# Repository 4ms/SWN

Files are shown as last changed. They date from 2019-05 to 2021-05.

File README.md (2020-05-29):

# Spherical Wavetable Navigator

Firmware for the Spherical Wavetable Navigator, a Eurorack-format module from 4ms Company.

## Setting up the gcc-arm toolchain
You need to install the GCC ARM toolchain.
This project is known to compile with arm-none-eabi-gcc version 8.2.1 (8-2019q4) and 7.3.1 (7-2018q2).

If you're new to embedded development and not comfortable on the command line, you may wish to install an IDE. ST has an official IDE based on Eclipse called [STM32CubeIDE](https://www.st.com/en/development-tools/stm32cubeide.html). Or you can roll-your-own Eclipse using [GCC ARM with Eclipse](https://gnu-mcu-eclipse.github.io/). There are also commerical software packages which can be easily found by searching.

Another option is to use a fully-featured text editor such as VSCode or Sublime Text. You can configure these to run commands to compile and flash/program your project onto your SWN, too. There are ARM debugging extensions available, too. On the other hand, if you're happiest using the command line and prefer to write code with vim, emacs, etc, you can also do everything without having to lift your hand from the keyboard except to twiddle knobs on the SWN.

### Using the Virtual Machine ###

4ms has a virtual machine that provides a consistant development environment for compiling. Check out this project and follow the instructions in its README: [4ms-dev-env](https://github.com/4ms/4ms-dev-env). The SWN repo comes pre-cloned when you start this virtual machine.

First, follow the instructions on [vagrant's site](https://www.vagrantup.com/intro/getting-started) to install vagrant and VirtualBox.

Then, building the SWN project is as simple as this:

```
git clone https://github.com/4ms/4ms-dev-env.git
cd 4ms-dev-env
vagrant up
vagrant ssh
cd SWN
make
```

At present, the 4ms-dev-env is only setup to compile, not to flash (program), or debug.
If you decide to use the virtual machine to compile, you'll still need to use your local system to program the compiled code onto SWN. Skip down to the **Programmer** section.

### Mac OSX using Brew ###

For Mac OSX, you can use brew to install the gcc-arm toolchain.
First, install brew if you haven't already:
```
ruby -e "$(curl -fsSL https://raw.githubusercontent.com/Homebrew/install/master/install)"
```

Then, install the gcc-arm toolchain v7.3.1:

```
brew tap nitsky/stm32
brew install arm-none-eabi-gcc
```

Continue below to **Clone the Projects**

Alternatively, you can follow the _Linux orMac OSX_ instructions below to get v8.2.1.

### Linux or Mac OSX ###

For Linux or Mac OSX, download GNU ARM Embedded Toolchain version 8-2018-q4-major from [Launchpad](https://launchpad.net/gcc-arm-embedded/+download).

Direct links: [Mac OSX gcc-arm 8.2.1](https://developer.arm.com/-/media/Files/downloads/gnu-rm/8-2018q4/gcc-arm-none-eabi-8-2018-q4-major-mac.tar.bz2) ... [Linux gcc-arm 8.2.1](https://developer.arm.com/-/media/Files/downloads/gnu-rm/8-2018q4/gcc-arm-none-eabi-8-2018-q4-major-linux.tar.bz2).

Then unzip them: Double-clicking them on MacOS might work, or type this:

```
cd ~/Downloads ##whatever your download directory is
tar jxf gcc-arm-none-eabi-8-2018-q4-major-*.tar.bz2
```

Next, move the unzipped directory to somewhere sensible and add the `bin/` dir to your PATH:

```
mv gcc-arm-none-eabi-8-2018-q4-major $HOME/myprojectdir
echo "export PATH=$HOME/myprojectdir/gcc-arm-none-eabi-8-2018-q4-major/bin:\$PATH" >> $HOME/.bash_profile
source $HOME/.bash_profile

```

Of course, modify the above with the actual directory you want to put the toolchain, and your shell start-up script if you're using zsh or something else.

Continue below to **Clone the Projects**

### Windows
Download the GNU ARM Embedded Toolchain version 8-2018-q4-major from [Launchpad](https://launchpad.net/gcc-arm-embedded/+download). Download the Installer for your Windows verion (don't download the .zip file, download the .exe file).

Run the installer, and continue below.

## Clone the Project ##

If you are using the virtual machine, this will already be cloned for you, so skip ahead.

Make sure git is installed on your system. (OSX: type "brew install git" into the Terminal).

Create a work directory, and enter it:
 
	mkdir myhackdir && cd myhackdir

Clone the SWN repository:

	git clone https://github.com/4ms/SWN.git  
	cd SWN

## Compiling ##
Make your changes to the code in the SWN directory. When ready to compile, make the project like this:

	make
	
This creates an main.elf, main.bin, and main.hex file in the build/ directory. See the Programmer section below for how to get these files onto your SWN.

## Programmer (Hardware) ##

Once you compile your firmware, you need to flash it to your SWN. You will need a hardware device that connects to your computer's USB port. The other side of the programmer has a header that conencts to the SWN's 4-pin SWD header.

You have several options:

### Option 1) ST-LINKv2 programmer ###

The [ST-LINK v2 from ST corporation](http://www.mouser.com/search/ProductDetail.aspx?R=0virtualkey0virtualkeyST-LINK-V2) is the offical programmer from ST (who makes the chip that needs programming). The ST-LINK v2 has a 20-pin JTAG header, and you need to connect four of these to your SWN. More details on this are below.

The ST-LINKv2 programmer can be used with ST-LINK software for Mac, Linux, or Windows; or ST-UTIL software for Windows; or STM32CubeProgrammer software for any platform. 

### Option 2) Discovery board programmer ###

The [STM32 Discovery boards](http://www.mouser.com/search/ProductDetail.aspx?R=0virtualkey0virtualkeySTM32F407G-DISC1) are low-cost (around US$25) and work great as a programmer and debugger. The 'Disco' board is essentially an ST-LINKv2, plus some extra stuff. While the ST-LINK v2 is encased in a plastic enclosure, the Discovery board is open and could potentially be damaged if you're not careful. Read the Discovery board's manual to learn about setting the jumpers to use it as an SWD programmer (rather than an evaluation board). ST makes many variations of the Discovery board, and to my knowledge they all contain an ST-LINK programmer.

The Discovery board programmer is essentially an ST-LINKv2, so it can be used with all the same software that the ST-LINKv2 can (see above section).

### Option 3) SEGGER's J-Link or J-Trace ###

Another option is [SEGGER's J-link programmer](https://www.segger.com/jlink-debug-probes.html). There is an educational version which is very affordable and a good choice for a programmer if you meet the requirements for education use. There are various professional commercial versions with a number of useful features. The J-link uses SEGGER's propriety software, Ozone, which not only will flash a hex or bin file, but can be used as a powerful GUI debugger if you use it to open the .elf file. There also are command-line commands for flashing.
J-Link software runs on Mac, Linux, and Windows.

### Option 4) Audio Bootloader ###

The SWN has an audio bootloader built-in, so you can just compile your project using `make wav` and then play the wav file into the audio input of the SWN while in bootloader mode (see SWN User Manual for detailed procedure). No additional hardware or software is necessary.

This works well and is the safest option. However it's very slow (up to 5 minutes per update, or 11+ minutes if you include all new factory wavetables). If you are going to be making a series of changes, this will be a very slow process!

When ready to build an audio file for the bootloader, make it like this:

	make wav

This requires python to run. It creates the file `main.wav` in the `build/` directory. Play the file from a computer or device into the SWN by following the instructions in the User Manual on the [4ms SWN page](http://4mscompany.com/SWN). 

## Programmer (Software)

Depending on the hardware you chose, one or more of the following software options will work:

### ST-LINK ###

This software works with the ST-LINK v2 and the Discovery board to flash your SWN.

__MacOS:__

```
brew install stlink
```

__Linux:__

Use your package manager to install `stlink-tools`. See [stlink README](https://github.com/stlink-org/stlink) for direct links.

__Windows:__

Download the [latest binary (v1.3.0)](https://github.com/stlink-org/stlink/releases/download/v1.3.0/stlink-1.3.0-win64.zip). If that link doesn't work anymore, or you want to try a newer version, go to [stlink-org/stlink github page](https://github.com/stlink-org/stlink).

__Programming using st-link__

You can flash the compiled .bin file by typing:

	st-flash write build/main.bin 0x08010000
	
This writes the main.bin file starting at the 0x08010000 sector, which is the first sector of the application code.

__Debugging__

The gcc-arm toolchain includes a gdb debugger, but you'll need a server to use it. The st-link software includes st-util which will provide this. OpenOCD and J-link are two other options. Configuring debugging is beyond the scope of this README, but there are plenty of tutorials online. See the [stlink README](https://github.com/stlink-org/stlink) for a quick start.

### J-Link/Ozone ###

If you're using a J-Link or J-Trace hardware programmer to flash your SWN, download and install [Ozone](https://www.segger.com/downloads/jlink). Ozone is a GUI debugger which can program, too. For command-line options, consider [J-Link Software and Documentation Pack](https://www.segger.com/j-link-software.html), which contains the GDB server and other tools.

To program your SWN, open Ozone and then use the Project Wizard to create a new project. Select the STM32F765ZG for the chip. Use the default settings elsewhere. On the page that lets you select a file, select the main.elf file that you compiled. You can then save this project. To program, just click the green power/arrow symbol at the upper left.

You also can use the CLI tools to flash the hex/elf file, see J-Link documentation for details.

J-Link and Ozone is available for Mac, Windows, and Linux.

### STM32CubeProgrammer ###

The STM32CubeProgrammer is ST's official programaming software available for all platforms. [You can find it here](https://www.st.com/en/development-tools/stm32cubeprog.html)

Documentation is included with the download.

### ST-UTIL (Windows only) ###

ST-UTIL is a program from ST that runs on Windows only. You can find it on [ST.com](https://my.st.com/content/my_st_com/en/products/development-tools/software-development-tools/stm32-software-development-tools/stm32-programmers/stsw-link004.html)

It works with the ST-LINKv2 and Discovery boards.

## Connecting the programmer to the SWN ##

**Discovery Board**: The Discovery board has a 6-pin SWD header, and you can connect that pin-for-pin to the first 4 pins on the SWN's SWD header. You can use a 0.1" spaced 4-pin Jumper Wire such as [this one from Sparkfun](https://www.sparkfun.com/products/10364). Pay attention to Pin 1 (marked by "1" on the SWN board), or you risk damaging the ARM chip.

**ST-LINK v2 or SEGGER J-Link**: Both the ST-LINK and the SEGGER J-link have a 20-pin JTAG connector. You need to connect 4 of these pins to the SWN's 4-pin SWD connector, using 4 wires: [here's a pack of 10](https://www.sparkfun.com/products/8430). Pay attention to Pin 1 (marked by "1" on the SWN board), or you risk damaging the ARM chip.
 
Look at these images:
 
  * JTAG: [20-pin pinout](http://www.jtagtest.com/pinouts/arm20)
  * SWD: [6-pin pinout](https://wiki.paparazziuav.org/wiki/File:Swd_header_discovery_board.png)
  * JTAG-to-SWD: [JTAG-to-SWD-pinout](https://4mscompany.com/JTAG-to-SWD-pinout.png). 

Then use your jumper wires to connect:
 
  * SWD pin 1 (VDD) -> JTAG pin 1 (VREF)
  * SWD pin 2 (SWCLK) -> JTAG pin 9 (TCK)
  * SWD pin 3 (GND) -> JTAG pin 4 (GND)
  * SWD pin 4 (SWDIO) -> JTAG pin 7 (TMS)

Here's more info in case you want it explained in another way:

  * [This image](https://www.alexwhittemore.com/wp-content/uploads/2014/08/schematic.jpg) draws this out. (Taken from [this post](https://www.alexwhittemore.com/st-linkv2-swd-jtag-adapter/))
  * [ST's manual](http://www.st.com/content/ccc/resource/technical/document/user_manual/70/fe/4a/3f/e7/e1/4f/7d/DM00039084.pdf/files/DM00039084.pdf/jcr:content/translations/en.DM00039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)
  * [How to make an adaptor](http://gnuarmeclipse.github.io/developer/j-link-stm32-boards/#the-st-6-pin-swd-connector)
  * Make your own adaptor from these gerber files: [JTAG-SWD-adaptor](https://github.com/4ms/pcb-JTAG-SWD-adaptor).

## Bootloader Information ##

The bootloader is in a folder called `bootloader/`.
It's based on the stm-audio-bootloader from [pichenettes](https://github.com/pichenettes/eurorack). 

The bootloader is already installed on all factory-built SWN, so you don't need to mess with this project if you're just planning on modifying your SWN code. The bootloader allows you to replace the firmware by playing a compiled audio file into the Waveform In jack.

Doing `make` from within the `bootloader/` directory will build the bootloader and also use the main SWN app's `main.hex` file to create a combined hex file. This file is a complete flash dump of a factory SWN. After building the SWN first, and then the bootloader, the file will be in `SWN/bootloader/build/bootloader-app-combo/`. There is a hex and a bin version in that folder.

__Oops, I overwrote the bootloader and now it won't boot...__

The bootloader lives at 0x08000000, so if you overwrite that sector you will overwrite the bootloader. And then it won't boot. The best way is to re-flash the bootloader. Do this:

	st-flash write bootloader/build/bootloader-app-combo/SWN_combo.bin 0x08000000
	
Or if the combo is not working, you could try just the bootloader:

	st-flash write bootloader/build/bootloader/bootloader.bin 0x08000000

## License ##

The code (software) is licensed by the MIT license.

The hardware is licensed by the [CC BY-NC-SA license](https://creativecommons.org/licenses/by-nc-sa/4.0/) (Creative Commons, Attribution, NonCommercial, ShareAlike).

See LICENSE file.

I would like to see others build and modify the SWN and SWN-influenced works, in a non-commercial manner. My intent is not to limit the educational use nor to prevent people buying hardware components/PCBs collectively in a group. If you have any questions regarding the license or appropriate use, please do not hesitate to contact me! 

## Guidelines for derivative works ##

Do not include the text "4ms" or "4ms Company" or the graphic 4ms logo on any derivative works. This includes faceplates, enclosures, PCBs, and front-panels. It's OK (but not required) to include the text "Spherical Wavetable Navigator" or "SWN" if you wish.

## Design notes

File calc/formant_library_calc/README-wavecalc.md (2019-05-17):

#formant-library-calc
## Formant calculator for wavetables
Authors: Hugo Paris hugoplho@gmail.com, Dan Green danngreen1@gmail.com

Coefficients from:
HTML Csound Manual - © Jean Piché & Peter J. Nix, 1994-97 

https://www.classes.cs.uchicago.edu/archive/1999/spring/CS295/Computing_Resources/Csound/CsManual3.48b1.HTML/Appendices/table3.html

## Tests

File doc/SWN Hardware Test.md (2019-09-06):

#SWN Hardware Test
March 1, 2019

###Preparation

####Enter Hardware Test mode:

   1. If module has never passed the hardware test, it will automatically enter this mode until it passes.
   2. If it’s already passed, then hold down Button D + Transpose + LFO Shape while powering on.

####Prepare Scope:

* ⅛” tester cable
* “Normal” Time Mode (Horiz button)
* Horizontal: 2ms/div
* Channel’s Vertical: 5V/div
* Auto Trigger on the tester cable’s channel
* Trigger threshold at 50%
* Measurement enabled for Frequency and Amplitude

Prepare speakers/headphone to listen to what’s being scoped.

###Slider LED Test
1. Press center rotary to test each slider LED, one a at time. After the sixth press, all six sliders turn on at the same time.
2. Verify brightness/color.
3. Push the sliders to center now (you’ll see why in the Controls test).
4. Press rotary again to go to next test.

Note: It’s OK if the rest of the RGB lights are partially on/off: they don’t get tested until the next step.

_Fail_: "Slider LED" if a slider LED does not turn on or is always on, or two slider LEDs turn on at the same time. 

_Fail_: "Slider LED discolored" if a slider LED is substantially different hue than other slider LEDs.

###RGB LED Test

####Part 1: PCA I2C check
SWN automatically performs PCA chip communication test on I2C bus.

_Fail_: “PCA I2C Timeout”, if sliders E and F blink and sliders A/B/C/D show binary code for chip# that failed. Record fail and press rotary to continue. Otherwise, it automatically goes to Part 2.

####Part 2: All LEDs check
All light pipes, buttons, and rotary LEDs will turn white (Clock In LED will be blue and LFO buttons will be pink-ish).

_Fail_: “LED out”, if an LED is not white, or excessively dim or bright.

If it detects an error, it will automatically go to Part 3. Otherwise, you must make a choice here: 

  * If the lights definitely look good, the press the rotary to skip to Controls Test. 
  * If you want to double-check an LED individually, hold the rotary for 3 seconds unti the sliders flicker. Then release to go to Part 3 (individual LED test). 

####Part 3: Individual LED test (optional): 
Spin center rotary or Preset rotary to select one LED at a time to turn on. Each Red/Green/Blue is turned on separately.

_Fail_: “LED out/LEDs shorted”: If there’s any point in time when there are no LEDs on, or there are more than one LEDs on (including any color other than pure red, pure green, or pure blue). Note that you can use either the Preset rotary or the center rotary: you may not be able to conduct this test if there are issues with both of these rotaries. 
Press center rotary to continue to next test.

###Controls Test (rotaries, sliders, buttons, switches)

Staring state:

* Channel buttons are white (might be cyan or magenta if a slider is not centered)
* LFO buttons are blue
* LFO LEDs and LFO CV LED are white
* LED encoders are white

The goal is to turn all the lights off by pushing every button, turning every knob, moving every slider, and flipping the switch.

1. Slide each slider up and down fully:
   * Slider light should turn on when slider is >50% up (40-60% is ok)
   * Slider light should turn off when slider is <50% up (40-60% is ok)
   * Button above slider turns its red off when slider hits 100% (white=>cyan)
   * Button above slider turns its green off when slider hits 0% (cyan=>blue)

1. All 8 buttons should be blue now. Press each button to turn the blue color off.
2. For each rotary:
   - Each Rotary has an LED associated with it:
      * Octave: LFO LED B
      * LFO Speed: LFO LED A
      * Preset: LFO LED C
      * Depth: Depth (itself)
      * Center: LFO LED D
      * Latitude: Latitude (itself)
      * Longitude: Longitude (itself)
      * LFO Shape: LFO LED F
      * Transpose: LFO LED E
   - Turn it up and the light will turn cyan
   - Turn it down and the light will turn blue
   - Push its button and the light will turn off
   - While turning, watch light ring to make sure it’s not skipping steps
3. Press Fine to turn off the red color of the LFO CV LED (white=>cyan)
4. Flip V/oct switch up to turn off the green color of the LFO CV LED (cyan=>blue)
5. Flip V/oct switch down to turn off the blue color of the LFO CV LED (blue=>off)
6. Verify all lights are off.

  - _Fail_ “Rotary skipping” if light ring animation skips around when turning rotary.
  - _Fail_ “Rotary not responding to turning” if a rotary’s light is staying on any color except pure blue.
  - _Fail_ “Button not responding” if a button or rotary’s light is staying on pure blue.
  - _Fail_ “Fine button not responding” if LFO CV LED won’t turn off its red color
  - _Fail_ “Voct Switch stuck high/low” if LFO CV LED won’t turn off its blue/green color
  - _Fail_ “Slider not reaching max/min” if channel button won’t turn off its red or green color
  - _Fail_ “Slider voltage issue” if slider doesn’t turn on/off at about 50%
  - _Fail_ “Button/Rotary/Switch/Slider shorted” if multiple things happen when you adjust one control.

Hold down center rotary 3 seconds to proceed to next test. Sliders will flicker when it’s ok to let go

###Codec Communication Test
Automatic test (no user input required unless there’s a problem):

1. Waveform In LED turns blue while it tests the SAI initialization.
   - _Fail_ “Codec SAI error”, if slider F blinks quickly and Waveform LED is blue.
2. Waveform In LED turns red while it tests the I2C initialization.
3. Waveform In LED turns green while it tests the I2C communication.
  - _Fail_ “Codec I2C init error” if slider E blinks slowly and Waveform LED is green.
  - _Fail_ “Codec I2C register error”, if slider E blinks quickly and Waveform LED is green.

4. If there's an error, press rotary to continue, otherwise it automatically goes to next test.

###Outputs Test: Audio and LFOs

LFO LEDs will be Red/Green/Blue/Yellow/Cyan/Magenta

1. Patch scope and speakers into each Env jack and verify (approximate semi-tones):
   * Env A outputs a 248Hz left-leaning triangle, 7.2V amplitude.
   * Env B outputs a 257Hz left-leaning triangle, 7.2V amplitude.
   * Env C outputs a 287Hz left-leaning triangle, 7.2V amplitude.
   * Env D outputs a 313Hz left-leaning triangle, 6.8V amplitude.
   * Env E outputs a 342Hz left-leaning triangle, 6.8V amplitude.
   * Env F outputs a 360Hz left-leaning triangle, 6.6V amplitude.

2. Patch scope and speakers to Right OUT jack output. Scope should be measuring Freq and Amplitude.
3. Should see ~100Hz triangle with faster rise than fall (left-leaning). Amplitude = about 10V
  - _Fail_ “Audio Out amplitude too high/low” if amplitude is over/under 9.5V or 10.5V (or clipping)
  - _Fail_ “Audio OUT frequency” if wave is not between 99Hz and 101Hz,
  - _Fail_ “Audio OUT noisy/distorted” if you see noise or its distorted.
  - _Fail_ “Audio OUT DC offset” if wave is not centered around 0V.
  - _Fail_ “Audio OUT inverted” if wave is right-leaning

4. Patch a dummy cable into Left OUT jack. Immediately audio should go silent. This is because the normalization between Left and Right OUT jacks is broken by pluggin into the Left jack.
  - _Fail_ “Audio jack normalization issue” if right out jack is not silent when a cable is patched into left out (make sure nothing is patched into Waveform In, or it’s not really a failure).

5. Patch other end of the cable into Waveform In jack.  Should see inverted waveform (right-leaning), with amplitude = 19V
Do troubleshooting below if clipping, or amplitude < 18V, or no signal at all.

####Audio Test troubleshooting steps: 
Background Info: The Audio Test code copies the signal on the codec’s input to the codec’s right output (which goes to the Right OUT jack). The code also generates a 100Hz left-leaning triangle and outputs that on the codec’s left output (which goes to the Left OUT jack). The Left OUT jack’s switch lug is connected to the Right OUT jack’s signal lug, so if the Left OUT jack is unpatched, the Right OUT jack will play a 50/50 mix of the triangle wave and whatever’s on the Waveform In jack. This 50/50 mix means the amplitude of the left-leaning triangle will be halved. Also, the Waveform In’s analog circuitry has a low-pass filter whic makes -3dB at 3kHz, -6dB (50% of amplitude) at 6kHz, etc.

#####Additional tests if a fail was discovered:
1. Patch scope directly to left OUT jack. You should see the 100Hz triangle (with faster rise than fall) at 19.7V amplitude and no clipping. If so, then you know the codec is working and the left output channel is working. 
  - _Fail_ “Audio Left OUT no output” if no 100Hz signal on Left OUT jack.
  - _Fail_ “Audio Left OUT distorted/amplitude/clipped/offset” if signal is present but has an issue.

2. Patch a 100Hz sine wave into Waveform In jack. Patch a dummy cable into Left OUT jack. You should see the sine wave on Right OUT jack with a little more amplitude (input a 10V, 100Hz sine, it’ll output 10.2V amplitude sine). If so, then you know the input stage and right output stages are working. Since there is a LPF, if you use a frequency higher than 100Hz you may start to see some attenuation. At 6kHz you should see 50% of the input amplitude, for example.
  - _Fail_ “Audio IN or Right OUT not working” if signal doesn’t pass from Waveform In to Right OUT

When confirmed audio and LFO outs, press rotary to continue to next test.

###External ADC Chip Test
This is an automatic test and only stops if there’s a problem.

All lights turn off. The LFO LEDs and inner ring LED A (upper right) turn pure blue.

ADC chip 1 and 2 are automatically initialized.

  - _Fail_ “ADC chip 1 SPI fail” if slider A is blinking.
  - _Fail_ “ADC chip 2 SPI fail” if slider B is blinking.

The ADC channels are tested to verify the reading is close to 0 when no cable is patched into the jack. When a jack (ADC channel) passes the test, its light will turn off. 
If any 1V/oct jack ADC channel fails, then the corresponding LFO light will stay blue. If the Transpose jack ADC channel fails, the inner ring A light (upper right) will stay blue.

  - _Fail_ “1V/oct jack ## (or Transpose jack)” if one of the LFO or inner ring lights is staying blue.

If there’s an error, press rotary to continue.
Otherwise, if there’s no error then it automatically goes to the next test.

###Input Jacks Test
It will flash all LEDs green briefly while it sets up the internal ADCs to read the remaining CV jacks. 

Immediately, all green lights should turn off. If a green light is on, the ARM chip is not reading 0V on the corresponding jack. (Make sure no cables are patched)

  - _Fail_ “Internal ADC init error”: if it hangs with lights green. You must reboot after this, you cannot continue.

Check all the lights

  * LFO LEDs are flashing white
  * Clock In and Waveform In LEDs blue
  * Top row of buttons purple
  * LFO->VCA button blue
  * LFO Type button hot pink
  * 9 lights red: LFO CV, 5 on the inner ring, and the 3 LED rotaries
  * 1 light purple: Inner ring A (upper right)

###Input Jack Testing Procedure

1. Patch LFO A into Clk In jack: Clk In light should flash to tempo.
  * LFO->VCA button should turn off when jack is sensed as plugged in. 
  * Unplug and Clk In and LFO->VCA button lights should go off and stay off

2. Patch any cable into Waveform In jack: blue light should turn off and stay off
3. Plug LFO A into each CV jack, one at a time:
  * Each CV jack has a light associated with it. 
     - Channel 1V/oct jacks -> channel buttons at top
     - Transpose jack -> LFO Gate/Trig/Shape button.
     - Depth CV -> Depth rotary
     - Dispersion CV -> Inner ring D (lower left)
     - Browse CV -> Inner ring E (middle left)
     - Sphere CV -> Inner ring F (upper left)
     - LFO CV -> LFO CV light
     - Dispersion Pat. -> Inner ring C (lower right)
     - Latitude CV -> Latitude rotary
     - WT Spread CV (above Longitude knob) -> Longitude rotary
     - Spread CV (below Transpose) -> Inner ring B (middle right)

 * Watch the jack’s corresponding light when you patch, it should rapidly flash blue and turn off blue when you unpatch. It should also turn off red when a 5V signal is measured. When you unpatch, its light should stay off.

 * Watch the outer light ring when you patch, it will show the waveform.

      - For the non-1V/oct jacks, each of the 18 lights on the outer ring should be white at some moment.
      - _Fail_ “CV jack [name] bad range if it doens’t turn on all 18 lights (or 17 is ok) or if it sticks at light 18 or light 1 for more than a flicker.

      - For the 1V/oct and Transpose jacks, only the right half of the lights will be covered by the waveform. 
      - _Fail_ “1V/oct [channel#]/Transpose jack bad range” If it covers, more or less than 9 lights

4. Inner Ring light A (upper right) is the BUS CLOCK and BUS SELECT light.
  * Red will be on until it receives a clock pulse on the bus
  * Green will be on if the clock bus is stuck at high
  * Blue will be on if a pulse is received on the select bus
  * If you can’t test the Bus, then the light will be purple (red+blue) until it receives a pulse on either bus. _Fail_ “Clock Bus stuck high” If it’s white (red+blue+green)

  * If you can test the Buses, tap a QCD and the light will turn blue. _Fail_ “Clock Bus not receiving” if it stays purple, yellow or red.
  * If you can test the Select Bus, send any program change message (it happens automatically every few seconds with some modules). Blue light should turn off. _Fail_ “Select Bus not receiving” if the blue light won’t turn off.

When done testing every jack, every light should be off except for the 6 white flashing LFO OUT lights. Press the center rotary to continue.

###External Flash Chip Test
The final test is automatic and only pauses for user interaction if there is a failure.
Erase/Write/Read ext FLASH (sectors before Wavetables)

  - _Fail_ “External Flash init error” if it’s blinking slider D.
  - _Fail_ “External Flash read/write error” if it’s blinking slider C.
If there’s no error, it’ll just keep going.

###Success!!!!
You will see an animation of all the lights in red, green, and blue if there was success. 
The final step is to reboot. 
The first boot after hardware will take longer than normal because the wavetables are being copied to flash.

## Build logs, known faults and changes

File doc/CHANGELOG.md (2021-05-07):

# Spherical Wavetable Navigator

## Firmware updates

### Where to get updates
You can always download the latest updates at the [4ms Company SWN page] (https://4mscompany.com/SWN).

### How to tell what version you have
When the module powers on, the version is displayed with a red and blue light on the light ring. 
The red light on the inner rings shows the major version.
The blue light on the outer ring shows the minor version. For example if the version is 1.2 then the major version is 1, and the minor version is 2.

On the outer light ring, if you imagine it as a clock face, the light just to the right of 12:00 is 0. The next light going around clockwise is 1. Then next light clockwise is 2, etc. The inner ring counts the same but it starts at 1 (and goes to 6). If you would like a picture to help visualize this, see the [SWN User Manual](https://4mscompany.com/media/SWN/manual/SWN-manual-2.2.pdf), page 39.

#### Changes in v2.2.1:

Released May 8, 2021

  * Bug Fix: After deleting a User Sphere, it could still be selected and loaded until the unit is rebooted. Fixed.
  * Bug Fix: Fine tuning was not immediately applied after loading a preset (previously you had to adjust Fine Tune or Fine Tune Spread after loading a preset to force it to update). Fixed.

#### Changes in v2.2:

Released Oct 12, 2020
  
  * CV/Gate/Sustain mode added:
    * Similar to CV/Gate mode, but envelopes are sustained if gate is sustained
    * Channel A uses Sphere CV jack instead of Waveform In jack

  * Channel Panning
    * Each channel can be panned Left/Right by holding down channel button and moving the channel slider
    * Volume setting is cached and only updated when slider returns to original position
    * Pan settings are saved and recalled with presets
  
  * Select Bus
    * SWN will respond to Select Bus commands to load or save presets
    * Loading and/or saving can be disabled by holding down Preset and channel B button, and then pressing the small LFO buttons to enable or disable Loading (green LFO->VCA button) or Saving (red LFO Type button)
    * Settings are saved after power down
    * Responds to verbose style commands (e.g. Malekko Varigate) and terse style (e.g. Makenoise Rene mk2)
 
  * SWN now boots up into the last preset that was saved or loaded.

  * Bug Fix: after clearing a User Sphere, it previous would still show in the list of wavetables until reboot. Fixed.

#### Changes in v2.1:

Released July 16, 2019

  * Chords in the list of chords (Spread knob or CV) have been modified:
    * Chord 9: First note lowered by one semitone to make a minor third.
    * Chord 17: Top note lowered three semitones to make a major 9th.
    * Chord 18: Top two notes lowered three semitones to make a major 11th.
    * Chord 25: Top note lowered three semitones to make a minor 9th.
    * Chord 26: Top two notes lowered three semitones to make a minor 11th.

  * Spread CV response changed so you can select any of the 26 chords with the black keys on a keyboard (C#0 to C#5)
 
  * Spread knob had a bug where sometimes turning clockwise from the first chord would go to chord 25, instead of 26.
  
#### New features in v2.0:

Released July 12, 2019

  * __CV/Gate Mode__: New mode allows you to patch gate signals into the CV jacks to trigger each channel's envelope. CV/Gate mode is designed for connecting a CV/Gate keyboard or sequencer: up to seven CV/Gate channels can be connected (six channel + one global).
    * To enter CV/Gate Mode: Press the two small buttons to switch from Mute Mode -> Note Mode -> Keyboard Mode -> CV/Gate Mode. The buttons will be dim orange in this mode.
    * CV/Gate mode is exactly like Keyboard Mode except that each channel's envelope can be fired by sending a gate or trigger into the a CV jack. When a cable is patched into a channel's V/oct jack, another jack will be re-purposed as a gate/trig jack for that channel:
       * Channel A's trigger: Waveform In jack
       * Channel B's trigger: Dispersion CV jack
       * Channel C's trigger: Depth CV jack
       * Channel D's trigger: Dispersion Pat. CV jack
       * Channel E's trigger: Latitude CV jack
       * Channel F's trigger: WT Spread CV jack
       * Global trigger: Spread CV jack
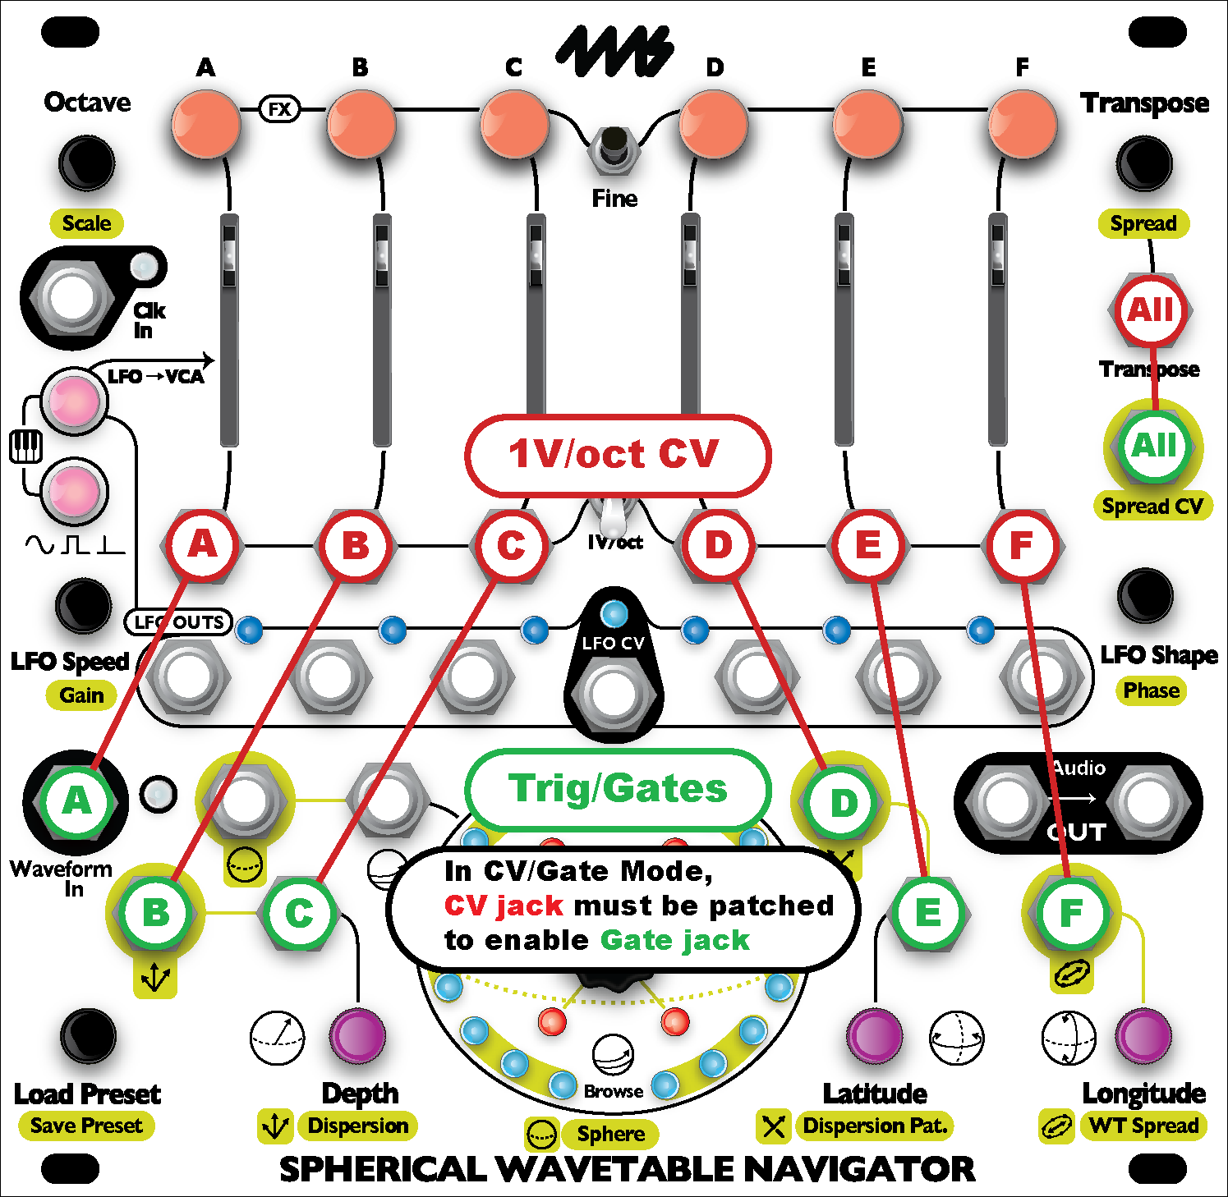
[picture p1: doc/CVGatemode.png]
(CV Gate Mode jacks)
       * 

    * Note that in CV/Gate mode you can still use a CV jack for its primary feature if you either 1) don't plug into the associated 1V/oct jack, or 2) set that particular channel to Mute, Note, or Keyboard mode. For example, if you only patch 1V/oct CV into Transpose and a gate into Spread CV, then the CV jacks at the bottom will all retain their original purpose (Dispersion, Depth, etc..) 
    * A subtle difference between CV/Gate Mode and Keyboard mode is that pressing the buttons in CV/Gate mode will play the entire envelope even if you let go of the button early. In Keyboard mode, the envelope stops immediately when you release the button.
    * Like Note/Keyboard/Mute modes, you can have some channels in CV/Gate mode, and some in other modes. At least one channel has to be in CV/Gate mode to use Spread CV as a global trigger (and Transpose CV has to be patched).
    * All of the scale modes work in CV/Gate mode, including unquantized (light blue). It's up to you if you want your keyboard/sequencer to quantize, or your SWN, or both. Each channel can have a different scale selected as well.
    * Tip: If you're using a sequencer, you might want to patch its clock out into the SWN's Clk In jack so the envelope timings will be synced.

  * __Consistent Phase adjustments__: LFO Phase is now adjusted by in steps of 1/24 of the main clock. Previously it used a sequence of ratios which caused small timing differences when globally shifting the phase of all channels with respect to an external clock. LFO Fine Phase is still 1/12 of (Coarse) Phase, so it adjusts 1/288 of a measure per click.
  * __Shorter Envelopes__: Envelopes in Note and Key mode are now allowed to go much shorter.

#### New in Firmware v1.2 (not released publicly):

  * __Export Sphere__: in Sphere Recording Mode, enable Monitoring by pressing the green button. Then tap the center knob to export the sphere out the audio jack.
     *  You can use this to transfer your sphere to another SWN by patching the output of your SWN to the other SWN which is set to record a Sphere. 
     *  Or you can use this to backup a Sphere by recording the audio with a WAV Recorder, sampler or other audio recording device.
     *  Or you can record onto a WAV Recorder or computer and then open the file in SphereEdit.
  * __Record single waveform__: Pressing Fine + Record in Sphere Recording Mode will record over the current waveform only.
  * __Channel Locks__: press Fine + any channel button to lock/unlock a channel. 
     * The button flashes when a channel is locked, and the channel's light(s) will flash on the light ring.
     * Locked channels will not respond to any global parameter changes.
     * Locked channels will still respond to individual channel parameter changes (holding the channel button and turning a knob)
  * __Sphere Selection display__: When changing the Sphere (push and turn center knob), the outer light ring will display which channels are assigned to which Spheres (similar to the Octave display). The channel buttons will also change to the color of the channel's Sphere. Turning the WT Spread knob also activates this display. Tapping the center knob will show this display, too (useful for visualing the signal on the Sphere CV or WT Spread CV jacks). 
  * __Load/Clear Sphere__: In Sphere Recording Mode, turning the Preset knob allows you to load and clear Spheres in the same way you load presets (tap and tap again to load; hold for 8 seconds and then tap to clear). Cleared Spheres can be uncleared by immediately doing the clear button press.
  * __Enable/Disable Sphere__: In Sphere Recording Mode, turn the Preset knob to select a Sphere. Tap the WT Select knob to disable the selected Sphere. The sphere's light on the outer ring will flash rapidly to show it's disabled. 
     * To re-enable the sphere, do the same thing again.
     * When you exit Sphere Recording mode, disabled Spheres will not show up when selecting Spheres or using WT Spread. 
     * The set of enabled/disabled Spheres is saved in the Presets. So you can enable/disable different sets of Spheres to be used with each Preset. 
  * __Reset Nav/Sphere__: Press Preset + Depth to reset navigation (browse/lat/long/depth). Press Preset + Latitude to reset Sphere selections. You can still press Preset + Depth + Latitude to reset both navigation and sphere selection (just like in version 1.0 and 1.1)
  * Octave range is now -3 to +14 (formerly was 0 to +14).

#### Bug fixes:

  * Bug where LFO Speeds would be set to super slow speeds if LFO CV jack goes from high to low rapidly.

#### Improvements:

  * Setting each channel to a different octave, and then turning global octave all the way up or down, and then back to the original position does not clear the intervals between channels (just like how Transpose has always worked)
  * WT Spread now offsets the channels in a more consistant way by adding increasing amounts of space between channels.
  * LED display tuned so that turning knobs always has an immediate effect, even if all CV jacks are being used with rapidly changing CV

### Firmware v1.1
Released May 20, 2019

#### Bug fixes:

  * Fixed zippering sound when level changes rapidly (from internal or external LFO with sharp attack or decay).
  * Fixed position of white light on the outer light ring that shows which channels are not detuned. Bug only appeared when some channels were detuned and others were not detuned.
  * Fixed color of inner ring lights in Sphere Recording Mode for showing which waveform in the Sphere is selected. 
  * Fixed issue where loading a preset that contained a Scale would not refresh the channel pitches.

#### Improvements:

  * Softer distortion when clipping on the Waveform In jack
  * When entering Sphere Recording Mode, waveform 0,0,0 is selected and any Latitude, Longitude, or Depth offset is cleared. This ensures that Browsing will move through waveforms in the same order that they've been recorded.
  * When the SWN is showing the transpose/spread display, and mute buttons are pressed, the buttons now immediately show the new mute state.
  * Transpose/Spread display goes back to normal display mode more quickly.

### Firmware v1.0
  
Released May 3, 2019
  
First public version.

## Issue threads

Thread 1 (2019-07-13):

compile error in bootloader with latest commit (12th July 2019)

forestcaver, 2019-07-13:
compile error in bootloader with latest commit (12th July 2019)

Code was removed in "WIP: DMA of I2C” update of
..../SWN/inc/drivers/pca9685_driver.h

(It’s a trivial one line code change to fix)

-----8<-----

bootloader.cc: In function 'int main()':
bootloader.cc:314:2: error: 'LEDDriver_Init' was not declared in this scope
  LEDDriver_Init(10);
  ^~~~~~~~~~~~~~
bootloader.cc:314:2: note: suggested alternative: 'LEDDriver_init_dma'
  LEDDriver_Init(10);
  ^~~~~~~~~~~~~~
  LEDDriver_init_dma
Makefile:144: recipe for target 'build/bootloader/bootloader.o' failed
make: *** [build/bootloader/bootloader.o] Error 1

danngreen, 2019-09-05:
Thanks for the find! I corrected it and pushed the fix
Note: it actually should be
`LEDDriver_init_direct(10);`
Not
`LEDDriver_init_dma(10);`

forestcaver, 2019-09-06:
Thanks Dan - yes, that’s what I’ve been using in my boot loader !

Amazing module by the way !!! Been playing with it heaps today !
Trying to think of any improvements - I’ve been combing through the code but the UI is pretty dense as it is :-)
Just wondering about normalling v/oct of A channel to the others to add with the lfo inputs as cv to create chords….

Thanks
Andy

Ps (I was finishing the module when I realised one of my first ever diy builds, years ago, was the tremulus lune
- drew the pcb tracks with a sharpie and etched it - didn’t have a clue what I was doing but I still use that pedal today :-) )

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

Closed 2019-09-05.

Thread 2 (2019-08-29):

Schematic incorrect (pdf and kicad) lists stm32 as STM32F42xZ

forestcaver, 2019-08-29:
As of 29/8/19 v1.1 hardware:

Schematic (pdf and kicad) lists stm32 as STM32F42xZ (pcbs, Makefile and BOM export list it as STM32F765ZGT)

danngreen, 2019-09-05:
That's correct, the kicad symbol name is STM32F42x, and it's identical to the F765 but should be named properly. I fixed it.

Closed 2019-09-05.

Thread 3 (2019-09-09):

Compiles with arm-none-eabi-gcc 7.3.1 on ubuntu, but hangs when run

danngreen, 2019-09-09:
On Ubuntu 16.04, using gcc-arm-embedded from ppa:team-gcc-arm-embedded/ppa (version 7.3.1), the code compiles without issues.

The bootloader appears to work fine, but the main app hangs immediately upon being started from the bootloader.

The issue appears with commit 39d6fab113f356f796507086782fe434fc8db351
Commits before this seem to be working OK.

danngreen, 2019-09-09:
Thanks @forestcaver for reporting this

tsointsoin, 2020-04-11:
Is there any solution for this issue ? I just stumbled upon it.

danngreen, 2020-05-29:
I created a vagrant based virtual machine, that works when compiling. It uses gcc-arm 8.2.1. Apparently the order of the objects when linked can cause the issue. Which is odd because there is never a compile or link error, just a runtime error. The runtime error appears to be that the I2C bus does not respond when initializing the PWM LED drivers.

You'll need vagrant installed, and VirtualBox (or similar)

Here it is, instructions are in the README:
[https://github.com/4ms/4ms-dev-env](https://github.com/4ms/4ms-dev-env)

@tsointsoin @forestcaver If you have a chance to try this, can you let me know if this works for you?

tsointsoin, 2020-05-29:
Thank you so much. It works for me, from within the Vagrant VM. Also I could compile and run my code with gcc-arm-none-eabi=15:8-2019-q3-1 using your new Makefile within my own system (Debian SID) which was not working before. The Swan boots and seems to be fully functional but the generated wavefile doesn't have the same length (Vagrant : 15982340 bytes / Debian : 15981980 bytes) for the same code.

danngreen, 2020-05-29:
Great! Glad it works for you too.
The size difference is probably due to small variations in how gcc-arm 8-2019-q3 and gcc-arm 8-2019-q4 optimize the code.

danngreen, 2022-01-25:
Got to the bottom of this! Thanks @LnnrtS for your help
The linker script was allowing the const data (.rodata section) get loaded at the wrong address. The ld linker increments the LMA and VMA counters separately, and there are apparently some situations in which it'll discard data from one but not the other. The result is that the difference between them is not constant. This of course wrecks havoc when the code expects a static variable to be found at one location, but some other data is there instead. The gnu ld linker has a flag `ALIGN_WITH_INPUT` which forces the LMA and VMA to stay in sync (constant difference).

Background: the SWN runs code from FLASH by utilizing the prefetch and ART accelerators via the ITCM port. However this bus doesn't allow writing to the FLASH memory. So when you "flash" the SWN, the firmware file must be loaded via the AXI port to reach the FLASH memory. The AXI bus is accessed using addresses starting with 0x08000000. The ITCM port uses addresses starting with 0x00200000. So in order to do this, the SWN code is linked using load addresses (LMA) starting at 0x08000000 and run-time addresses (VMA) starting at 0x00200000. Since 0x0800'0000 + X is physically the same piece of memory as 0x0020'0000 + X (just accessed via a different port), the linker must strictly keep the load and runtime addresses in sync. I'm still not sure *why* the linker got out of sync (or on a deeper level: why it's even allowed to let these get out of sync), but the flag fixes it.

Closed 2020-05-29.

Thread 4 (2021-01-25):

Disparity for 4k7/10k resistors between schematic and PCB

tumes, 2021-01-25:
I'm mid way through a build and I just wanted to clear up a little confusion I was going through. There are quite a few resistors (mostly surrounding the encoders) which are labeled as 4k7 in the schematic but show as 10k on the PCB (R44 is one example, but there are 27 instances in the global control schematic). The BOM I purchased from assumed that the PCB was correct (i.e. that those are 10k), but I wanted to confirm one way or another so I can swap them out if necessary.

Thanks for your help and for releasing this for the DIYers, it has been a blast to assemble!

tumes, 2021-01-25:
I think I answered my own question thanks to the tremendously high res product photos you have on your web store. Seems like they are supposed to be 10k. I'll try to get a PR together to correct that later tonight if I can carve out some time.

tumes, 2021-01-25:
Addressing this in #5 and closing.

Closed 2021-01-25.

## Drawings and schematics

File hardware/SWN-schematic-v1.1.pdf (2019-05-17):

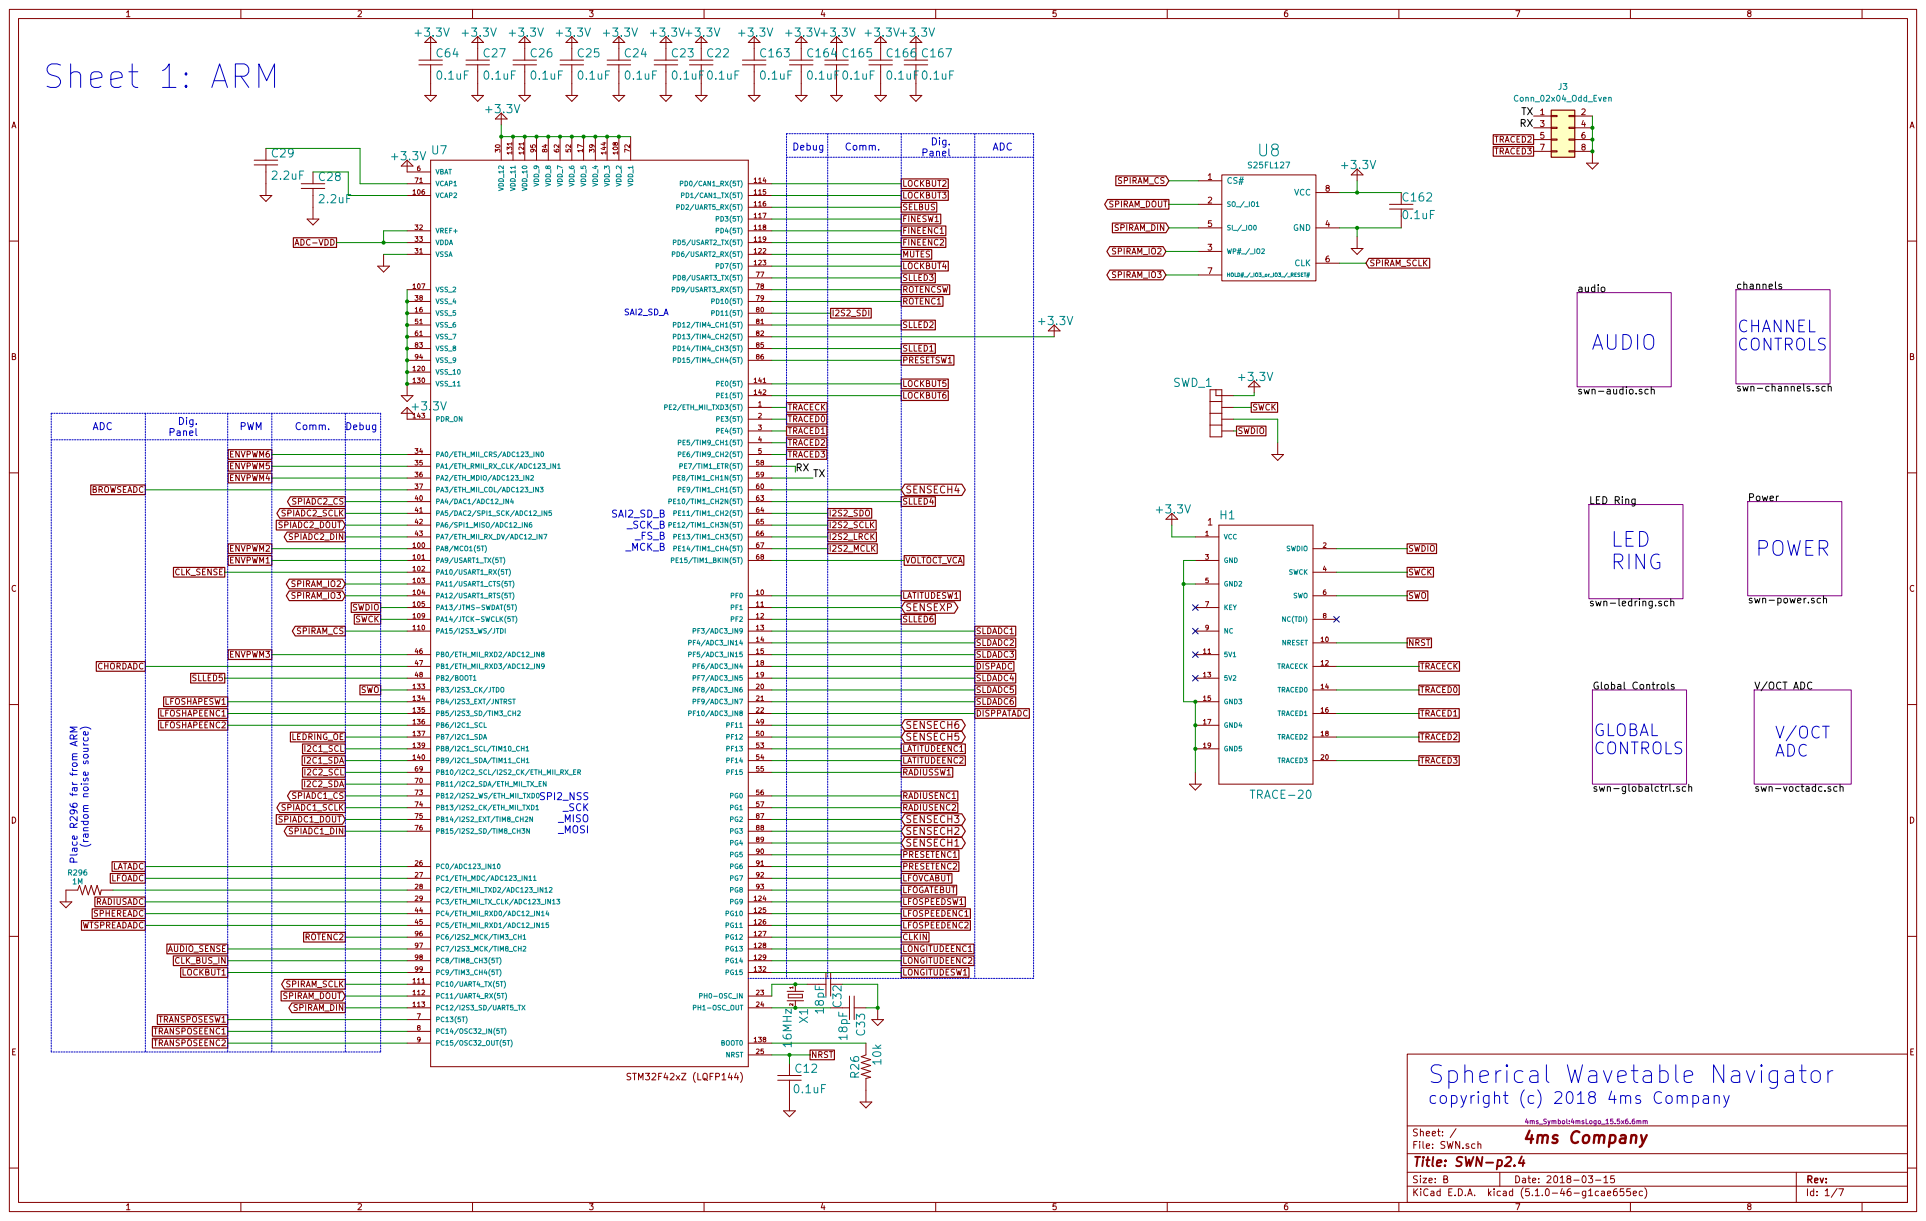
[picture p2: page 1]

swn-channels.sch Global Controls
swn-audio.sch

swn-voctadc.sch V/OCT
ADC

File: SWN.sch Sheet: / Spherical Wavetable Navigator
copyright (c) 2018 4ms Company

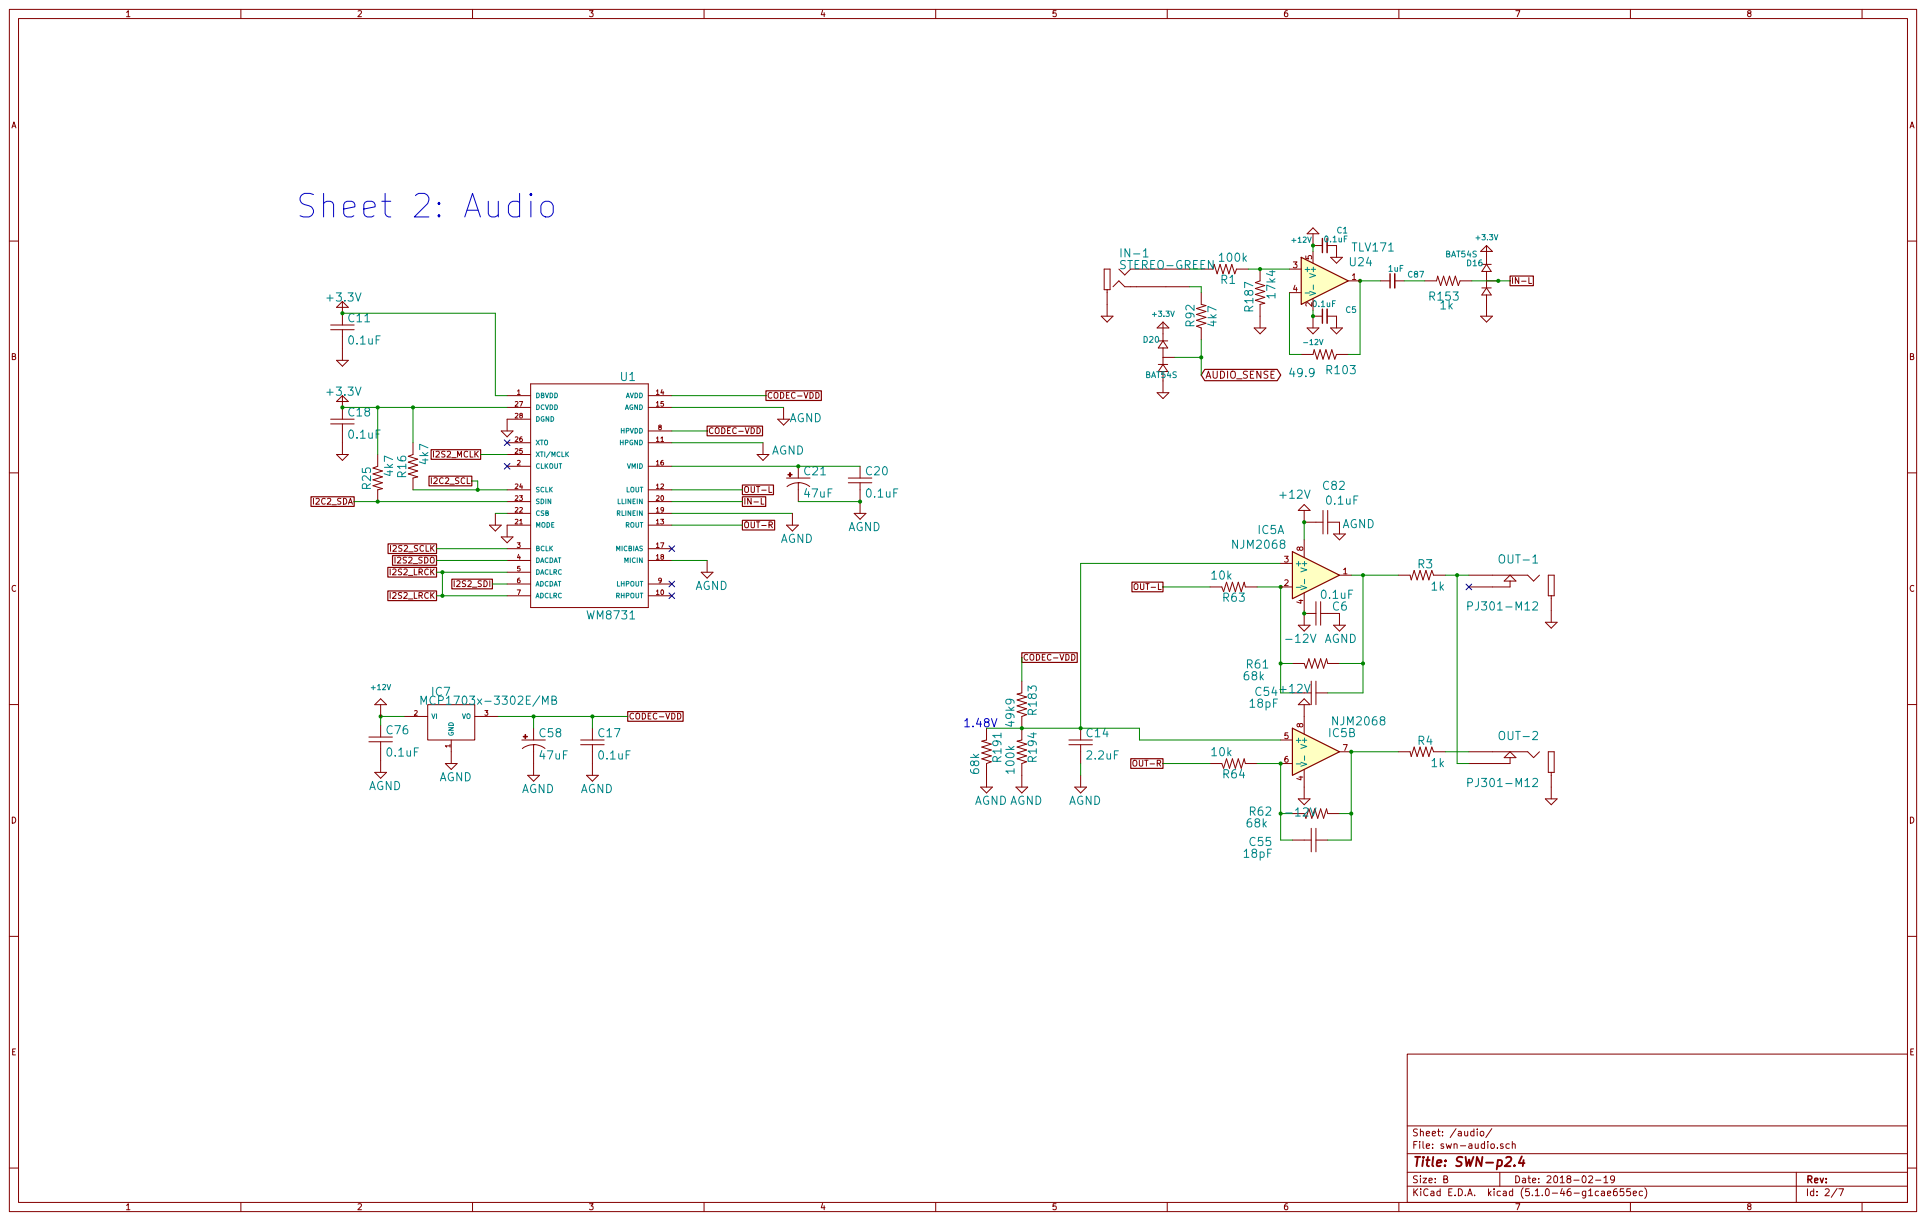
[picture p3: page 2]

File: swn-audio.sch Sheet: /audio/ 1.48V

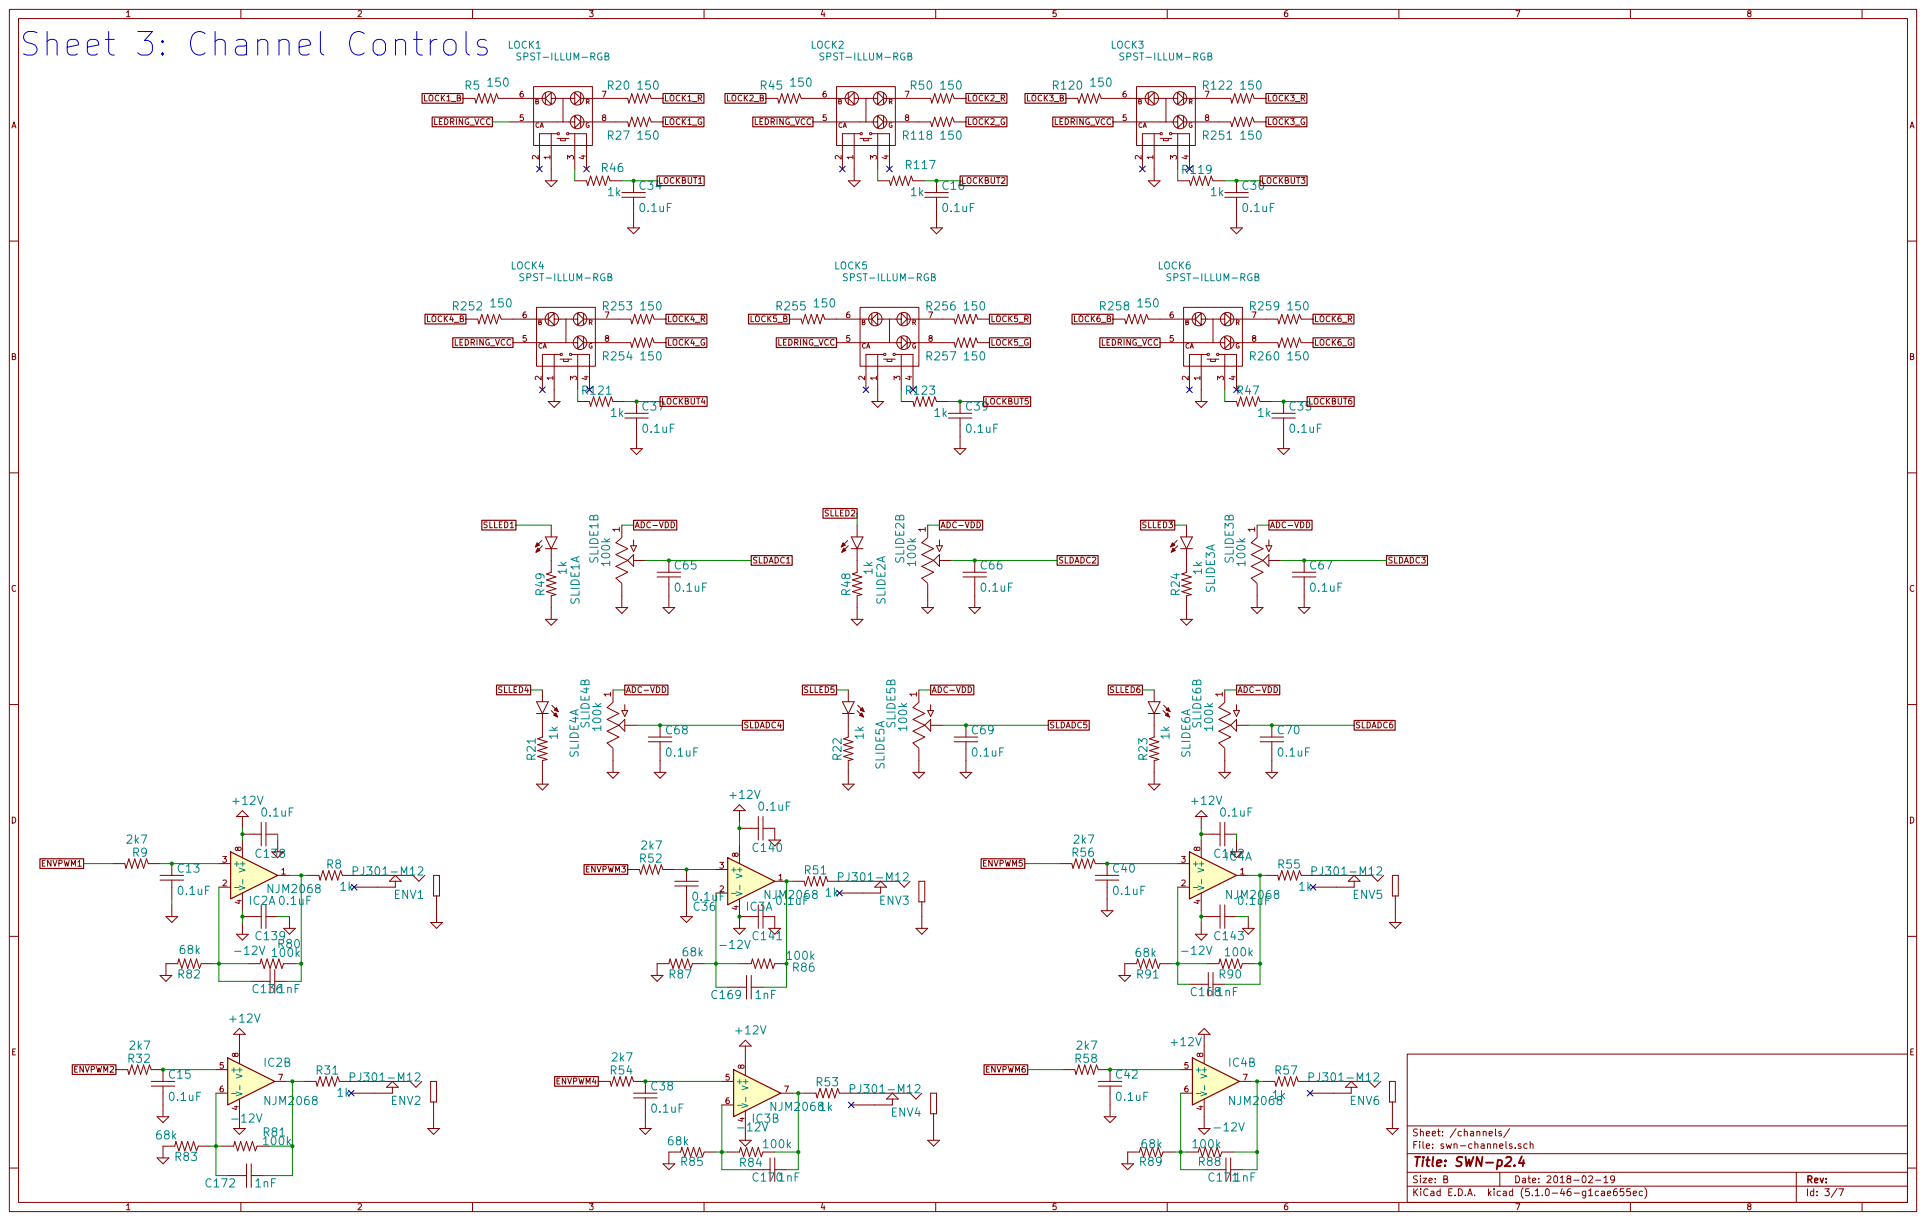
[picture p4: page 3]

File: swn-channels.sch Sheet: /channels/ Sheet 3: Channel Controls

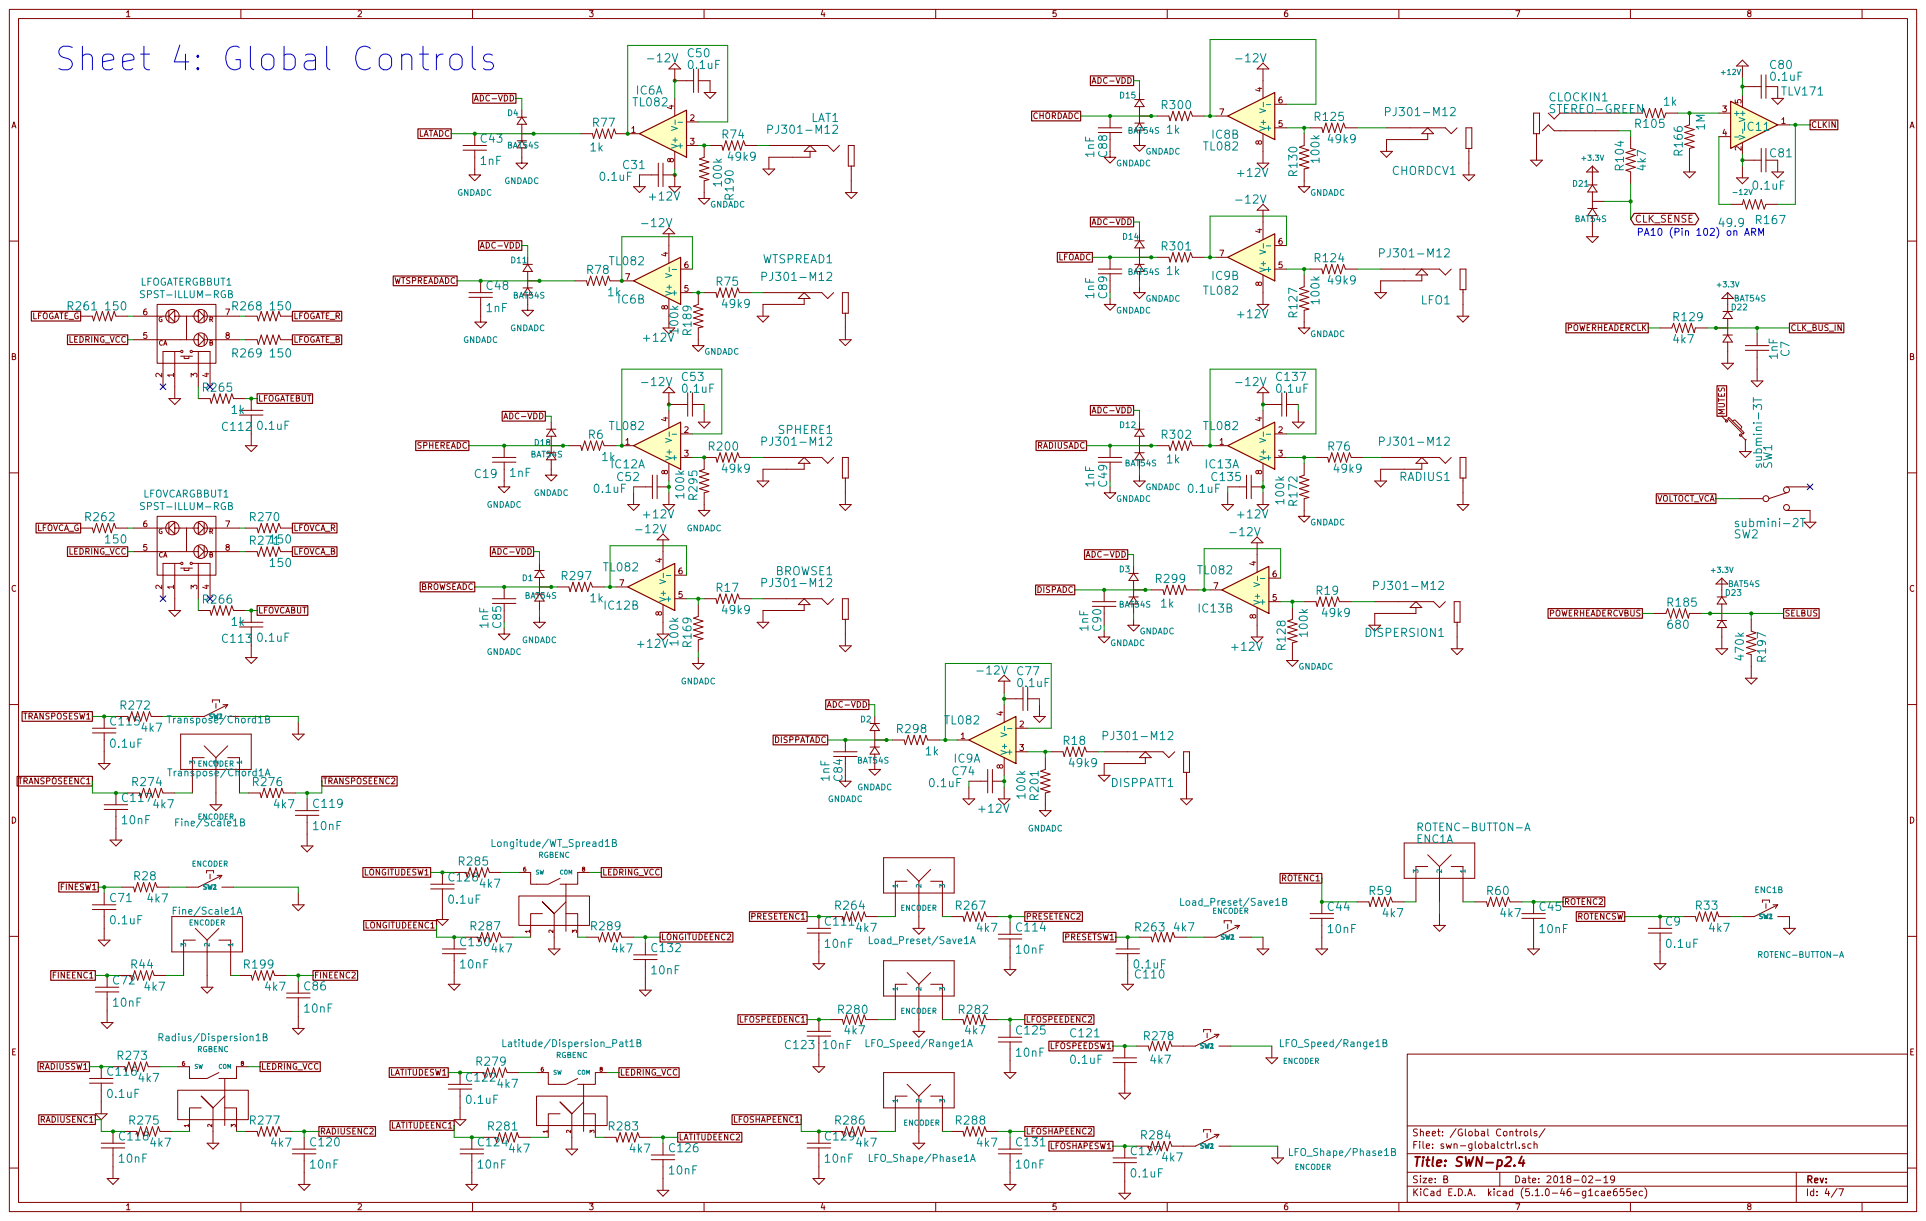
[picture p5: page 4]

File: swn-globalctrl.sch Sheet: /Global Controls/ Sheet 4: Global Controls

CLKIN PA10 (Pin 102) on ARM

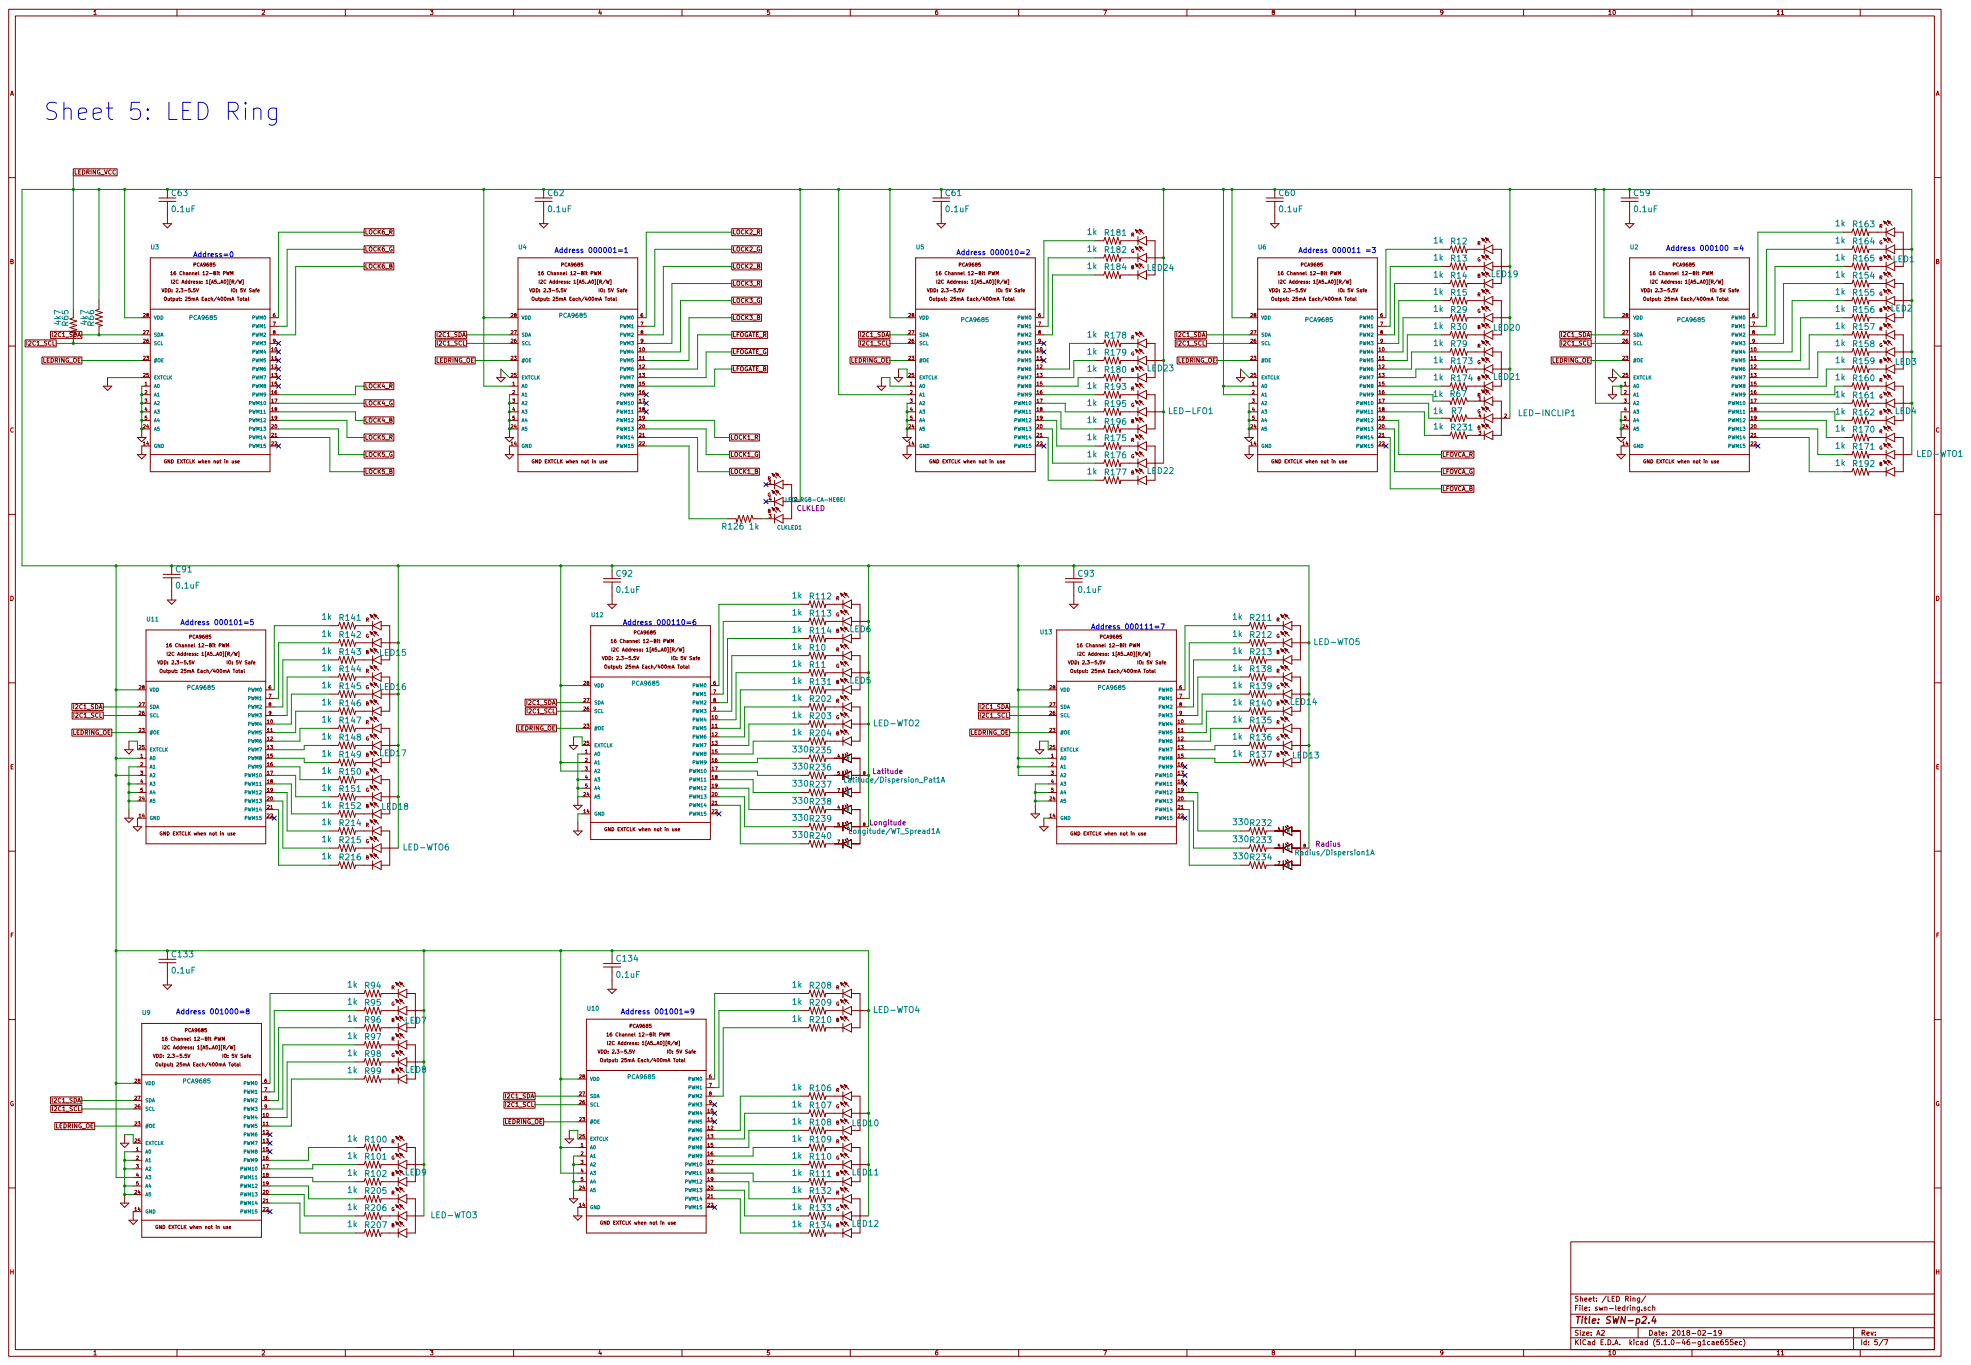
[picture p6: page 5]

IO: 5V Safe Output: 25mA Each/400mA Total PCA9685 VDD: 2.3-5.5V
16 Channel 12-Bit PWM
I2C Address: 1[A5..A0][R/W]

GND EXTCLK when not in use

LED-RGB-CA-HEBEI CLKLED

Sheet: /LED Ring/
File: swn-ledring.sch
Id: 5/7 Title: SWN-p2.4

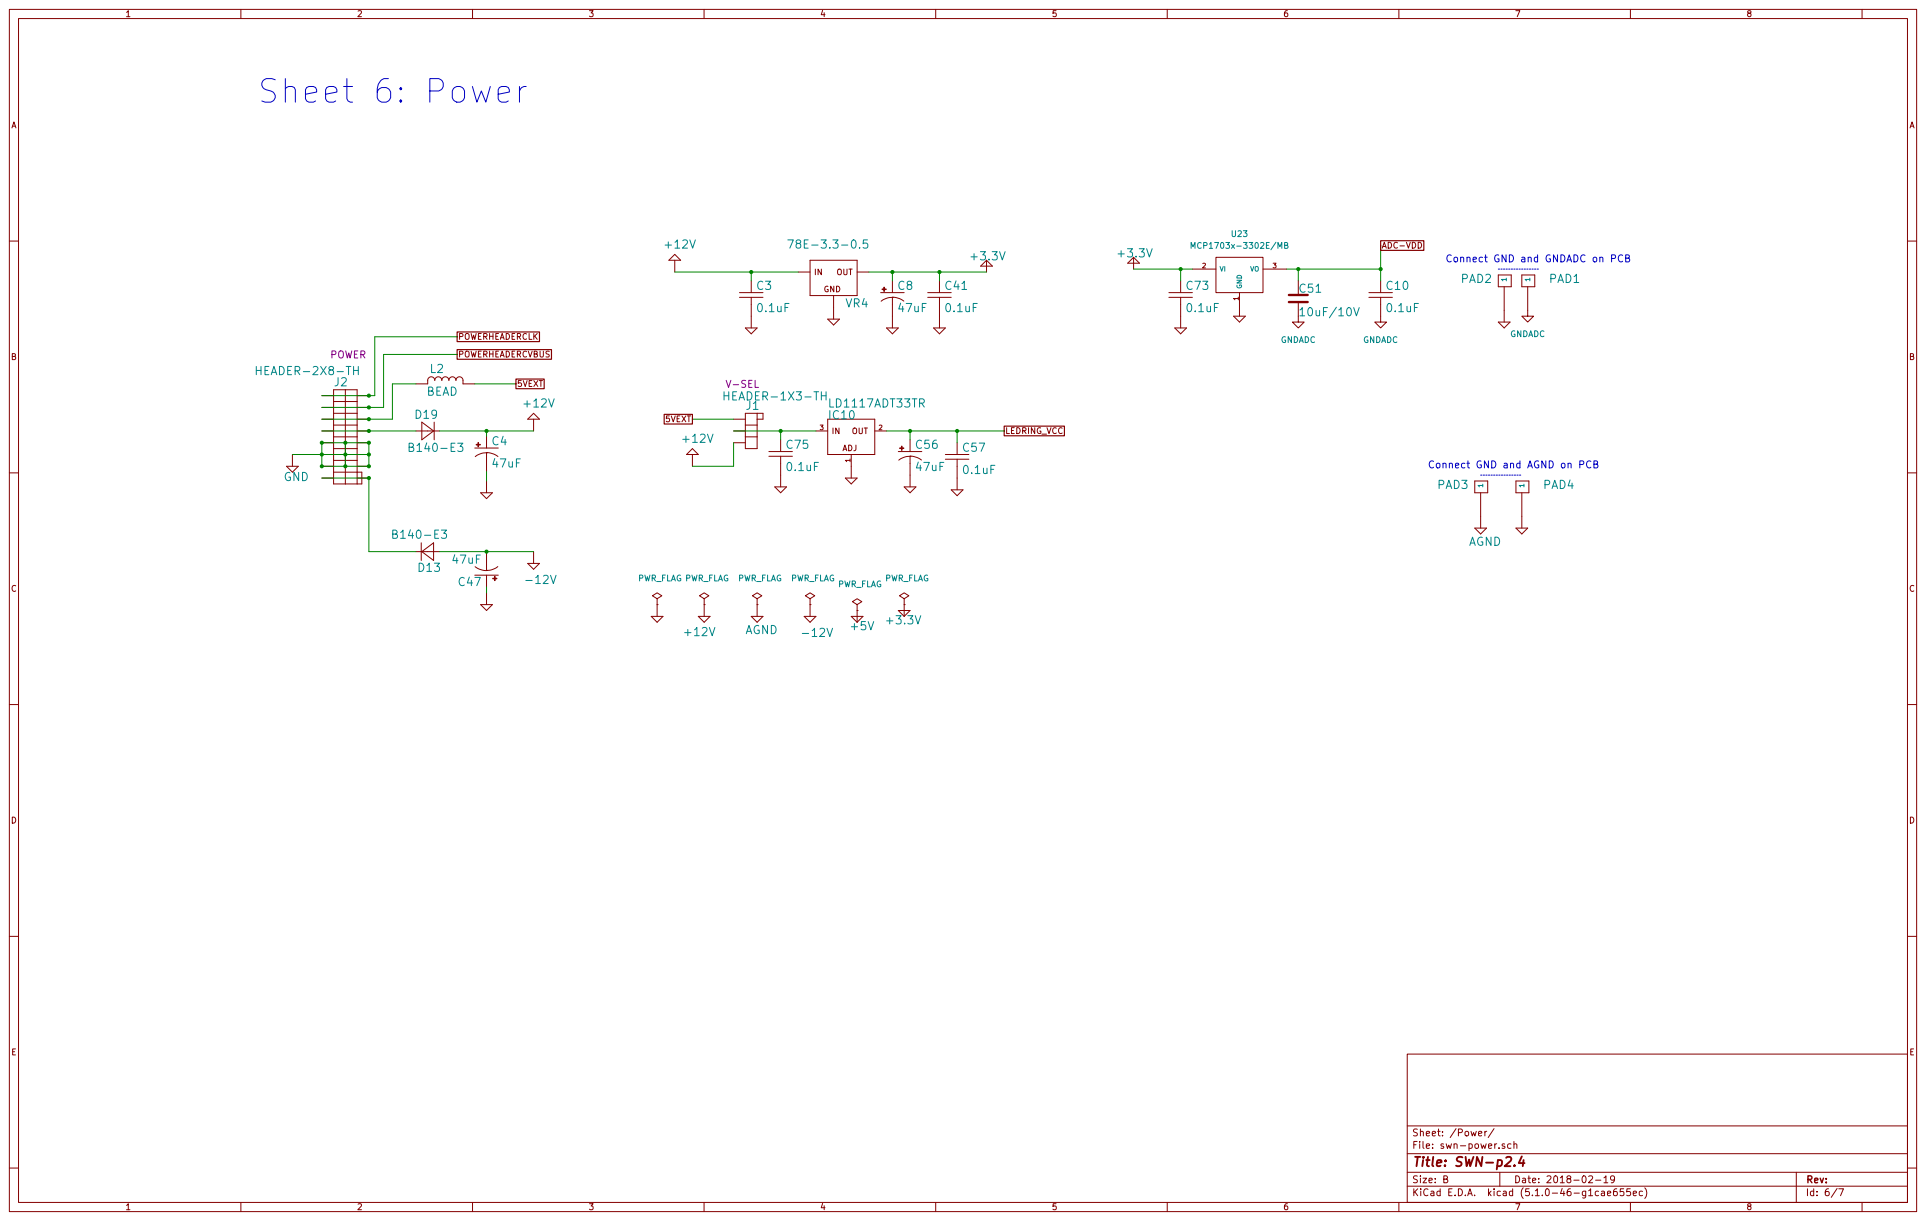
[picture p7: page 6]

File: swn-power.sch Sheet: /Power/ Sheet 6: Power

Connect GND and GNDADC on PCB

Connect GND and AGND on PCB

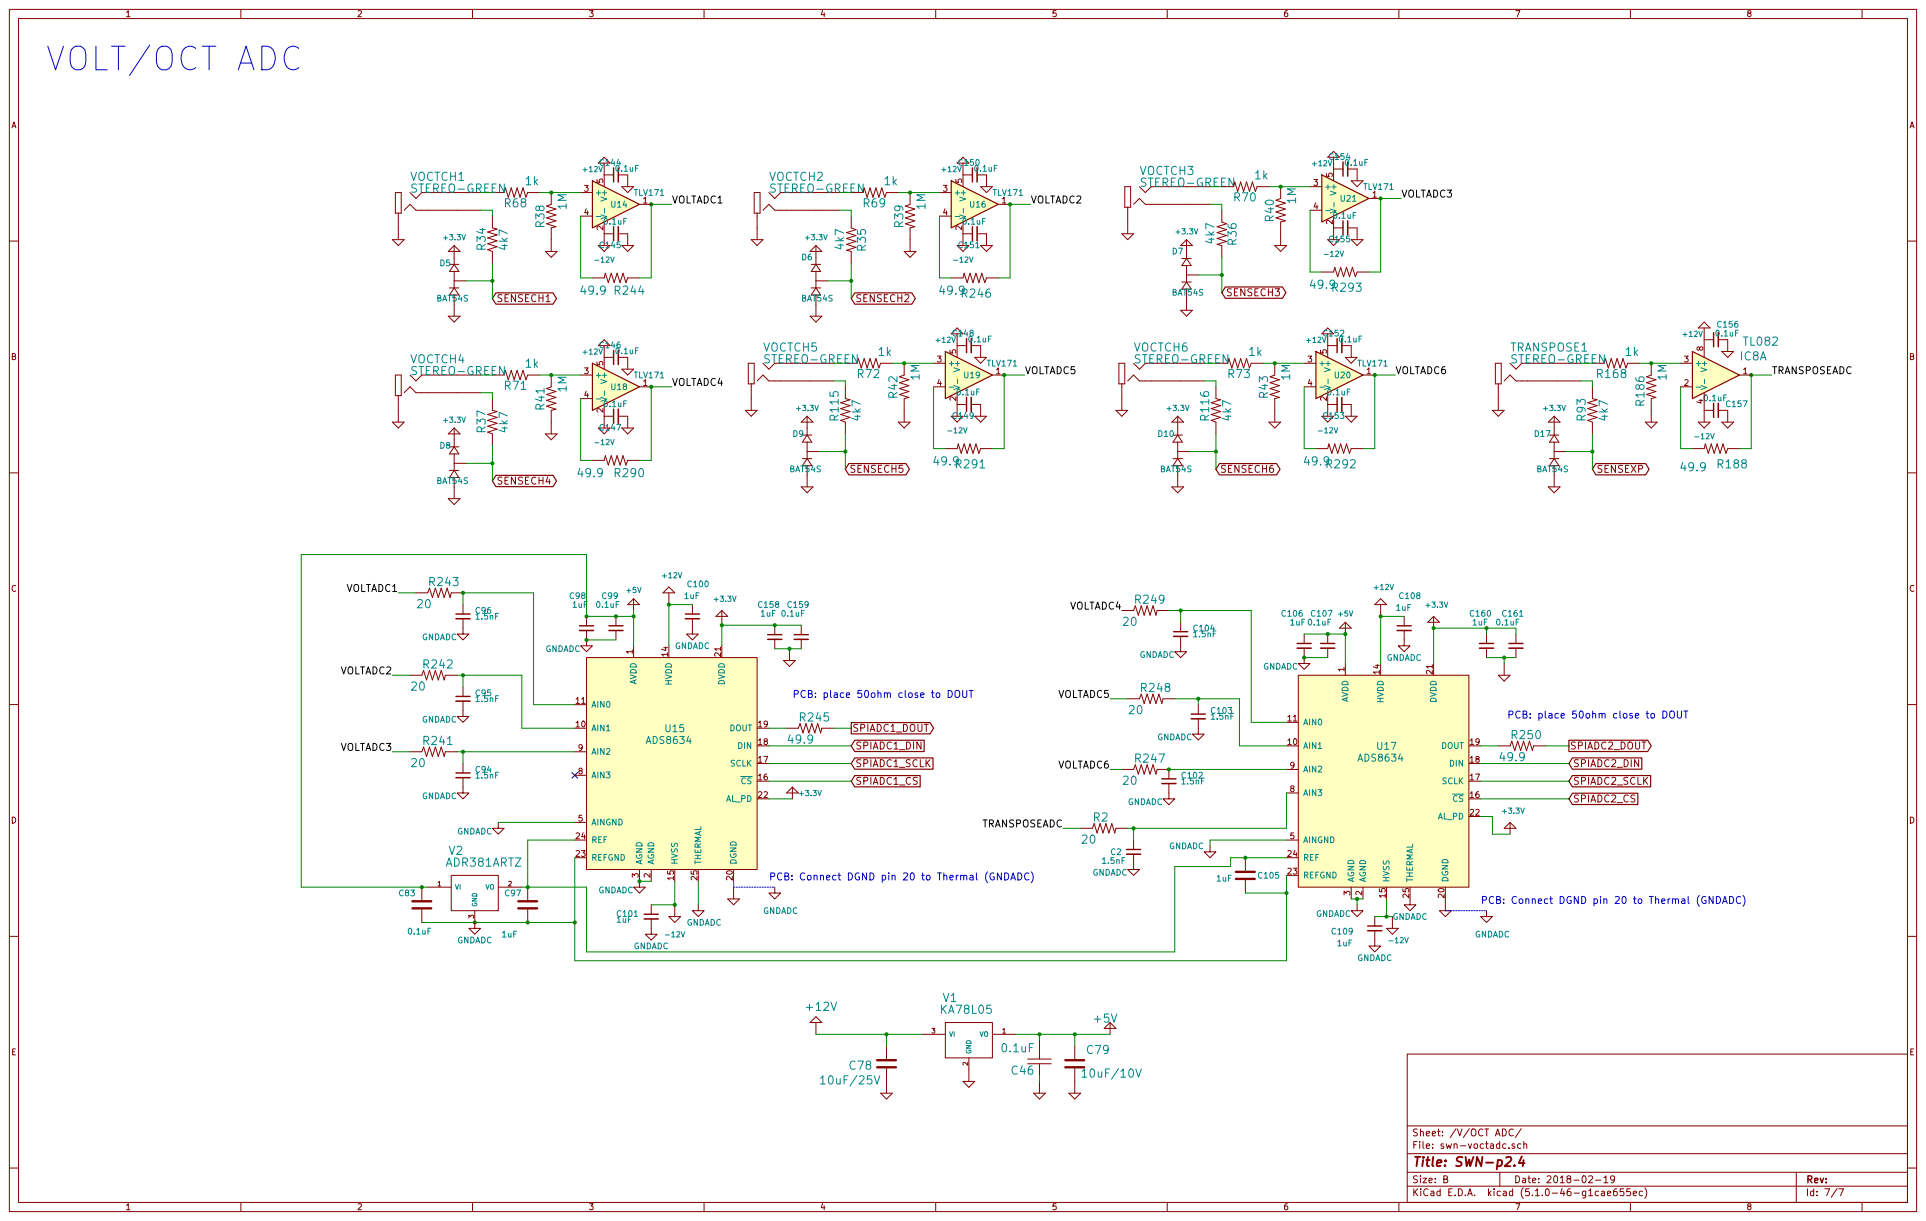
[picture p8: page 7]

File: swn-voctadc.sch Sheet: /V/OCT ADC/ VOLT/OCT ADC

1 AIN1 10 AIN0 11 HVDD 14 HVSS 15 CS 16 SCLK 17 DIN 18 DOUT 19 AGND

2 DGND 20 DVDD 21 AL_PD 22 REFGND 23 REF 24 THERMAL 25 AGND

PCB: place 50ohm close to DOUT

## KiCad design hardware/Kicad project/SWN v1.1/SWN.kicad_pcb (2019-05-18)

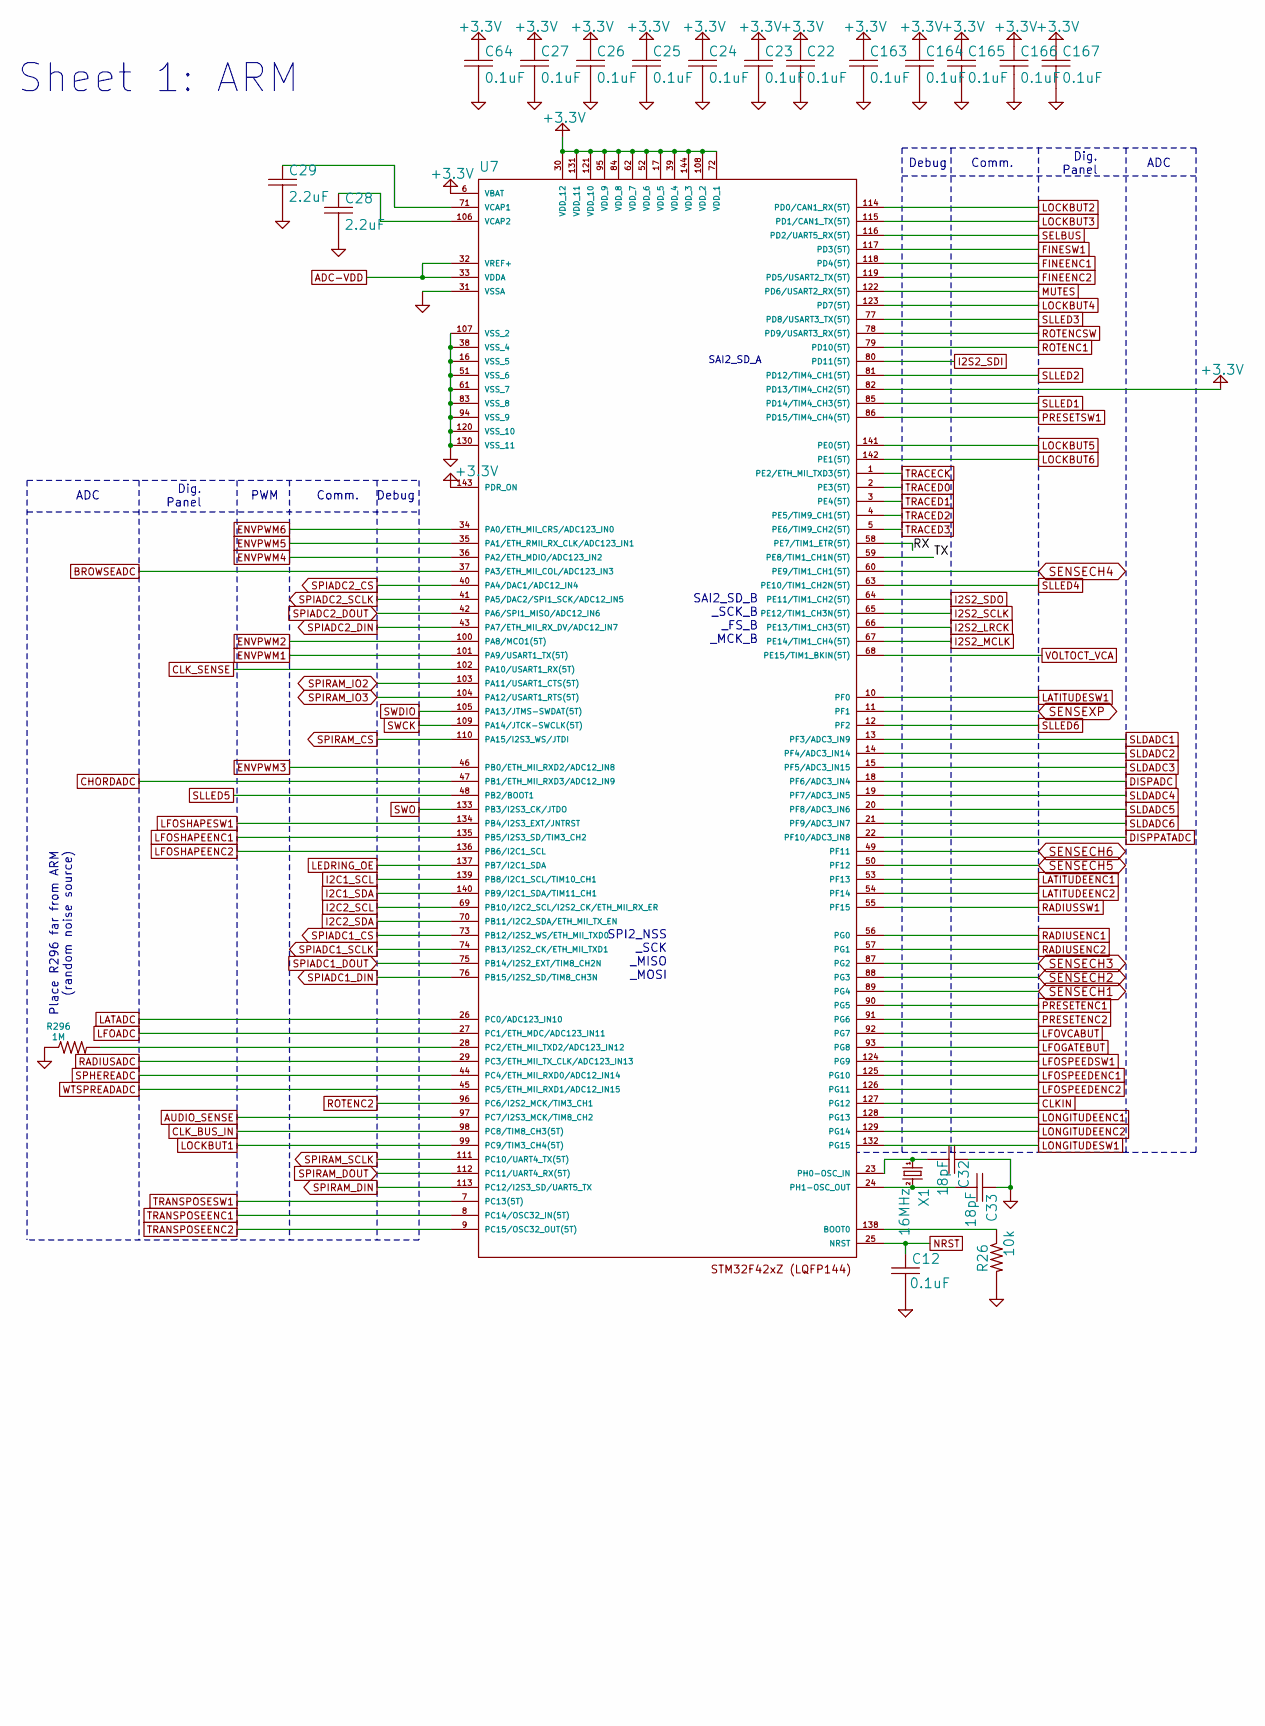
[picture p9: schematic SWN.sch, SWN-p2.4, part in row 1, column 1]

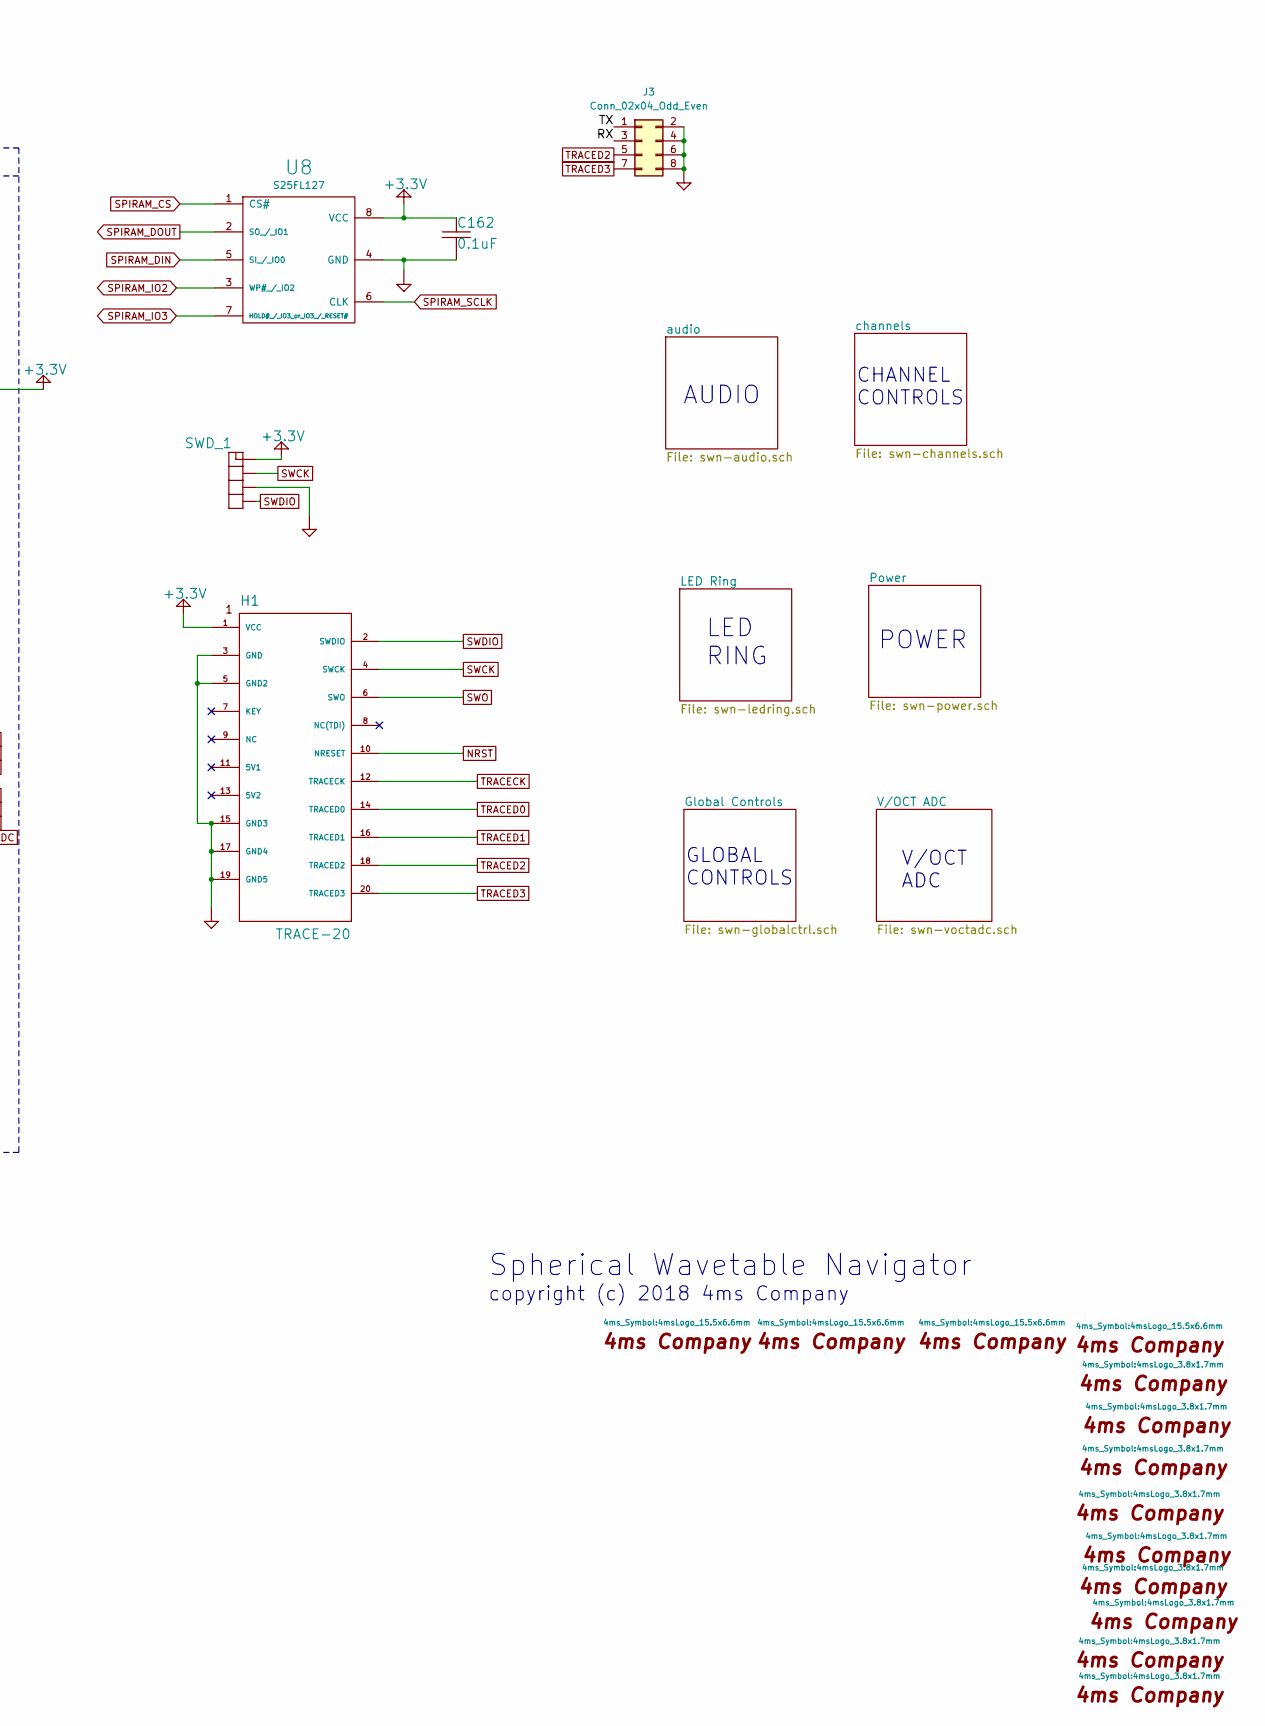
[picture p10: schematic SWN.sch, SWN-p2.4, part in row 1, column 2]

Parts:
C12, C22, C23, C24, C25, C26, C27, C64, C162, C163, C164, C165, C166, C167: 0.1uF; C0603
C28, C29: 2.2uF; C0603
C32, C33: 18pF; C0603
G***1, G***2, G***3, G***4: 4ms-logo; 4msLogo_15.5x6.6mm
G***5, G***6, G***7, G***8, G***9, G***10, G***11, G***12, G***13: 4ms-logo; 4msLogo_3.8x1.7mm
H1: TRACE-20; CONN-2x10-SMT-127
J3: Conn_02x04_Odd_Even; Pins_2x04_2.54mm_TH
R26: 10k; R0603
R296: 1M; R0603
SWD_1: HEADER-1X4; Pins_1x04_2.54mm_TH_SWD
U7: STM32F765ZG; LQFP-144_ARM_20x20mm_Pitch0.5mm
U8: S25FL127; SOIC-8_5.28x4.9mm_Pitch1.27mm
X1: 16MHz; FA-238-Pins1and2diag

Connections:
+3.3V: C22.1, C23.1, C24.1, C25.1, C26.1, C27.1, C64.1, C162.1, C163.1, C164.1, C165.1, C166.1, C167.1, H1.1 (VCC), SWD_1.1, U7.6 (VBAT), U7.17 (VDD_5), U7.30 (VDD_12), U7.39 (VDD_4), U7.52 (VDD_6), U7.62 (VDD_7), U7.72 (VDD_1), U7.82 (PD13/TIM4_CH2(5T)), U7.84 (VDD_8), U7.95 (VDD_9), U7.108 (VDD_2), U7.121 (VDD_10), U7.131 (VDD_11), U7.143 (PDR_ON), U7.144 (VDD_3), U8.8 (VCC); also elsewhere on the board
/RX: J3.3, U7.58 (PE7/TIM1_ETR(5T))
/TX: J3.1, U7.59 (PE8/TIM1_CH1N(5T))
ADC-VDD: U7.32 (VREF+), U7.33 (VDDA); also elsewhere on the board
AUDIO_SENSE: U7.97 (PC7/I2S3_MCK/TIM8_CH2); also elsewhere on the board
BROWSEADC: U7.37 (PA3/ETH_MII_COL/ADC123_IN3); also elsewhere on the board
CHORDADC: U7.47 (PB1/ETH_MII_RXD3/ADC12_IN9); also elsewhere on the board
CLKIN: U7.127 (PG12); also elsewhere on the board
CLK_BUS_IN: U7.98 (PC8/TIM8_CH3(5T)); also elsewhere on the board
CLK_SENSE: U7.102 (PA10/USART1_RX(5T)); also elsewhere on the board
DISPADC: U7.18 (PF6/ADC3_IN4); also elsewhere on the board
DISPPATADC: U7.22 (PF10/ADC3_IN8); also elsewhere on the board
ENVPWM1: U7.101 (PA9/USART1_TX(5T)); also elsewhere on the board
ENVPWM2: U7.100 (PA8/MCO1(5T)); also elsewhere on the board
ENVPWM3: U7.46 (PB0/ETH_MII_RXD2/ADC12_IN8); also elsewhere on the board
ENVPWM4: U7.36 (PA2/ETH_MDIO/ADC123_IN2); also elsewhere on the board
ENVPWM5: U7.35 (PA1/ETH_RMII_RX_CLK/ADC123_IN1); also elsewhere on the board
ENVPWM6: U7.34 (PA0/ETH_MII_CRS/ADC123_IN0); also elsewhere on the board
FINEENC1: U7.118 (PD4(5T)); also elsewhere on the board
FINEENC2: U7.119 (PD5/USART2_TX(5T)); also elsewhere on the board
FINESW1: U7.117 (PD3(5T)); also elsewhere on the board
I2C1_SCL: U7.139 (PB8/I2C1_SCL/TIM10_CH1); also elsewhere on the board
I2C1_SDA: U7.140 (PB9/I2C1_SDA/TIM11_CH1); also elsewhere on the board
I2C2_SCL: U7.69 (PB10/I2C2_SCL/I2S2_CK/ETH_MII_RX_ER); also elsewhere on the board
I2C2_SDA: U7.70 (PB11/I2C2_SDA/ETH_MII_TX_EN); also elsewhere on the board
I2S2_LRCK: U7.66 (PE13/TIM1_CH3(5T)); also elsewhere on the board
I2S2_MCLK: U7.67 (PE14/TIM1_CH4(5T)); also elsewhere on the board
I2S2_SCLK: U7.65 (PE12/TIM1_CH3N(5T)); also elsewhere on the board
I2S2_SDI: U7.80 (PD11(5T)); also elsewhere on the board
I2S2_SDO: U7.64 (PE11/TIM1_CH2(5T)); also elsewhere on the board
LATADC: U7.26 (PC0/ADC123_IN10); also elsewhere on the board
LATITUDEENC1: U7.53 (PF13); also elsewhere on the board
LATITUDEENC2: U7.54 (PF14); also elsewhere on the board
LATITUDESW1: U7.10 (PF0); also elsewhere on the board
LEDRING_OE: U7.137 (PB7/I2C1_SDA); also elsewhere on the board
LFOADC: U7.27 (PC1/ETH_MDC/ADC123_IN11); also elsewhere on the board
LFOGATEBUT: U7.93 (PG8); also elsewhere on the board
LFOSHAPEENC1: U7.135 (PB5/I2S3_SD/TIM3_CH2); also elsewhere on the board
LFOSHAPEENC2: U7.136 (PB6/I2C1_SCL); also elsewhere on the board
LFOSHAPESW1: U7.134 (PB4/I2S3_EXT/JNTRST); also elsewhere on the board
LFOSPEEDENC1: U7.125 (PG10); also elsewhere on the board
LFOSPEEDENC2: U7.126 (PG11); also elsewhere on the board
LFOSPEEDSW1: U7.124 (PG9); also elsewhere on the board
LFOVCABUT: U7.92 (PG7); also elsewhere on the board
LOCKBUT1: U7.99 (PC9/TIM3_CH4(5T)); also elsewhere on the board
LOCKBUT2: U7.114 (PD0/CAN1_RX(5T)); also elsewhere on the board
LOCKBUT3: U7.115 (PD1/CAN1_TX(5T)); also elsewhere on the board
LOCKBUT4: U7.123 (PD7(5T)); also elsewhere on the board
LOCKBUT5: U7.141 (PE0(5T)); also elsewhere on the board
LOCKBUT6: U7.142 (PE1(5T)); also elsewhere on the board
LONGITUDEENC1: U7.128 (PG13); also elsewhere on the board
LONGITUDEENC2: U7.129 (PG14); also elsewhere on the board
LONGITUDESW1: U7.132 (PG15); also elsewhere on the board
MUTES: U7.122 (PD6/USART2_RX(5T)); also elsewhere on the board
NRST: C12.1, H1.10 (NRESET), U7.25 (NRST)
unnamed: C28.1, U7.106 (VCAP2)
unnamed: C29.1, U7.71 (VCAP1)
unnamed: C32.2, U7.23 (PH0-OSC_IN), X1.1
unnamed: C33.2, U7.24 (PH1-OSC_OUT), X1.2
unnamed: R26.1, U7.138 (BOOT0)
unnamed: R296.2, U7.28 (PC2/ETH_MII_TXD2/ADC123_IN12)
PRESETENC1: U7.90 (PG5); also elsewhere on the board
PRESETENC2: U7.91 (PG6); also elsewhere on the board
PRESETSW1: U7.86 (PD15/TIM4_CH4(5T)); also elsewhere on the board
RADIUSADC: U7.29 (PC3/ETH_MII_TX_CLK/ADC123_IN13); also elsewhere on the board
RADIUSENC1: U7.56 (PG0); also elsewhere on the board
RADIUSENC2: U7.57 (PG1); also elsewhere on the board
RADIUSSW1: U7.55 (PF15); also elsewhere on the board
ROTENC1: U7.79 (PD10(5T)); also elsewhere on the board
ROTENC2: U7.96 (PC6/I2S2_MCK/TIM3_CH1); also elsewhere on the board
ROTENCSW: U7.78 (PD9/USART3_RX(5T)); also elsewhere on the board
SELBUS: U7.116 (PD2/UART5_RX(5T)); also elsewhere on the board
SENSECH1: U7.89 (PG4); also elsewhere on the board
SENSECH2: U7.88 (PG3); also elsewhere on the board
SENSECH3: U7.87 (PG2); also elsewhere on the board
SENSECH4: U7.60 (PE9/TIM1_CH1(5T)); also elsewhere on the board
SENSECH5: U7.50 (PF12); also elsewhere on the board
SENSECH6: U7.49 (PF11); also elsewhere on the board
SENSEXP: U7.11 (PF1); also elsewhere on the board
SLDADC1: U7.13 (PF3/ADC3_IN9); also elsewhere on the board
SLDADC2: U7.14 (PF4/ADC3_IN14); also elsewhere on the board
SLDADC3: U7.15 (PF5/ADC3_IN15); also elsewhere on the board
SLDADC4: U7.19 (PF7/ADC3_IN5); also elsewhere on the board
SLDADC5: U7.20 (PF8/ADC3_IN6); also elsewhere on the board
SLDADC6: U7.21 (PF9/ADC3_IN7); also elsewhere on the board
SLLED1: U7.85 (PD14/TIM4_CH3(5T)); also elsewhere on the board
SLLED2: U7.81 (PD12/TIM4_CH1(5T)); also elsewhere on the board
SLLED3: U7.77 (PD8/USART3_TX(5T)); also elsewhere on the board
SLLED4: U7.63 (PE10/TIM1_CH2N(5T)); also elsewhere on the board
SLLED5: U7.48 (PB2/BOOT1); also elsewhere on the board
SLLED6: U7.12 (PF2); also elsewhere on the board
SPHEREADC: U7.44 (PC4/ETH_MII_RXD0/ADC12_IN14); also elsewhere on the board
SPIADC1_CS: U7.73 (PB12/I2S2_WS/ETH_MII_TXD0); also elsewhere on the board
SPIADC1_DIN: U7.76 (PB15/I2S2_SD/TIM8_CH3N); also elsewhere on the board
SPIADC1_DOUT: U7.75 (PB14/I2S2_EXT/TIM8_CH2N); also elsewhere on the board
SPIADC1_SCLK: U7.74 (PB13/I2S2_CK/ETH_MII_TXD1); also elsewhere on the board
SPIADC2_CS: U7.40 (PA4/DAC1/ADC12_IN4); also elsewhere on the board
SPIADC2_DIN: U7.43 (PA7/ETH_MII_RX_DV/ADC12_IN7); also elsewhere on the board
SPIADC2_DOUT: U7.42 (PA6/SPI1_MISO/ADC12_IN6); also elsewhere on the board
SPIADC2_SCLK: U7.41 (PA5/DAC2/SPI1_SCK/ADC12_IN5); also elsewhere on the board
SPIRAM_CS: U7.110 (PA15/I2S3_WS/JTDI), U8.1 (CS#)
SPIRAM_DIN: U7.113 (PC12/I2S3_SD/UART5_TX), U8.5 (SI_/_IO0)
SPIRAM_DOUT: U7.112 (PC11/UART4_RX(5T)), U8.2 (SO_/_IO1)
SPIRAM_IO2: U7.103 (PA11/USART1_CTS(5T)), U8.3 (WP#_/_IO2)
SPIRAM_IO3: U7.104 (PA12/USART1_RTS(5T)), U8.7 (HOLD#_/_IO3_or_IO3_/_RESET#)
SPIRAM_SCLK: U7.111 (PC10/UART4_TX(5T)), U8.6 (CLK)
SWCK: H1.4 (SWCK), SWD_1.2, U7.109 (PA14/JTCK-SWCLK(5T))
SWDIO: H1.2 (SWDIO), SWD_1.4, U7.105 (PA13/JTMS-SWDAT(5T))
SWO: H1.6 (SWO), U7.133 (PB3/I2S3_CK/JTDO)
TRACECK: H1.12 (TRACECK), U7.1 (PE2/ETH_MII_TXD3(5T))
TRACED0: H1.14 (TRACED0), U7.2 (PE3(5T))
TRACED1: H1.16 (TRACED1), U7.3 (PE4(5T))
TRACED2: H1.18 (TRACED2), J3.5, U7.4 (PE5/TIM9_CH1(5T))
TRACED3: H1.20 (TRACED3), J3.7, U7.5 (PE6/TIM9_CH2(5T))
TRANSPOSEENC1: U7.8 (PC14/OSC32_IN(5T)); also elsewhere on the board
TRANSPOSEENC2: U7.9 (PC15/OSC32_OUT(5T)); also elsewhere on the board
TRANSPOSESW1: U7.7 (PC13(5T)); also elsewhere on the board
VOLTOCT_VCA: U7.68 (PE15/TIM1_BKIN(5T)); also elsewhere on the board
WTSPREADADC: U7.45 (PC5/ETH_MII_RXD1/ADC12_IN15); also elsewhere on the board

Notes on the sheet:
Spherical Wavetable Navigator
copyright (c) 2018 4ms Company
Sheet 1: ARM
AUDIO
CHANNEL CONTROLS
GLOBAL CONTROLS
LED RING
POWER
V/OCT ADC
Place R296 far from ARM (random noise source)
ADC
Dig. Panel
PWM
Comm.
Debug
SAI2_SD_A
SAI2_SD_B _SCK_B _FS_B _MCK_B
SPI2_NSS _SCK _MISO _MOSI

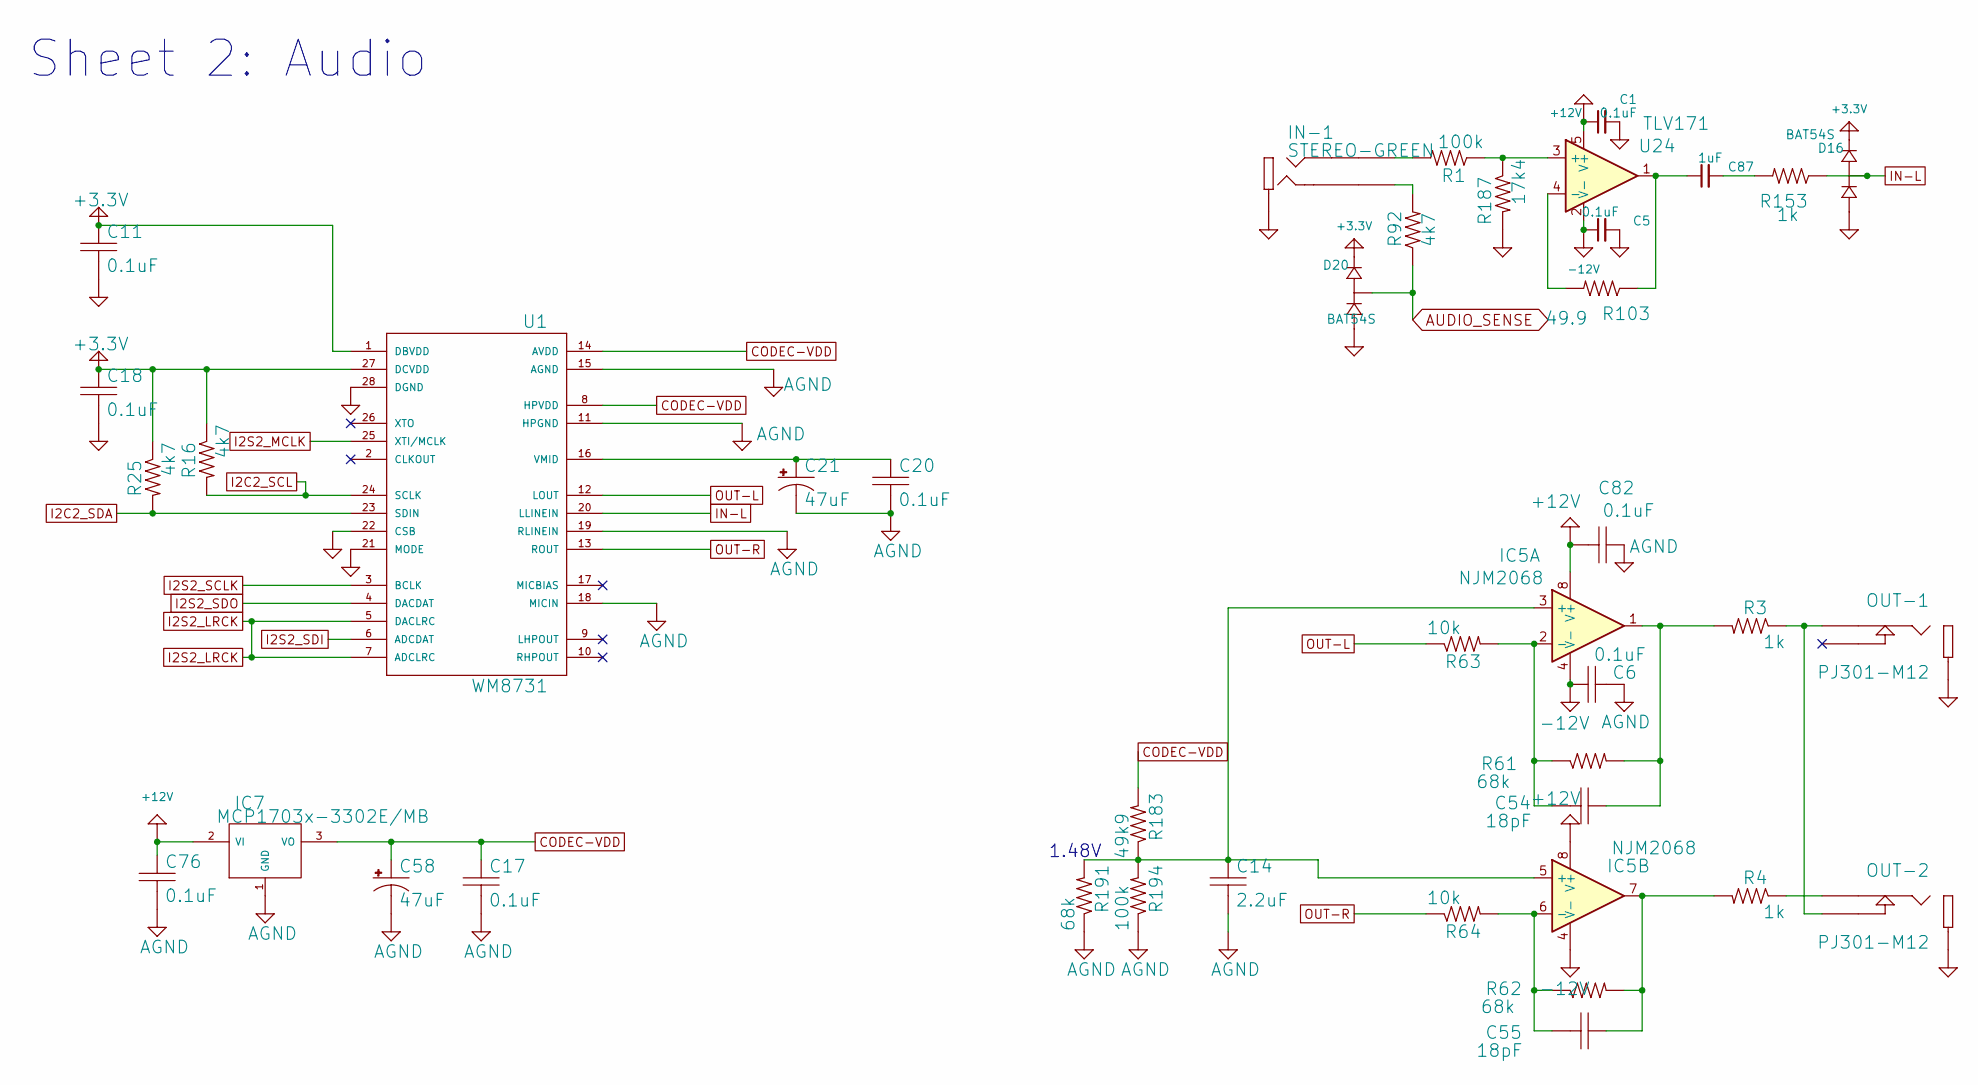
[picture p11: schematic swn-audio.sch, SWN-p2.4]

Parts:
C1, C5, C6, C11, C17, C18, C20, C76, C82: 0.1uF; C0603
C14: 2.2uF; C0603
C21, C58: 47uF; CP_Elec_5x5.3
C54, C55: 18pF; C0603
C87: 1uF; C0603
D16, D20: BAT54S; SOT23
IC5: NJM2068; TSSOP-8_4.4x3mm_Pitch0.65mm
IC7: MCP1703x-3302E/MB; SOT-89-3
IN-1: STEREO-GREEN; PJ301M-12
OUT-1, OUT-2: PJ301-M12; PJ301M-12
R1, R194: 100k; R0603
R3, R4, R153: 1k; R0603
R16, R25, R92: 4k7; R0603
R61, R62, R191: 68k; R0603
R63, R64: 10k; R0603
R103: 49.9; R0603
R183: 49k9; R0603
R187: 17k4; R0603
U1: WM8731; SSOP-28
U24: TLV171; SOT-23-5

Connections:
+3.3V: C11.1, C18.1, D16.2 (CATHODE), D20.2 (CATHODE), R16.1, R25.1, U1.1 (DBVDD), U1.27 (DCVDD); also elsewhere on the board
+12V: C1.1, C76.1, C82.2, IC5.8 (V+), IC7.2 (VI), U24.5 (V+); also elsewhere on the board
-12V: C5.1, C6.1, IC5.4 (V-), U24.2 (V-); also elsewhere on the board
AGND: C6.2, C14.2, C17.2, C20.2, C21.2 (-), C58.2 (-), C76.2, C82.1, IC7.1 (GND), R191.1, R194.1, U1.11 (HPGND), U1.15 (AGND), U1.18 (MICIN), U1.19 (RLINEIN); also elsewhere on the board
AUDIO_SENSE: D20.3 (COMMON), R92.1; also elsewhere on the board
CODEC-VDD: C17.1, C58.1 (+), IC7.3 (VO), R183.2, U1.8 (HPVDD), U1.14 (AVDD)
I2C2_SCL: R16.2, U1.24 (SCLK); also elsewhere on the board
I2C2_SDA: R25.2, U1.23 (SDIN); also elsewhere on the board
I2S2_LRCK: U1.5 (DACLRC), U1.7 (ADCLRC); also elsewhere on the board
I2S2_MCLK: U1.25 (XTI/MCLK); also elsewhere on the board
I2S2_SCLK: U1.3 (BCLK); also elsewhere on the board
I2S2_SDI: U1.6 (ADCDAT); also elsewhere on the board
I2S2_SDO: U1.4 (DACDAT); also elsewhere on the board
IN-L: D16.3 (COMMON), R153.1, U1.20 (LLINEIN)
unnamed: C14.1, IC5.3 (+), IC5.5 (+), R183.1, R191.2, R194.2
unnamed: C20.1, C21.1 (+), U1.16 (VMID)
unnamed: C54.1, IC5.1, R3.2, R61.2
unnamed: C54.2, IC5.2 (-), R61.1, R63.2
unnamed: C55.1, IC5.7, R4.2, R62.2
unnamed: C55.2, IC5.6 (-), R62.1, R64.2
unnamed: C87.1, R103.1, U24.1
unnamed: C87.2, R153.2
unnamed: IN-1.1 (TIP), R1.2
unnamed: IN-1.3 (TIP-SW), R92.2
unnamed: OUT-1.1 (TIP), OUT-2.3 (TIP-SW), R3.1
unnamed: OUT-2.1 (TIP), R4.1
unnamed: R1.1, R187.1, U24.3 (+)
unnamed: R103.2, U24.4 (-)
OUT-L: R63.1, U1.12 (LOUT)
OUT-R: R64.1, U1.13 (ROUT)

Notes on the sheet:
1.48V
Sheet 2: Audio

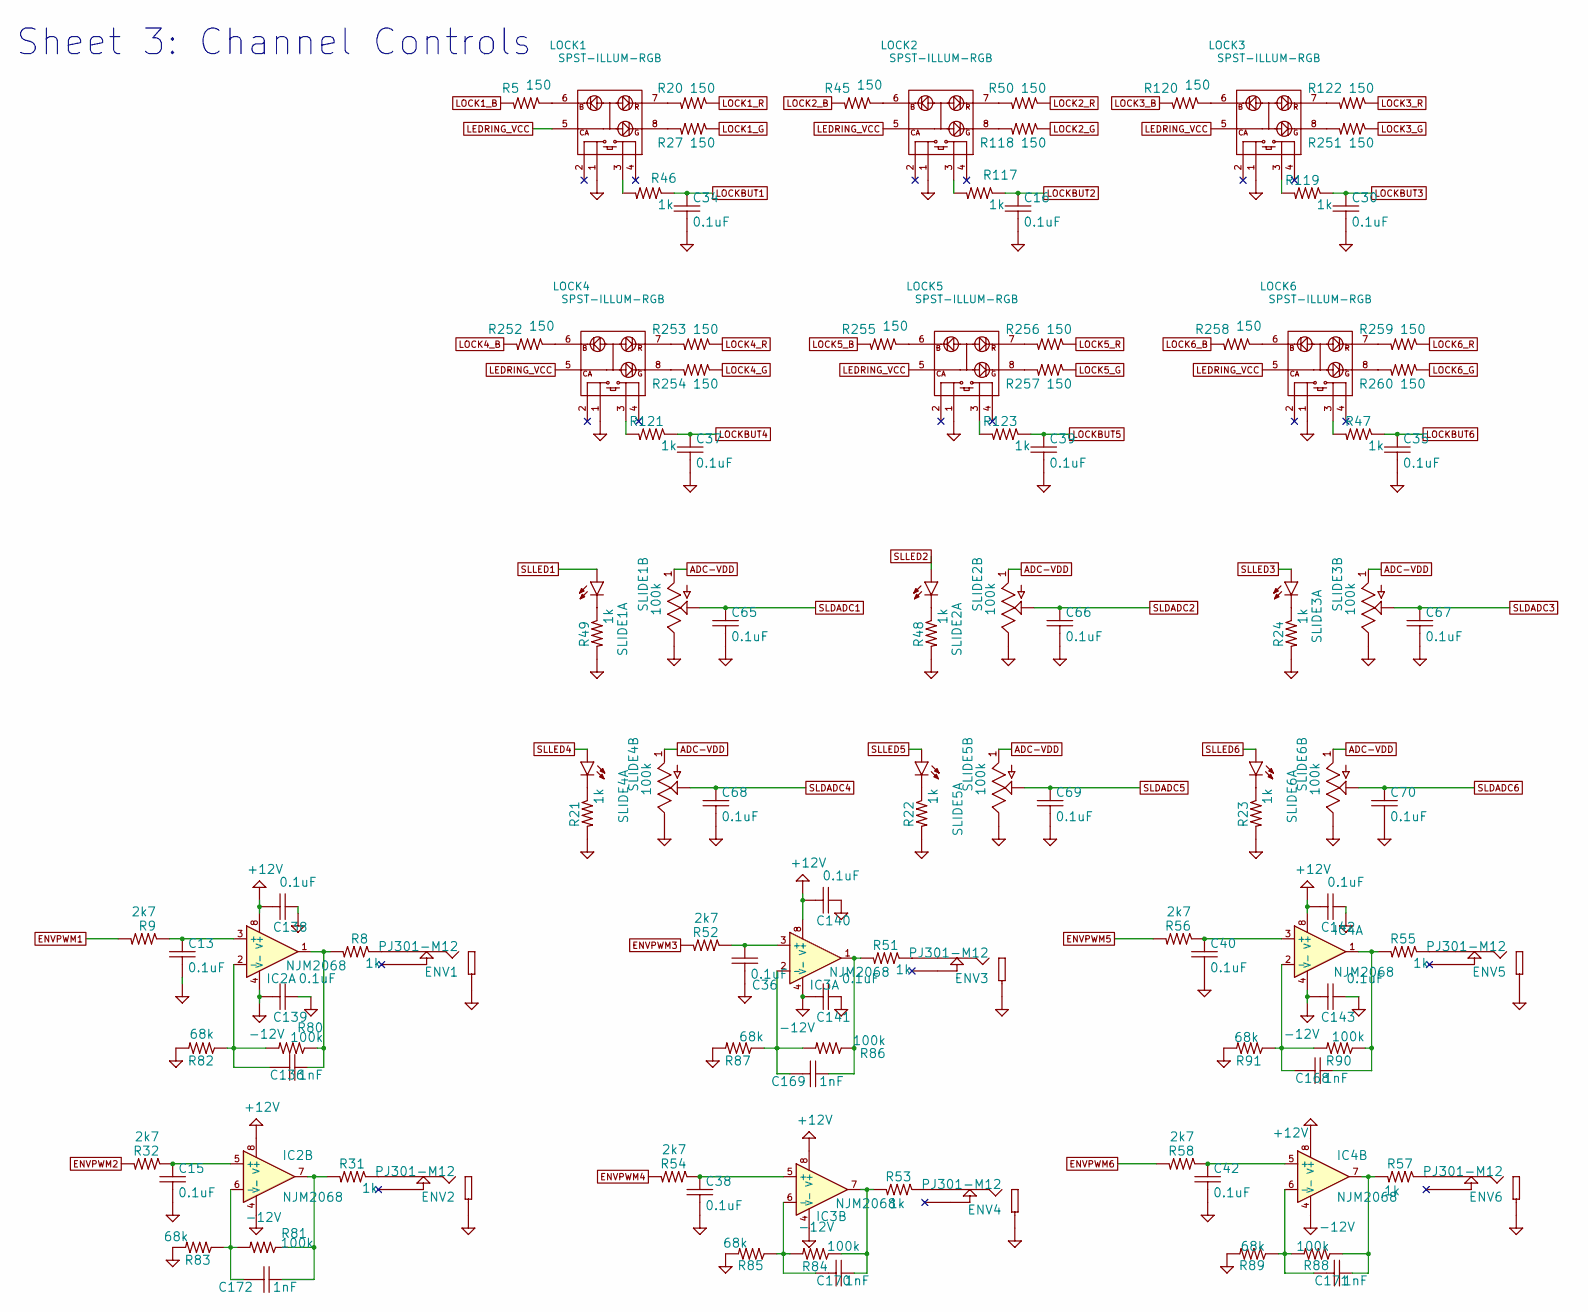
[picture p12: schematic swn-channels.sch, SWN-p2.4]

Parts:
C13, C15, C16, C30, C34, C35, C36, C37, C38, C39, C40, C42, C65, C66, C67, C68, C69, C70, C138, C139, C140, C141, C142, C143: 0.1uF; C0603
C136, C168, C169, C170, C171, C172: 1nF; C0603
ENV1, ENV2, ENV3, ENV4, ENV5, ENV6: PJ301-M12; PJ301M-12
IC2, IC3, IC4: NJM2068; TSSOP-8_4.4x3mm_Pitch0.65mm
LOCK1, LOCK2, LOCK3, LOCK4, LOCK5, LOCK6: SPST-ILLUM-RGB; RGB-SPST-LED-TC002
R5, R20, R27, R45, R50, R118, R120, R122, R251, R252, R253, R254, R255, R256, R257, R258, R259, R260: 150; R0603
R8, R21, R22, R23, R24, R31, R46, R47, R48, R49, R51, R53, R55, R57, R117, R119, R121, R123: 1k; R0603
R9, R32, R52, R54, R56, R58: 2k7; R0603
R80, R81, R84, R86, R88, R90: 100k; R0603
R82, R83, R85, R87, R89, R91: 68k; R0603
SLIDE1, SLIDE2, SLIDE3, SLIDE4, SLIDE5, SLIDE6: 100k; POT-SLIDER-LED-ALPHA-RA2045F-20

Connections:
+12V: C138.2, C140.2, C142.2, IC2.8 (V+), IC3.8 (V+), IC4.8 (V+); also elsewhere on the board
-12V: C139.2, C141.2, C143.2, IC2.4 (V-), IC3.4 (V-), IC4.4 (V-); also elsewhere on the board
ADC-VDD: SLIDE1.P1 (1), SLIDE2.P1 (1), SLIDE3.P1 (1), SLIDE4.P1 (1), SLIDE5.P1 (1), SLIDE6.P1 (1); also elsewhere on the board
ENVPWM1: R9.2; also elsewhere on the board
ENVPWM2: R32.2; also elsewhere on the board
ENVPWM3: R52.2; also elsewhere on the board
ENVPWM4: R54.2; also elsewhere on the board
ENVPWM5: R56.2; also elsewhere on the board
ENVPWM6: R58.2; also elsewhere on the board
LEDRING_VCC: LOCK1.5 (CA), LOCK2.5 (CA), LOCK3.5 (CA), LOCK4.5 (CA), LOCK5.5 (CA), LOCK6.5 (CA); also elsewhere on the board
LOCK1_B: R5.2; also elsewhere on the board
LOCK1_G: R27.1; also elsewhere on the board
LOCK1_R: R20.1; also elsewhere on the board
LOCK2_B: R45.2; also elsewhere on the board
LOCK2_G: R118.1; also elsewhere on the board
LOCK2_R: R50.1; also elsewhere on the board
LOCK3_B: R120.2; also elsewhere on the board
LOCK3_G: R251.1; also elsewhere on the board
LOCK3_R: R122.1; also elsewhere on the board
LOCK4_B: R252.2; also elsewhere on the board
LOCK4_G: R254.1; also elsewhere on the board
LOCK4_R: R253.1; also elsewhere on the board
LOCK5_B: R255.2; also elsewhere on the board
LOCK5_G: R257.1; also elsewhere on the board
LOCK5_R: R256.1; also elsewhere on the board
LOCK6_B: R258.2; also elsewhere on the board
LOCK6_G: R260.1; also elsewhere on the board
LOCK6_R: R259.1; also elsewhere on the board
LOCKBUT1: C34.1, R46.1; also elsewhere on the board
LOCKBUT2: C16.1, R117.1; also elsewhere on the board
LOCKBUT3: C30.1, R119.1; also elsewhere on the board
LOCKBUT4: C37.1, R121.1; also elsewhere on the board
LOCKBUT5: C39.1, R123.1; also elsewhere on the board
LOCKBUT6: C35.1, R47.1; also elsewhere on the board
unnamed: C13.1, IC2.3 (+), R9.1
unnamed: C15.1, IC2.5 (+), R32.1
unnamed: C36.1, IC3.3 (+), R52.1
unnamed: C38.1, IC3.5 (+), R54.1
unnamed: C40.1, IC4.3 (+), R56.1
unnamed: C42.1, IC4.5 (+), R58.1
unnamed: C136.1, IC2.1, R8.2, R80.1
unnamed: C136.2, IC2.2 (-), R80.2, R82.1
unnamed: C168.1, IC4.1, R55.2, R90.1
unnamed: C168.2, IC4.2 (-), R90.2, R91.1
unnamed: C169.1, IC3.1, R51.2, R86.1
unnamed: C169.2, IC3.2 (-), R86.2, R87.1
unnamed: C170.1, IC3.7, R53.2, R84.1
unnamed: C170.2, IC3.6 (-), R84.2, R85.1
unnamed: C171.1, IC4.7, R57.2, R88.1
unnamed: C171.2, IC4.6 (-), R88.2, R89.1
unnamed: C172.1, IC2.7, R31.2, R81.1
unnamed: C172.2, IC2.6 (-), R81.2, R83.1
unnamed: ENV1.1 (TIP), R8.1
unnamed: ENV2.1 (TIP), R31.1
unnamed: ENV3.1 (TIP), R51.1
unnamed: ENV4.1 (TIP), R53.1
unnamed: ENV5.1 (TIP), R55.1
unnamed: ENV6.1 (TIP), R57.1
unnamed: LOCK1.3 (DOWN-A), R46.2
unnamed: LOCK1.6 (G), R5.1
unnamed: LOCK1.7 (R), R20.2
unnamed: LOCK1.8 (B), R27.2
unnamed: LOCK2.3 (DOWN-A), R117.2
unnamed: LOCK2.6 (G), R45.1
unnamed: LOCK2.7 (R), R50.2
unnamed: LOCK2.8 (B), R118.2
unnamed: LOCK3.3 (DOWN-A), R119.2
unnamed: LOCK3.6 (G), R120.1
unnamed: LOCK3.7 (R), R122.2
unnamed: LOCK3.8 (B), R251.2
unnamed: LOCK4.3 (DOWN-A), R121.2
unnamed: LOCK4.6 (G), R252.1
unnamed: LOCK4.7 (R), R253.2
unnamed: LOCK4.8 (B), R254.2
unnamed: LOCK5.3 (DOWN-A), R123.2
unnamed: LOCK5.6 (G), R255.1
unnamed: LOCK5.7 (R), R256.2
unnamed: LOCK5.8 (B), R257.2
unnamed: LOCK6.3 (DOWN-A), R47.2
unnamed: LOCK6.6 (G), R258.1
unnamed: LOCK6.7 (R), R259.2
unnamed: LOCK6.8 (B), R260.2
unnamed: R21.1, SLIDE4.LEDC (C)
unnamed: R22.1, SLIDE5.LEDC (C)
unnamed: R23.1, SLIDE6.LEDC (C)
unnamed: R24.1, SLIDE3.LEDC (C)
unnamed: R48.1, SLIDE2.LEDC (C)
unnamed: R49.1, SLIDE1.LEDC (C)
SLDADC1: C65.1, SLIDE1.P2 (2); also elsewhere on the board
SLDADC2: C66.1, SLIDE2.P2 (2); also elsewhere on the board
SLDADC3: C67.1, SLIDE3.P2 (2); also elsewhere on the board
SLDADC4: C68.1, SLIDE4.P2 (2); also elsewhere on the board
SLDADC5: C69.1, SLIDE5.P2 (2); also elsewhere on the board
SLDADC6: C70.1, SLIDE6.P2 (2); also elsewhere on the board
SLLED1: SLIDE1.LEDA (A); also elsewhere on the board
SLLED2: SLIDE2.LEDA (A); also elsewhere on the board
SLLED3: SLIDE3.LEDA (A); also elsewhere on the board
SLLED4: SLIDE4.LEDA (A); also elsewhere on the board
SLLED5: SLIDE5.LEDA (A); also elsewhere on the board
SLLED6: SLIDE6.LEDA (A); also elsewhere on the board

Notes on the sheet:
Sheet 3: Channel Controls

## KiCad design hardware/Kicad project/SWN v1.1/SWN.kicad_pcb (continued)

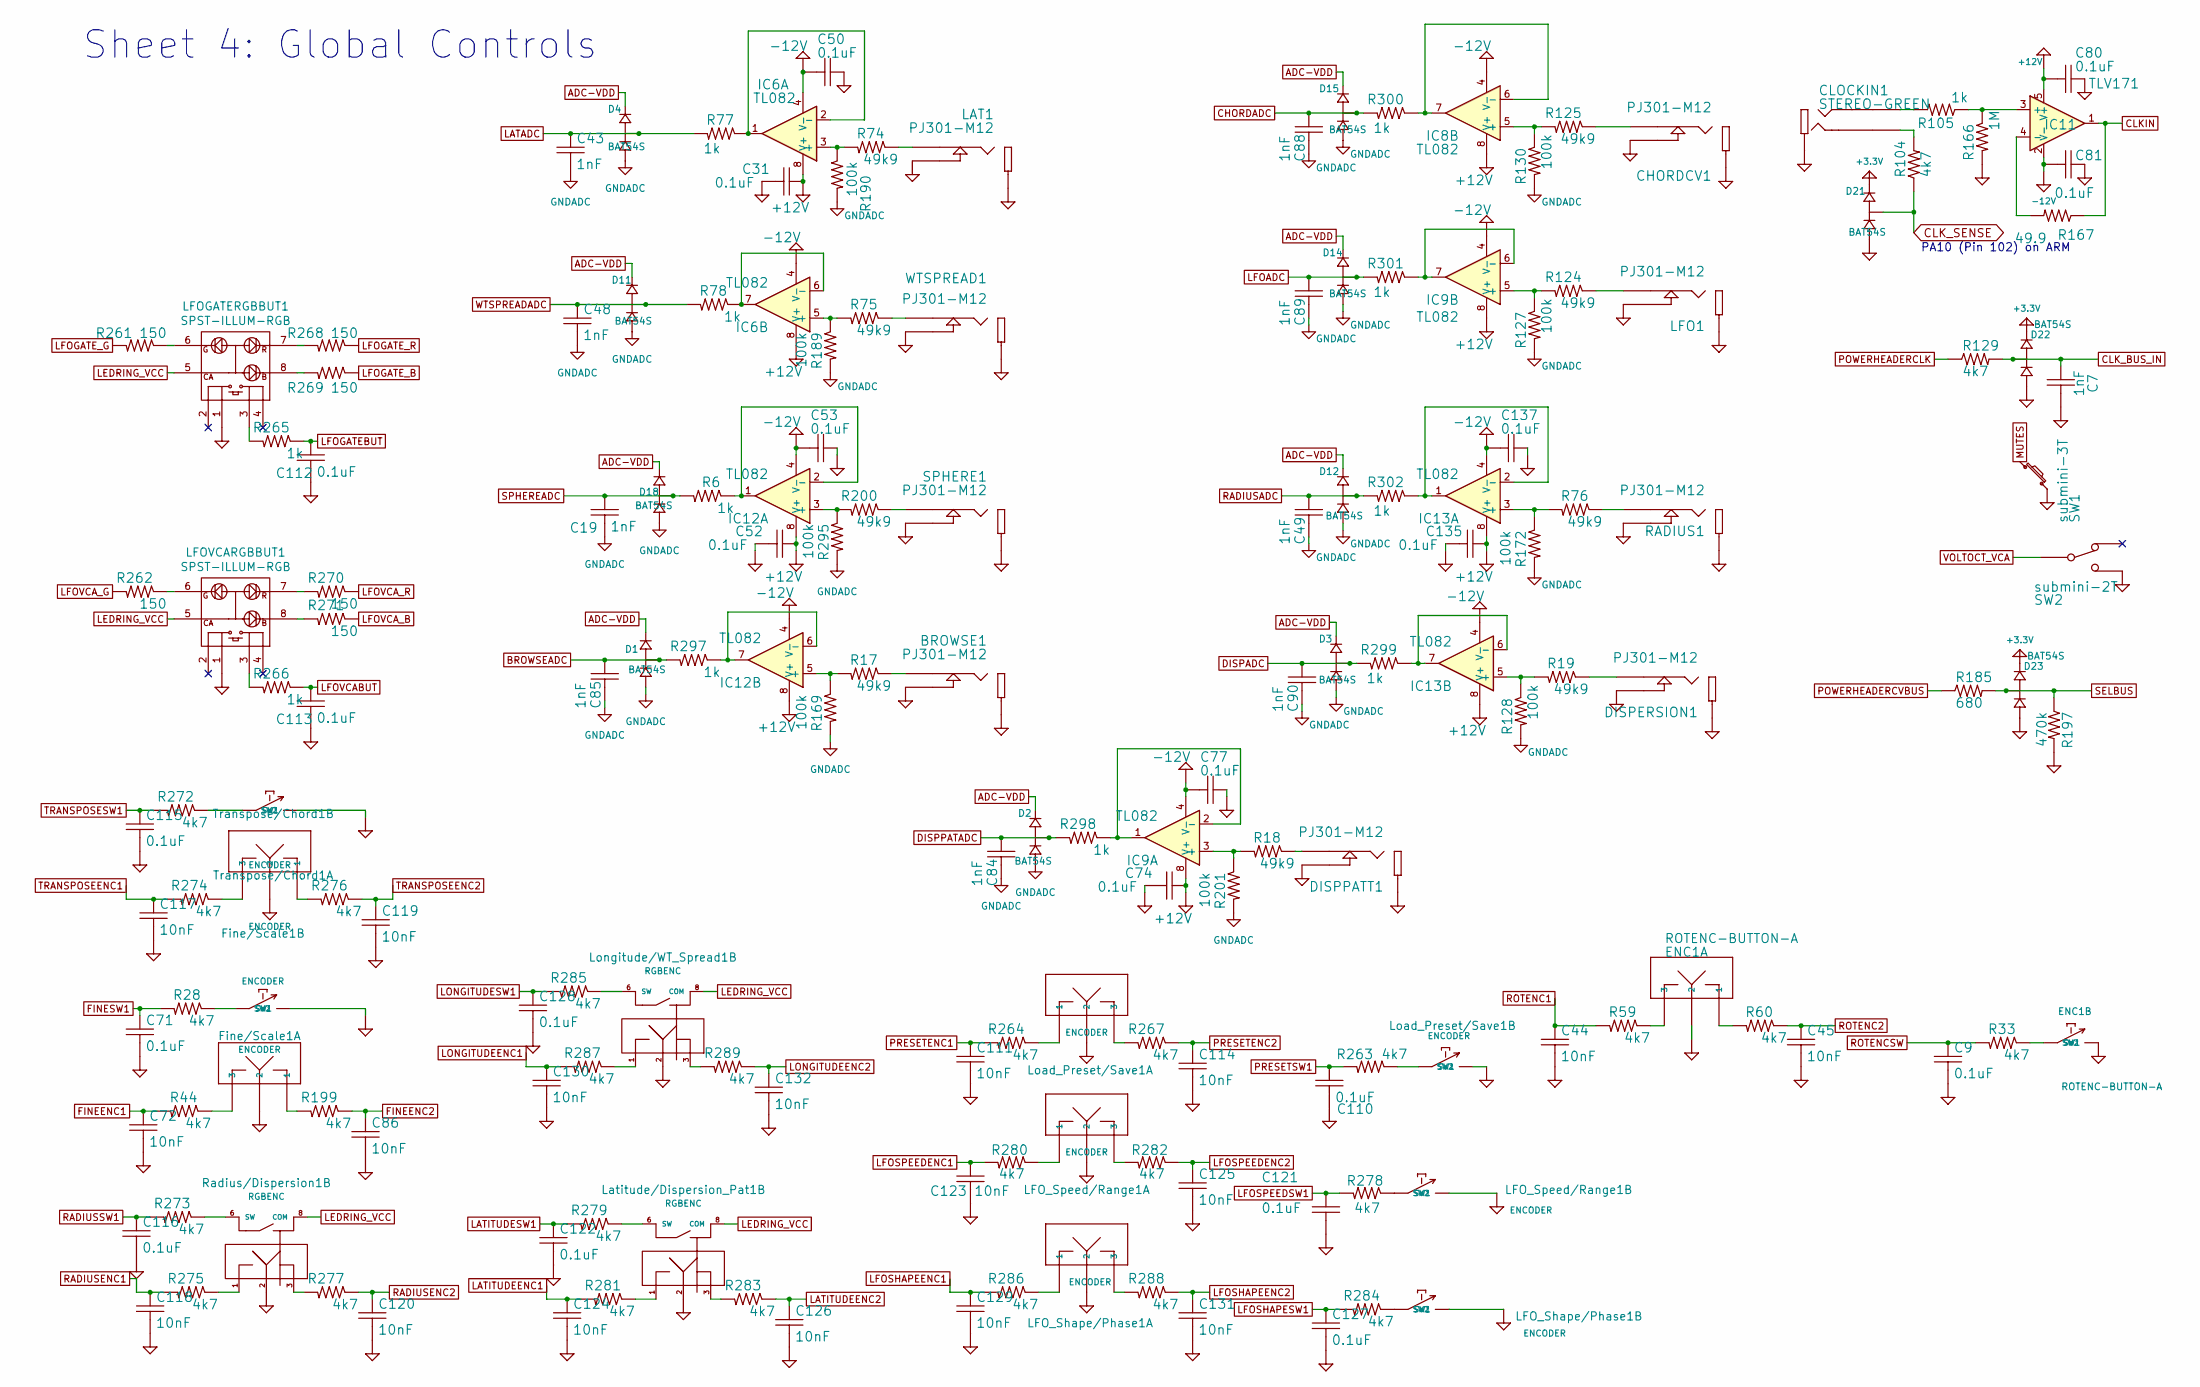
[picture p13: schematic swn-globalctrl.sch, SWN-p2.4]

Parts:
BROWSE1: PJ301-M12; PJ301M-12
C7, C19, C43, C48, C49, C84, C85, C88, C89, C90: 1nF; C0603
C9, C31, C50, C52, C53, C71, C74, C77, C80, C81, C110, C112, C113, C115, C116, C121, C122, C127, C128, C135, C137: 0.1uF; C0603
C44, C45, C72, C86, C111, C114, C117, C118, C119, C120, C123, C124, C125, C126, C129, C130, C131, C132: 10nF; C0603
CHORDCV1: PJ301-M12; PJ301M-12
CLOCKIN1: STEREO-GREEN; PJ301M-12
D1, D2, D3, D4, D11, D12, D14, D15, D18, D21, D22, D23: BAT54S; SOT23
DISPERSION1: PJ301-M12; PJ301M-12
DISPPATT1: PJ301-M12; PJ301M-12
ENC1: ROTENC-BUTTON-A; ENC_SPST_12mm_NUDGED
Fine/Scale1: ENCODER; ENC_RGB_SPST_12mm_NUDGED
IC6, IC8, IC9, IC12, IC13: TL082; TSSOP-8_4.4x3mm_Pitch0.65mm
IC11: TLV171; SOT-23-5
LAT1: PJ301-M12; PJ301M-12
LFO1: PJ301-M12; PJ301M-12
LFOGATERGBBUT1: SPST-ILLUM-RGB; RGB-SPST-LED-TC002
LFOVCARGBBUT1: SPST-ILLUM-RGB; RGB-SPST-LED-TC002
LFO_Shape/Phase1: ENCODER; ENC_SPST_12mm_NUDGED
LFO_Speed/Range1: ENCODER; ENC_SPST_12mm_NUDGED
Latitude/Dispersion_Pat1: RGBENC; ENC_RGB_SPST_12mm_NUDGED
Load_Preset/Save1: ENCODER; ENC_SPST_12mm_NUDGED
Longitude/WT_Spread1: RGBENC; ENC_RGB_SPST_12mm_NUDGED
R6, R77, R78, R105, R265, R266, R297, R298, R299, R300, R301, R302: 1k; R0603
R17, R18, R19, R74, R75, R76, R124, R125, R200: 49k9; R0603
R28, R33, R44, R59, R60, R104, R129, R199, R263, R264, R267, R272, R273, R274, R275, R276, R277, R278, R279, R280, R281, R282, R283, R284, R285, R286, R287, R288, R289: 4k7; R0603
R127, R128, R130, R169, R172, R189, R190, R201, R295: 100k; R0603
R166: 1M; R0603
R167: 49.9; R0603
R185: 680; R0603
R197: 470k; R0603
R261, R262, R268, R269, R270, R271: 150; R0603
RADIUS1: PJ301-M12; PJ301M-12
Radius/Dispersion1: RGBENC; ENC_RGB_SPST_12mm_NUDGED
SPHERE1: PJ301-M12; PJ301M-12
SW1: submini-3T; Switch_Toggle_SPST_SubMini
SW2: submini-2T; SPDT-SUB
Transpose/Chord1: ENCODER; ENC_SPST_12mm_NUDGED
WTSPREAD1: PJ301-M12; PJ301M-12

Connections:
+3.3V: D21.2 (CATHODE), D22.2 (CATHODE), D23.2 (CATHODE); also elsewhere on the board
+12V: C31.1, C52.1, C74.1, C80.2, C135.1, IC6.8 (V+), IC8.8 (V+), IC9.8 (V+), IC11.5 (V+), IC12.8 (V+), IC13.8 (V+); also elsewhere on the board
-12V: C50.2, C53.2, C77.2, C81.2, C137.2, IC6.4 (V-), IC8.4 (V-), IC9.4 (V-), IC11.2 (V-), IC12.4 (V-), IC13.4 (V-); also elsewhere on the board
ADC-VDD: D1.2 (CATHODE), D2.2 (CATHODE), D3.2 (CATHODE), D4.2 (CATHODE), D11.2 (CATHODE), D12.2 (CATHODE), D14.2 (CATHODE), D15.2 (CATHODE), D18.2 (CATHODE); also elsewhere on the board
BROWSEADC: C85.1, D1.3 (COMMON), R297.2; also elsewhere on the board
CHORDADC: C88.1, D15.3 (COMMON), R300.2; also elsewhere on the board
CLKIN: IC11.1, R167.1; also elsewhere on the board
CLK_BUS_IN: C7.1, D22.3 (COMMON), R129.2; also elsewhere on the board
CLK_SENSE: D21.3 (COMMON), R104.1; also elsewhere on the board
DISPADC: C90.1, D3.3 (COMMON), R299.2; also elsewhere on the board
DISPPATADC: C84.1, D2.3 (COMMON), R298.2; also elsewhere on the board
FINEENC1: C72.1, R44.2; also elsewhere on the board
FINEENC2: C86.1, R199.1; also elsewhere on the board
FINESW1: C71.1, R28.2; also elsewhere on the board
GNDADC: C19.2, C43.2, C48.2, C49.2, C84.2, C85.2, C88.2, C89.2, C90.2, D1.1 (ANODE), D2.1 (ANODE), D3.1 (ANODE), D4.1 (ANODE), D11.1 (ANODE), D12.1 (ANODE), D14.1 (ANODE), D15.1 (ANODE), D18.1 (ANODE), R127.2, R128.2, R130.2, R169.2, R172.2, R189.2, R190.2, R201.2, R295.2; also elsewhere on the board
LATADC: C43.1, D4.3 (COMMON), R77.2; also elsewhere on the board
LATITUDEENC1: C124.1, R281.2; also elsewhere on the board
LATITUDEENC2: C126.1, R283.1; also elsewhere on the board
LATITUDESW1: C122.1, R279.2; also elsewhere on the board
LEDRING_VCC: LFOGATERGBBUT1.5 (CA), LFOVCARGBBUT1.5 (CA), Latitude/Dispersion_Pat1.8, Longitude/WT_Spread1.8, Radius/Dispersion1.8; also elsewhere on the board
LFOADC: C89.1, D14.3 (COMMON), R301.2; also elsewhere on the board
LFOGATEBUT: C112.1, R265.1; also elsewhere on the board
LFOGATE_B: R269.1; also elsewhere on the board
LFOGATE_G: R261.2; also elsewhere on the board
LFOGATE_R: R268.1; also elsewhere on the board
LFOSHAPEENC1: C129.1, R286.2; also elsewhere on the board
LFOSHAPEENC2: C131.1, R288.1; also elsewhere on the board
LFOSHAPESW1: C127.1, R284.2; also elsewhere on the board
LFOSPEEDENC1: C123.1, R280.2; also elsewhere on the board
LFOSPEEDENC2: C125.1, R282.1; also elsewhere on the board
LFOSPEEDSW1: C121.1, R278.2; also elsewhere on the board
LFOVCABUT: C113.1, R266.1; also elsewhere on the board
LFOVCA_B: R271.1; also elsewhere on the board
LFOVCA_G: R262.2; also elsewhere on the board
LFOVCA_R: R270.1; also elsewhere on the board
LONGITUDEENC1: C130.1, R287.2; also elsewhere on the board
LONGITUDEENC2: C132.1, R289.1; also elsewhere on the board
LONGITUDESW1: C128.1, R285.2; also elsewhere on the board
MUTES: SW1.2; also elsewhere on the board
unnamed: BROWSE1.1 (TIP), R17.1
unnamed: CHORDCV1.1 (TIP), R125.1
unnamed: CLOCKIN1.1 (TIP), R105.2
unnamed: CLOCKIN1.3 (TIP-SW), R104.2
unnamed: DISPERSION1.1 (TIP), R19.1
unnamed: DISPPATT1.1 (TIP), R18.1
unnamed: ENC1.1, R60.2
unnamed: ENC1.3, R59.1
unnamed: ENC1.SW1, R33.1
unnamed: Fine/Scale1.1, R199.2
unnamed: Fine/Scale1.3, R44.1
unnamed: Fine/Scale1.SW1, R28.1
unnamed: IC6.1, IC6.2 (-), R77.1
unnamed: IC6.3 (+), R74.2, R190.1
unnamed: IC6.5 (+), R75.2, R189.1
unnamed: IC6.6 (-), IC6.7, R78.1
unnamed: IC8.5 (+), R125.2, R130.1
unnamed: IC8.6 (-), IC8.7, R300.1
unnamed: IC9.1, IC9.2 (-), R298.1
unnamed: IC9.3 (+), R18.2, R201.1
unnamed: IC9.5 (+), R124.2, R127.1
unnamed: IC9.6 (-), IC9.7, R301.1
unnamed: IC11.3 (+), R105.1, R166.1
unnamed: IC11.4 (-), R167.2
unnamed: IC12.1, IC12.2 (-), R6.1
unnamed: IC12.3 (+), R200.2, R295.1
unnamed: IC12.5 (+), R17.2, R169.1
unnamed: IC12.6 (-), IC12.7, R297.1
unnamed: IC13.1, IC13.2 (-), R302.1
unnamed: IC13.3 (+), R76.2, R172.1
unnamed: IC13.5 (+), R19.2, R128.1
unnamed: IC13.6 (-), IC13.7, R299.1
unnamed: LAT1.1 (TIP), R74.1
unnamed: LFO1.1 (TIP), R124.1
unnamed: LFOGATERGBBUT1.3 (DOWN-A), R265.2
unnamed: LFOGATERGBBUT1.6 (G), R261.1
unnamed: LFOGATERGBBUT1.7 (R), R268.2
unnamed: LFOGATERGBBUT1.8 (B), R269.2
unnamed: LFOVCARGBBUT1.3 (DOWN-A), R266.2
unnamed: LFOVCARGBBUT1.6 (G), R262.1
unnamed: LFOVCARGBBUT1.7 (R), R270.2
unnamed: LFOVCARGBBUT1.8 (B), R271.2
unnamed: LFO_Shape/Phase1.1, R286.1
unnamed: LFO_Shape/Phase1.3, R288.2
unnamed: LFO_Shape/Phase1.SW1, R284.1
unnamed: LFO_Speed/Range1.1, R280.1
unnamed: LFO_Speed/Range1.3, R282.2
unnamed: LFO_Speed/Range1.SW1, R278.1
unnamed: Latitude/Dispersion_Pat1.1, R281.1
unnamed: Latitude/Dispersion_Pat1.3, R283.2
unnamed: Latitude/Dispersion_Pat1.6 (SW), R279.1
unnamed: Load_Preset/Save1.1, R264.1
unnamed: Load_Preset/Save1.3, R267.2
unnamed: Load_Preset/Save1.SW1, R263.1
unnamed: Longitude/WT_Spread1.1, R287.1
unnamed: Longitude/WT_Spread1.3, R289.2
unnamed: Longitude/WT_Spread1.6 (SW), R285.1
unnamed: R75.1, WTSPREAD1.1 (TIP)
unnamed: R76.1, RADIUS1.1 (TIP)
unnamed: R200.1, SPHERE1.1 (TIP)
unnamed: R272.1, Transpose/Chord1.SW1
unnamed: R273.1, Radius/Dispersion1.6 (SW)
unnamed: R274.1, Transpose/Chord1.3
unnamed: R275.1, Radius/Dispersion1.1
unnamed: R276.2, Transpose/Chord1.1
unnamed: R277.2, Radius/Dispersion1.3
POWERHEADERCLK: R129.1; also elsewhere on the board
POWERHEADERCVBUS: R185.1; also elsewhere on the board
PRESETENC1: C111.1, R264.2; also elsewhere on the board
PRESETENC2: C114.1, R267.1; also elsewhere on the board
PRESETSW1: C110.1, R263.2; also elsewhere on the board
RADIUSADC: C49.1, D12.3 (COMMON), R302.2; also elsewhere on the board
RADIUSENC1: C118.1, R275.2; also elsewhere on the board
RADIUSENC2: C120.1, R277.1; also elsewhere on the board
RADIUSSW1: C116.1, R273.2; also elsewhere on the board
ROTENC1: C44.1, R59.2; also elsewhere on the board
ROTENC2: C45.1, R60.1; also elsewhere on the board
ROTENCSW: C9.1, R33.2; also elsewhere on the board
SELBUS: D23.3 (COMMON), R185.2, R197.1; also elsewhere on the board
SPHEREADC: C19.1, D18.3 (COMMON), R6.2; also elsewhere on the board
TRANSPOSEENC1: C117.1, R274.2; also elsewhere on the board
TRANSPOSEENC2: C119.1, R276.1; also elsewhere on the board
TRANSPOSESW1: C115.1, R272.2; also elsewhere on the board
VOLTOCT_VCA: SW2.2; also elsewhere on the board
WTSPREADADC: C48.1, D11.3 (COMMON), R78.2; also elsewhere on the board

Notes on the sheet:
Sheet 4: Global Controls
PA10 (Pin 102) on ARM

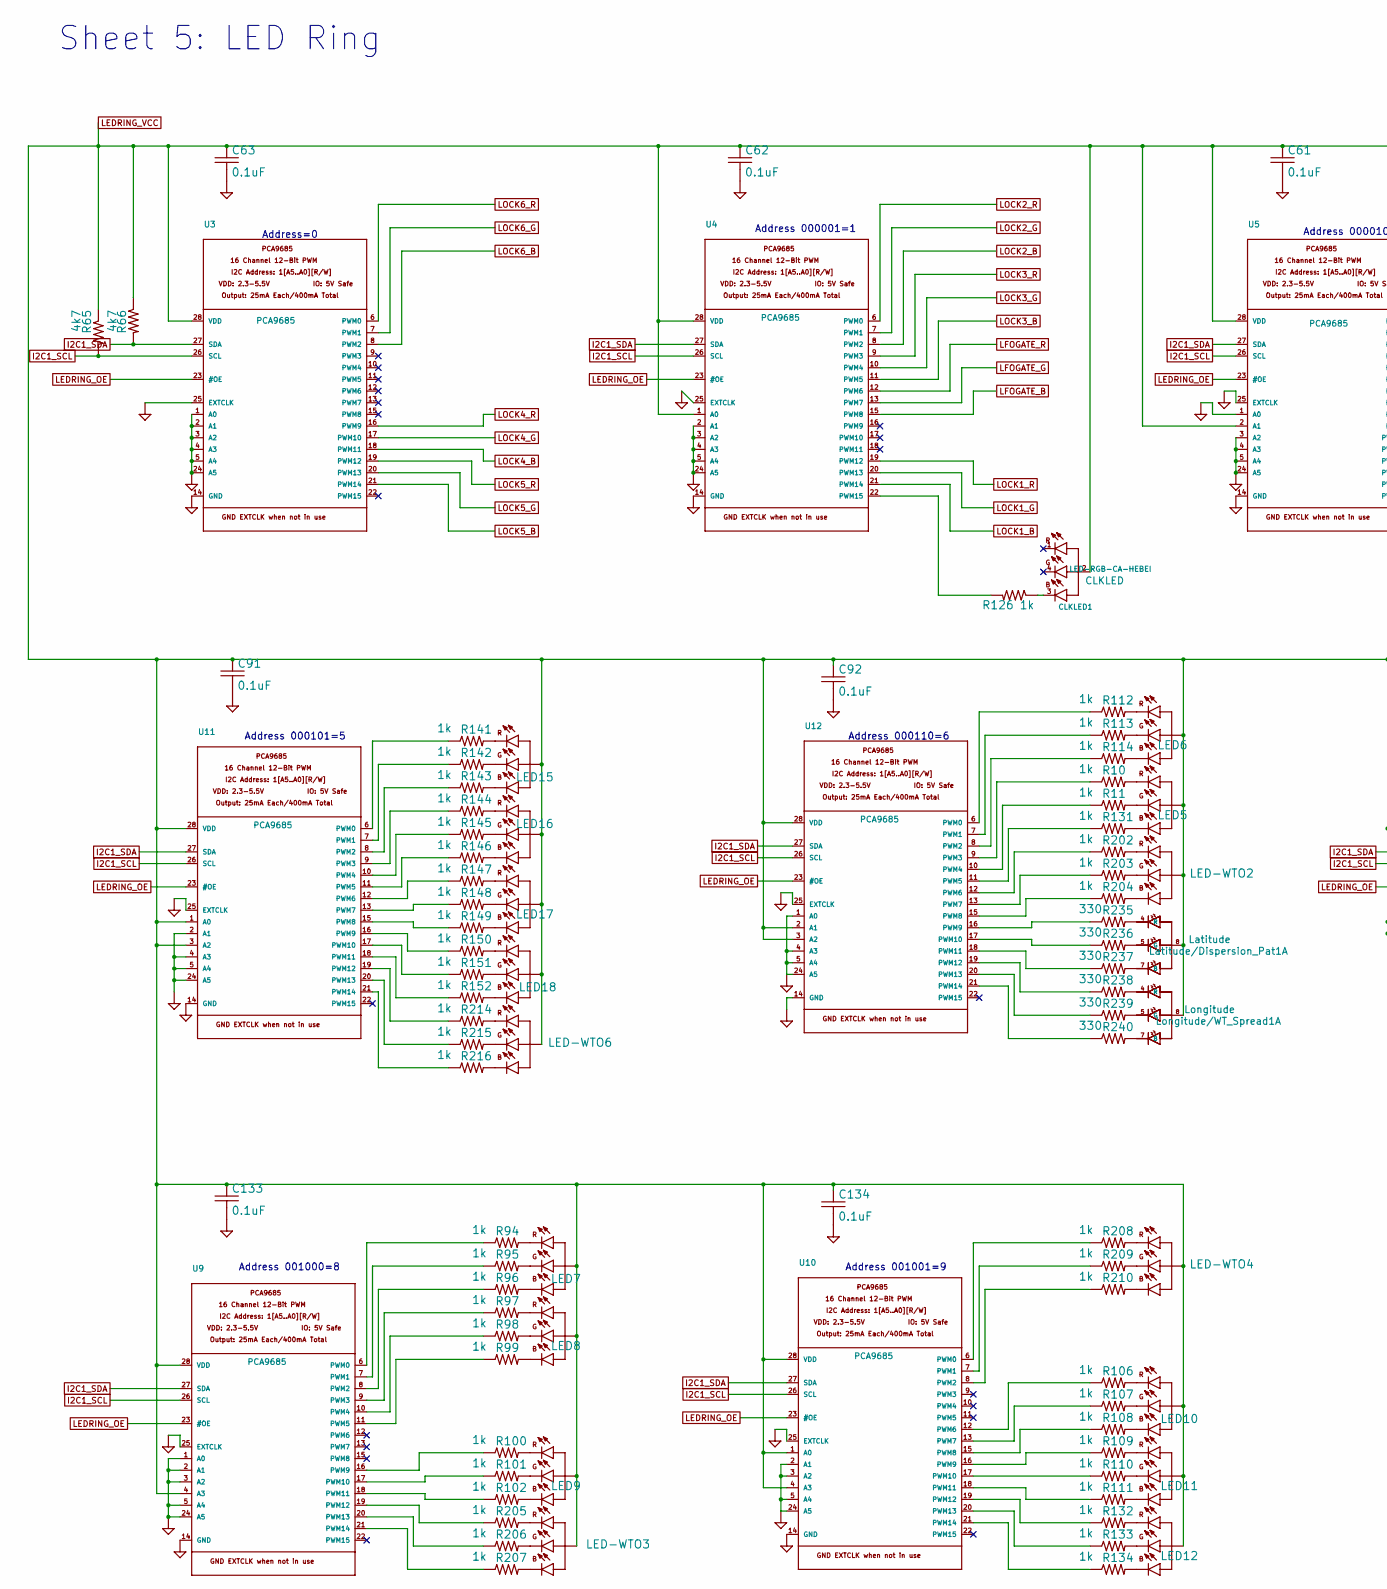
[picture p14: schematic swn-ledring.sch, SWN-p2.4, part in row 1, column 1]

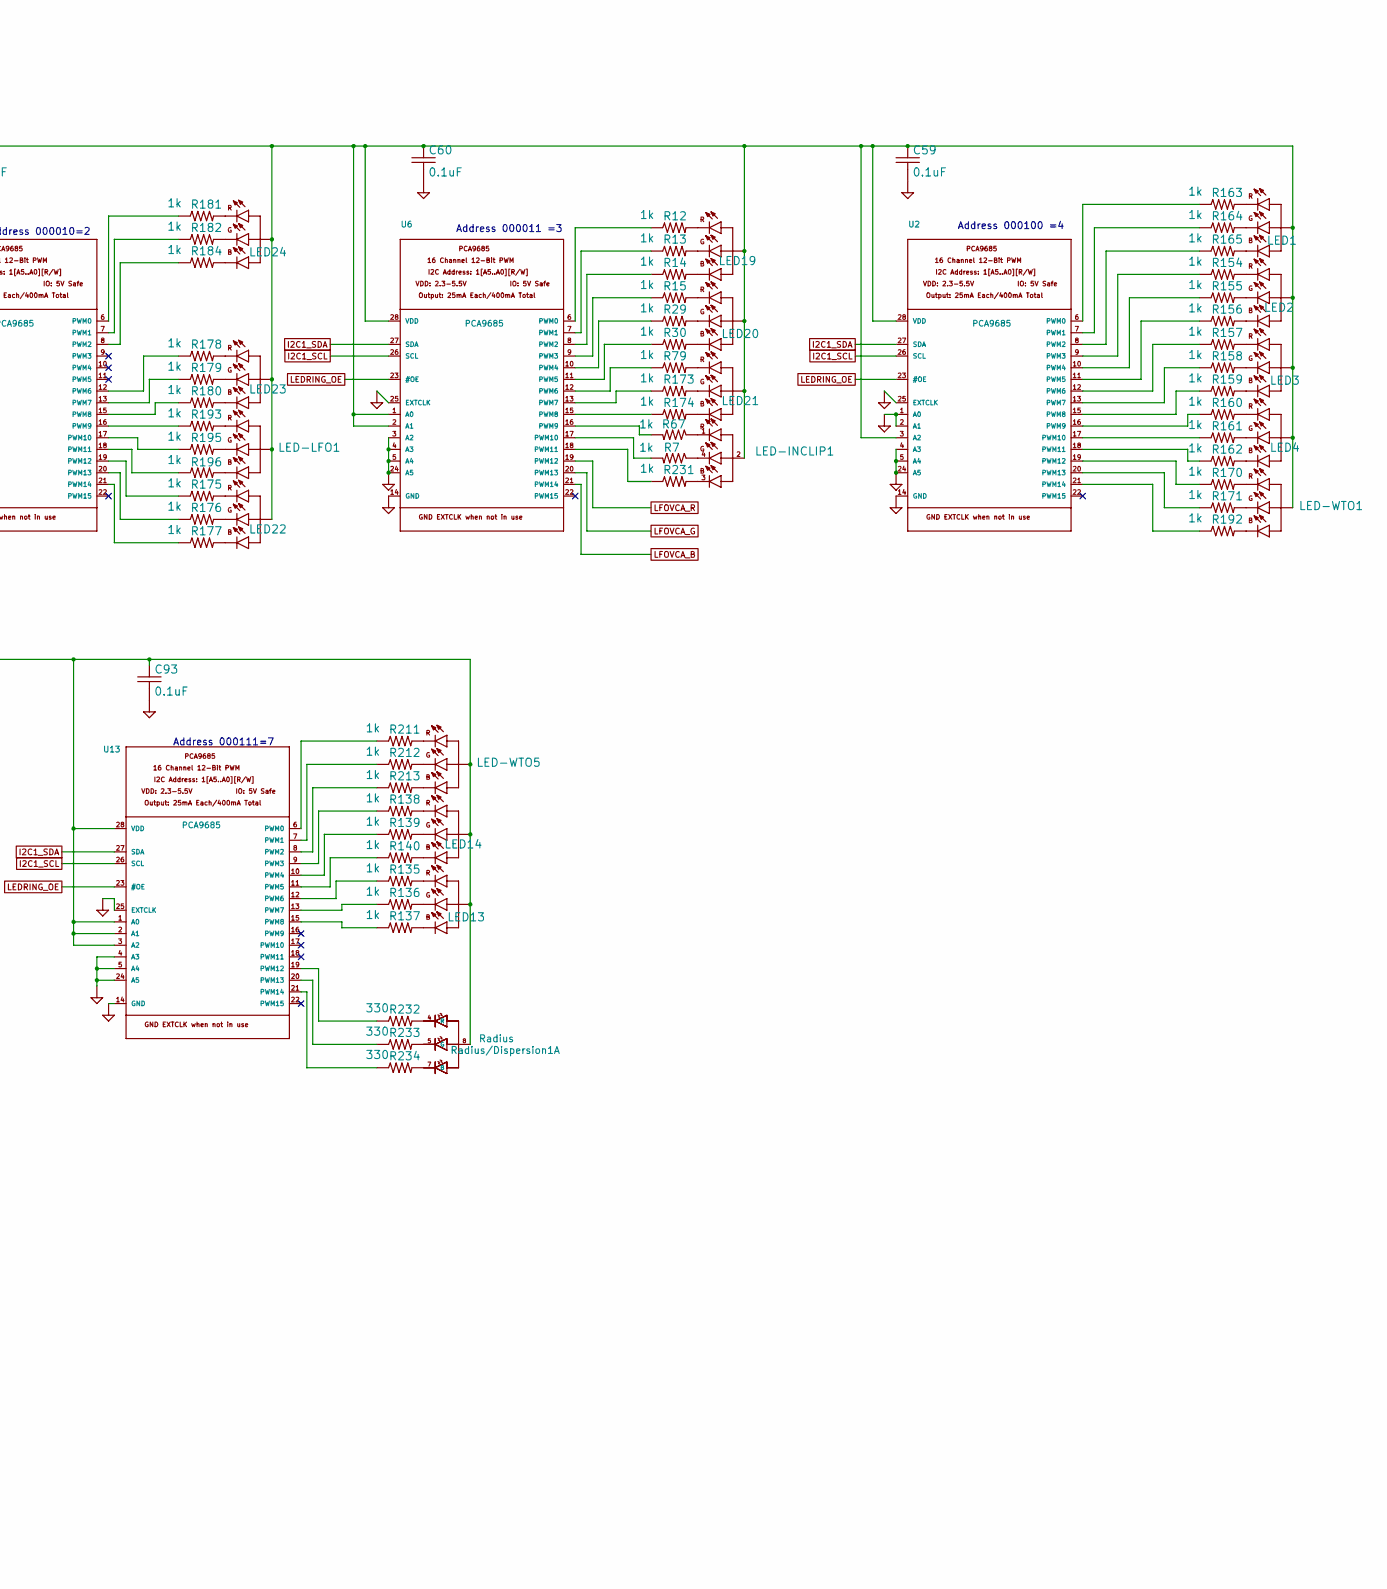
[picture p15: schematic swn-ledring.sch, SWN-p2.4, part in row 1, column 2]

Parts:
C59, C60, C61, C62, C63, C91, C92, C93, C133, C134: 0.1uF; C0603
CLKLED1: LED-RGB-CA-HEBEI; LED_PLCC-4
LED1, LED2, LED3, LED4, LED5, LED6, LED7, LED8, LED9, LED10, LED11, LED12, LED13, LED14, LED15, LED16, LED17, LED18, LED19, LED20, LED21, LED22, LED23, LED24: LED-RGB-CA-HEBEI; LED_PLCC-4
LED-INCLIP1: LED-RGB-CA-HEBEI; LED_PLCC-4
LED-LFO1: LED-RGB-CA-HEBEI; LED_PLCC-4
LED-WTO1, LED-WTO2, LED-WTO3, LED-WTO4, LED-WTO5, LED-WTO6: LED-RGB-CA-HEBEI; LED_PLCC-4
Latitude/Dispersion_Pat1: RGBENC; ENC_RGB_SPST_12mm_NUDGED
Longitude/WT_Spread1: RGBENC; ENC_RGB_SPST_12mm_NUDGED
R7, R10, R11, R12, R13, R14, R15, R29, R30, R67, R79, R94, R95, R96, R97, R98, R99, R100, R101, R102, R106, R107, R108, R109, R110, R111, R112, R113, R114, R126, R131, R132, R133, R134, R135, R136, R137, R138, R139, R140, R141, R142, R143, R144, R145, R146, R147, R148, R149, R150, R151, R152, R154, R155, R156, R157, R158, R159, R160, R161, R162, R163, R164, R165, R170, R171, R173, R174, R175, R176, R177, R178, R179, R180, R181, R182, R184, R192, R193, R195, R196, R202, R203, R204, R205, R206, R207, R208, R209, R210, R211, R212, R213, R214, R215, R216, R231: 1k; R0603
R65, R66: 4k7; R0603
R232, R233, R234, R235, R236, R237, R238, R239, R240: 330; R0603
Radius/Dispersion1: RGBENC; ENC_RGB_SPST_12mm_NUDGED
U2, U3, U4, U5, U6, U9, U10, U11, U12, U13: PCA9685; TSSOP-28_4.4x9.7mm_Pitch0.65mm

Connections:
I2C1_SCL: R65.2, U2.26 (SCL), U3.26 (SCL), U4.26 (SCL), U5.26 (SCL), U6.26 (SCL), U9.26 (SCL), U10.26 (SCL), U11.26 (SCL), U12.26 (SCL), U13.26 (SCL); also elsewhere on the board
I2C1_SDA: R66.2, U2.27 (SDA), U3.27 (SDA), U4.27 (SDA), U5.27 (SDA), U6.27 (SDA), U9.27 (SDA), U10.27 (SDA), U11.27 (SDA), U12.27 (SDA), U13.27 (SDA); also elsewhere on the board
LEDRING_OE: U2.23 (#OE), U3.23 (#OE), U4.23 (#OE), U5.23 (#OE), U6.23 (#OE), U9.23 (#OE), U10.23 (#OE), U11.23 (#OE), U12.23 (#OE), U13.23 (#OE); also elsewhere on the board
LEDRING_VCC: C59.1, C60.1, C61.1, C62.1, C63.1, C91.1, C92.1, C93.1, C133.1, C134.1, CLKLED1.2 (A), LED1.2 (A), LED2.2 (A), LED3.2 (A), LED4.2 (A), LED5.2 (A), LED6.2 (A), LED7.2 (A), LED8.2 (A), LED9.2 (A), LED10.2 (A), LED11.2 (A), LED12.2 (A), LED13.2 (A), LED14.2 (A), LED15.2 (A), LED16.2 (A), LED17.2 (A), LED18.2 (A), LED19.2 (A), LED20.2 (A), LED21.2 (A), LED22.2 (A), LED23.2 (A), LED24.2 (A), LED-INCLIP1.2 (A), LED-LFO1.2 (A), LED-WTO1.2 (A), LED-WTO2.2 (A), LED-WTO3.2 (A), LED-WTO4.2 (A), LED-WTO5.2 (A), LED-WTO6.2 (A), Latitude/Dispersion_Pat1.8, Longitude/WT_Spread1.8, R65.1, R66.1, Radius/Dispersion1.8, U2.3 (A2), U2.28 (VDD), U3.28 (VDD), U4.1 (A0), U4.28 (VDD), U5.2 (A1), U5.28 (VDD), U6.1 (A0), U6.2 (A1), U6.28 (VDD), U9.4 (A3), U9.28 (VDD), U10.1 (A0), U10.4 (A3), U10.28 (VDD), U11.1 (A0), U11.3 (A2), U11.28 (VDD), U12.2 (A1), U12.3 (A2), U12.28 (VDD), U13.1 (A0), U13.2 (A1), U13.3 (A2), U13.28 (VDD); also elsewhere on the board
LFOGATE_B: U4.15 (PWM8); also elsewhere on the board
LFOGATE_G: U4.13 (PWM7); also elsewhere on the board
LFOGATE_R: U4.12 (PWM6); also elsewhere on the board
LFOVCA_B: U6.21 (PWM14); also elsewhere on the board
LFOVCA_G: U6.20 (PWM13); also elsewhere on the board
LFOVCA_R: U6.19 (PWM12); also elsewhere on the board
LOCK1_B: U4.21 (PWM14); also elsewhere on the board
LOCK1_G: U4.20 (PWM13); also elsewhere on the board
LOCK1_R: U4.19 (PWM12); also elsewhere on the board
LOCK2_B: U4.8 (PWM2); also elsewhere on the board
LOCK2_G: U4.7 (PWM1); also elsewhere on the board
LOCK2_R: U4.6 (PWM0); also elsewhere on the board
LOCK3_B: U4.11 (PWM5); also elsewhere on the board
LOCK3_G: U4.10 (PWM4); also elsewhere on the board
LOCK3_R: U4.9 (PWM3); also elsewhere on the board
LOCK4_B: U3.18 (PWM11); also elsewhere on the board
LOCK4_G: U3.17 (PWM10); also elsewhere on the board
LOCK4_R: U3.16 (PWM9); also elsewhere on the board
LOCK5_B: U3.21 (PWM14); also elsewhere on the board
LOCK5_G: U3.20 (PWM13); also elsewhere on the board
LOCK5_R: U3.19 (PWM12); also elsewhere on the board
LOCK6_B: U3.8 (PWM2); also elsewhere on the board
LOCK6_G: U3.7 (PWM1); also elsewhere on the board
LOCK6_R: U3.6 (PWM0); also elsewhere on the board
unnamed: CLKLED1.3 (CB), R126.1
unnamed: LED1.1 (CR), R163.2
unnamed: LED1.3 (CB), R165.2
unnamed: LED1.4 (CG), R164.2
unnamed: LED2.1 (CR), R154.2
unnamed: LED2.3 (CB), R156.2
unnamed: LED2.4 (CG), R155.2
unnamed: LED3.1 (CR), R157.2
unnamed: LED3.3 (CB), R159.2
unnamed: LED3.4 (CG), R158.2
unnamed: LED4.1 (CR), R160.2
unnamed: LED4.3 (CB), R162.2
unnamed: LED4.4 (CG), R161.2
unnamed: LED5.1 (CR), R10.2
unnamed: LED5.3 (CB), R131.2
unnamed: LED5.4 (CG), R11.2
unnamed: LED6.1 (CR), R112.2
unnamed: LED6.3 (CB), R114.2
unnamed: LED6.4 (CG), R113.2
unnamed: LED7.1 (CR), R94.2
unnamed: LED7.3 (CB), R96.2
unnamed: LED7.4 (CG), R95.2
unnamed: LED8.1 (CR), R97.2
unnamed: LED8.3 (CB), R99.2
unnamed: LED8.4 (CG), R98.2
unnamed: LED9.1 (CR), R100.2
unnamed: LED9.3 (CB), R102.2
unnamed: LED9.4 (CG), R101.2
unnamed: LED10.1 (CR), R106.2
unnamed: LED10.3 (CB), R108.2
unnamed: LED10.4 (CG), R107.2
unnamed: LED11.1 (CR), R109.2
unnamed: LED11.3 (CB), R111.2
unnamed: LED11.4 (CG), R110.2
unnamed: LED12.1 (CR), R132.2
unnamed: LED12.3 (CB), R134.2
unnamed: LED12.4 (CG), R133.2
unnamed: LED13.1 (CR), R135.2
unnamed: LED13.3 (CB), R137.2
unnamed: LED13.4 (CG), R136.2
unnamed: LED14.1 (CR), R138.2
unnamed: LED14.3 (CB), R140.2
unnamed: LED14.4 (CG), R139.2
unnamed: LED15.1 (CR), R141.2
unnamed: LED15.3 (CB), R143.2
unnamed: LED15.4 (CG), R142.2
unnamed: LED16.1 (CR), R144.2
unnamed: LED16.3 (CB), R146.2
unnamed: LED16.4 (CG), R145.2
unnamed: LED17.1 (CR), R147.2
unnamed: LED17.3 (CB), R149.2
unnamed: LED17.4 (CG), R148.2
unnamed: LED18.1 (CR), R150.2
unnamed: LED18.3 (CB), R152.2
unnamed: LED18.4 (CG), R151.2
unnamed: LED19.1 (CR), R12.2
unnamed: LED19.3 (CB), R14.2
unnamed: LED19.4 (CG), R13.2
unnamed: LED20.1 (CR), R15.2
unnamed: LED20.3 (CB), R30.2
unnamed: LED20.4 (CG), R29.2
unnamed: LED21.1 (CR), R79.2
unnamed: LED21.3 (CB), R174.2
unnamed: LED21.4 (CG), R173.2
unnamed: LED22.1 (CR), R175.2
unnamed: LED22.3 (CB), R177.2
unnamed: LED22.4 (CG), R176.2
unnamed: LED23.1 (CR), R178.2
unnamed: LED23.3 (CB), R180.2
unnamed: LED23.4 (CG), R179.2
unnamed: LED24.1 (CR), R181.2
unnamed: LED24.3 (CB), R184.2
unnamed: LED24.4 (CG), R182.2
unnamed: LED-INCLIP1.1 (CR), R67.1
unnamed: LED-INCLIP1.3 (CB), R231.2
unnamed: LED-INCLIP1.4 (CG), R7.1
unnamed: LED-LFO1.1 (CR), R193.2
unnamed: LED-LFO1.3 (CB), R196.2
unnamed: LED-LFO1.4 (CG), R195.2
unnamed: LED-WTO1.1 (CR), R170.2
unnamed: LED-WTO1.3 (CB), R192.2
unnamed: LED-WTO1.4 (CG), R171.2
unnamed: LED-WTO2.1 (CR), R202.2
unnamed: LED-WTO2.3 (CB), R204.2
unnamed: LED-WTO2.4 (CG), R203.2
unnamed: LED-WTO3.1 (CR), R205.2
unnamed: LED-WTO3.3 (CB), R207.2
unnamed: LED-WTO3.4 (CG), R206.2
unnamed: LED-WTO4.1 (CR), R208.2
unnamed: LED-WTO4.3 (CB), R210.2
unnamed: LED-WTO4.4 (CG), R209.2
unnamed: LED-WTO5.1 (CR), R211.2
unnamed: LED-WTO5.3 (CB), R213.2
unnamed: LED-WTO5.4 (CG), R212.2
unnamed: LED-WTO6.1 (CR), R214.2
unnamed: LED-WTO6.3 (CB), R216.2
unnamed: LED-WTO6.4 (CG), R215.2
unnamed: Latitude/Dispersion_Pat1.4 (R), R235.2
unnamed: Latitude/Dispersion_Pat1.5 (G), R236.2
unnamed: Latitude/Dispersion_Pat1.7 (B), R237.2
unnamed: Longitude/WT_Spread1.4 (R), R238.2
unnamed: Longitude/WT_Spread1.5 (G), R239.2
unnamed: Longitude/WT_Spread1.7 (B), R240.2
unnamed: R7.2, U6.17 (PWM10)
unnamed: R10.1, U12.9 (PWM3)
unnamed: R11.1, U12.10 (PWM4)
unnamed: R12.1, U6.6 (PWM0)
unnamed: R13.1, U6.7 (PWM1)
unnamed: R14.1, U6.8 (PWM2)
unnamed: R15.1, U6.9 (PWM3)
unnamed: R29.1, U6.10 (PWM4)
unnamed: R30.1, U6.11 (PWM5)
unnamed: R67.2, U6.16 (PWM9)
unnamed: R79.1, U6.12 (PWM6)
unnamed: R94.1, U9.6 (PWM0)
unnamed: R95.1, U9.7 (PWM1)
unnamed: R96.1, U9.8 (PWM2)
unnamed: R97.1, U9.9 (PWM3)
unnamed: R98.1, U9.10 (PWM4)
unnamed: R99.1, U9.11 (PWM5)
unnamed: R100.1, U9.16 (PWM9)
unnamed: R101.1, U9.17 (PWM10)
unnamed: R102.1, U9.18 (PWM11)
unnamed: R106.1, U10.12 (PWM6)
unnamed: R107.1, U10.13 (PWM7)
unnamed: R108.1, U10.15 (PWM8)
unnamed: R109.1, U10.16 (PWM9)
unnamed: R110.1, U10.17 (PWM10)
unnamed: R111.1, U10.18 (PWM11)
unnamed: R112.1, U12.6 (PWM0)
unnamed: R113.1, U12.7 (PWM1)
unnamed: R114.1, U12.8 (PWM2)
unnamed: R126.2, U4.22 (PWM15)
unnamed: R131.1, U12.11 (PWM5)
unnamed: R132.1, U10.19 (PWM12)
unnamed: R133.1, U10.20 (PWM13)
unnamed: R134.1, U10.21 (PWM14)
unnamed: R135.1, U13.12 (PWM6)
unnamed: R136.1, U13.13 (PWM7)
unnamed: R137.1, U13.15 (PWM8)
unnamed: R138.1, U13.9 (PWM3)
unnamed: R139.1, U13.10 (PWM4)
unnamed: R140.1, U13.11 (PWM5)
unnamed: R141.1, U11.6 (PWM0)
unnamed: R142.1, U11.7 (PWM1)
unnamed: R143.1, U11.8 (PWM2)
unnamed: R144.1, U11.9 (PWM3)
unnamed: R145.1, U11.10 (PWM4)
unnamed: R146.1, U11.11 (PWM5)
unnamed: R147.1, U11.12 (PWM6)
unnamed: R148.1, U11.13 (PWM7)
unnamed: R149.1, U11.15 (PWM8)
unnamed: R150.1, U11.16 (PWM9)
unnamed: R151.1, U11.17 (PWM10)
unnamed: R152.1, U11.18 (PWM11)
unnamed: R154.1, U2.9 (PWM3)
unnamed: R155.1, U2.10 (PWM4)
unnamed: R156.1, U2.11 (PWM5)
unnamed: R157.1, U2.12 (PWM6)
unnamed: R158.1, U2.13 (PWM7)
unnamed: R159.1, U2.15 (PWM8)
unnamed: R160.1, U2.16 (PWM9)
unnamed: R161.1, U2.17 (PWM10)
unnamed: R162.1, U2.18 (PWM11)
unnamed: R163.1, U2.6 (PWM0)
unnamed: R164.1, U2.7 (PWM1)
unnamed: R165.1, U2.8 (PWM2)
unnamed: R170.1, U2.19 (PWM12)
unnamed: R171.1, U2.20 (PWM13)
unnamed: R173.1, U6.13 (PWM7)
unnamed: R174.1, U6.15 (PWM8)
unnamed: R175.1, U5.19 (PWM12)
unnamed: R176.1, U5.20 (PWM13)
unnamed: R177.1, U5.21 (PWM14)
unnamed: R178.1, U5.12 (PWM6)
unnamed: R179.1, U5.13 (PWM7)
unnamed: R180.1, U5.15 (PWM8)
unnamed: R181.1, U5.6 (PWM0)
unnamed: R182.1, U5.7 (PWM1)
unnamed: R184.1, U5.8 (PWM2)
unnamed: R192.1, U2.21 (PWM14)
unnamed: R193.1, U5.16 (PWM9)
unnamed: R195.1, U5.17 (PWM10)
unnamed: R196.1, U5.18 (PWM11)
unnamed: R202.1, U12.12 (PWM6)
unnamed: R203.1, U12.13 (PWM7)
unnamed: R204.1, U12.15 (PWM8)
unnamed: R205.1, U9.19 (PWM12)
unnamed: R206.1, U9.20 (PWM13)
unnamed: R207.1, U9.21 (PWM14)
unnamed: R208.1, U10.6 (PWM0)
unnamed: R209.1, U10.7 (PWM1)
unnamed: R210.1, U10.8 (PWM2)
unnamed: R211.1, U13.6 (PWM0)
unnamed: R212.1, U13.7 (PWM1)
unnamed: R213.1, U13.8 (PWM2)
unnamed: R214.1, U11.19 (PWM12)
unnamed: R215.1, U11.20 (PWM13)
unnamed: R216.1, U11.21 (PWM14)
unnamed: R231.1, U6.18 (PWM11)
unnamed: R232.1, U13.19 (PWM12)
unnamed: R232.2, Radius/Dispersion1.4 (R)
unnamed: R233.1, U13.20 (PWM13)
unnamed: R233.2, Radius/Dispersion1.5 (G)
unnamed: R234.1, U13.21 (PWM14)
unnamed: R234.2, Radius/Dispersion1.7 (B)
unnamed: R235.1, U12.16 (PWM9)
unnamed: R236.1, U12.17 (PWM10)
unnamed: R237.1, U12.18 (PWM11)
unnamed: R238.1, U12.19 (PWM12)
unnamed: R239.1, U12.20 (PWM13)
unnamed: R240.1, U12.21 (PWM14)

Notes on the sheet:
Sheet 5: LED Ring
Address 000100 =4
Address 000011 =3
Address 000001=1
Address=0
Address 000010=2
Address 000101=5
Address 000110=6
Address 000111=7
Address 001000=8
Address 001001=9

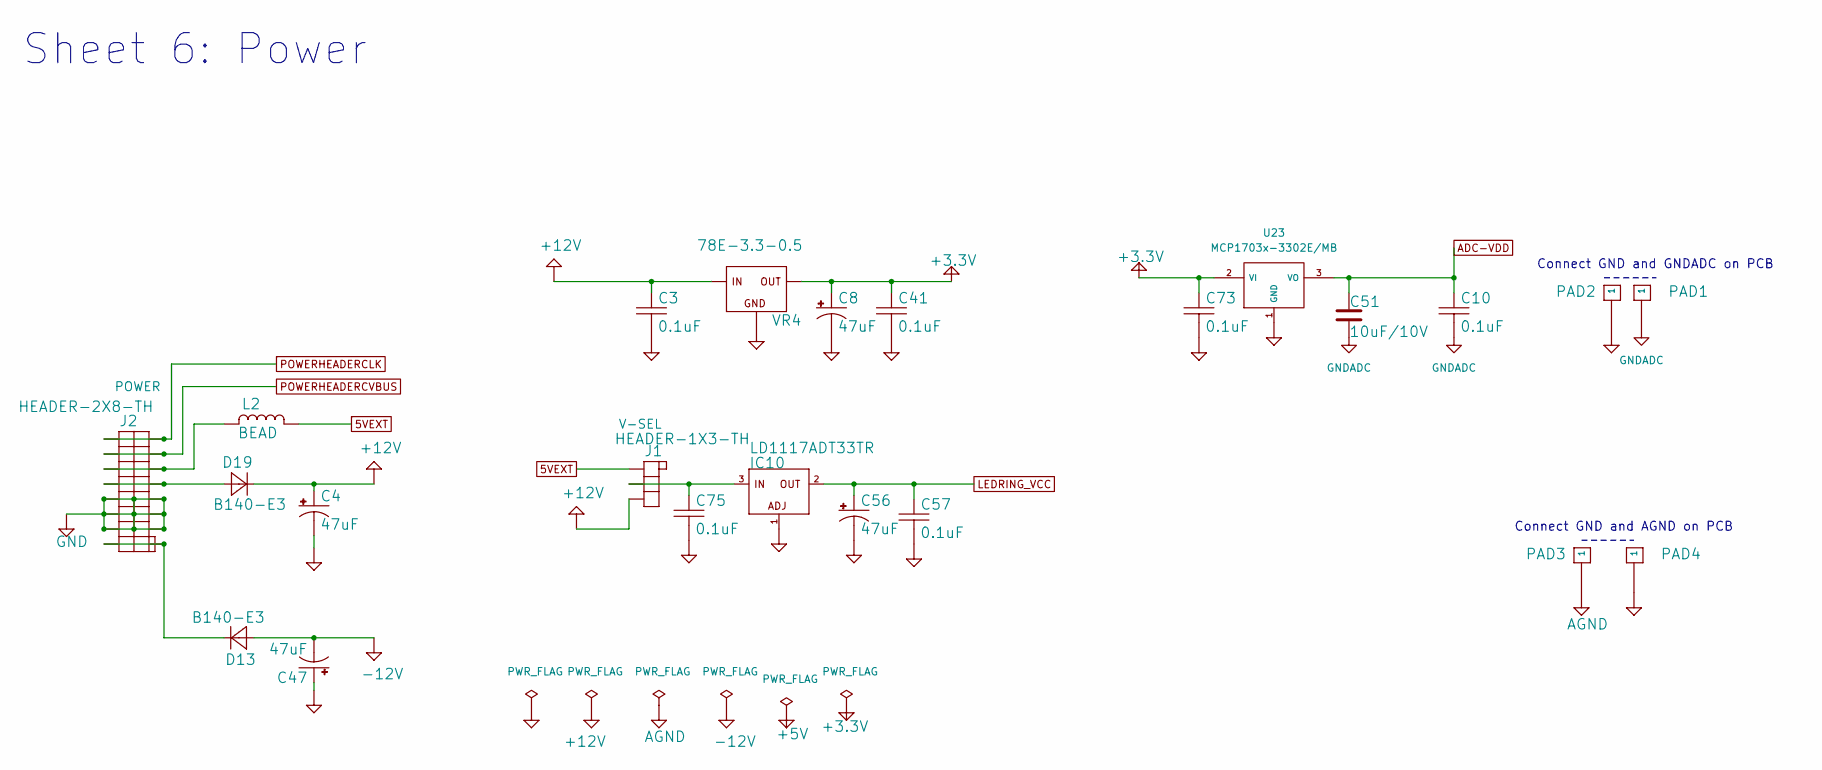
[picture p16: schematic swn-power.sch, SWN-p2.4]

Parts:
C3, C10, C41, C57, C73, C75: 0.1uF; C0603
C4, C8, C47, C56: 47uF; CP_Elec_5x5.3
C51: 10uF/10V; C0603
D13, D19: B140-E3; SMA_Standard
IC10: LD1117ADT33TR; TO-252-2
J1: HEADER-1X3-TH; Pins_1x03_2.54mm_TH
J2: HEADER-2X8-TH; HEADER-2X8-TH_eagle_pinout
L2: BEAD; R0603
PAD1, PAD2, PAD3, PAD4: PAD-06
U23: MCP1703x-3302E/MB; SOT-89-3
VR4: 78E-3.3-0.5; RECOM-DCDC

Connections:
5VEXT: J1.1, L2.2 (4)
+3.3V: C8.1 (+), C41.1, C73.1, U23.2 (VI), VR4.3 (OUT); also elsewhere on the board
+12V: C3.1, C4.1 (+), D19.1 (C), J1.3, VR4.1 (IN); also elsewhere on the board
-12V: C47.2 (-), D13.2 (A); also elsewhere on the board
ADC-VDD: C10.1, C51.1, U23.3 (VO); also elsewhere on the board
AGND: PAD3.1; also elsewhere on the board
GNDADC: C10.2, C51.2, PAD1.1; also elsewhere on the board
LEDRING_VCC: C56.1 (+), C57.1, IC10.2 (OUT); also elsewhere on the board
unnamed: C75.1, IC10.3 (IN), J1.2
unnamed: D13.1 (C), J2.1, J2.2
unnamed: D19.2 (A), J2.9, J2.10
unnamed: J2.11, J2.12, L2.1
POWERHEADERCLK: J2.15, J2.16; also elsewhere on the board
POWERHEADERCVBUS: J2.13, J2.14; also elsewhere on the board

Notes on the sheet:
Sheet 6: Power
Connect GND and GNDADC on PCB
Connect GND and AGND on PCB

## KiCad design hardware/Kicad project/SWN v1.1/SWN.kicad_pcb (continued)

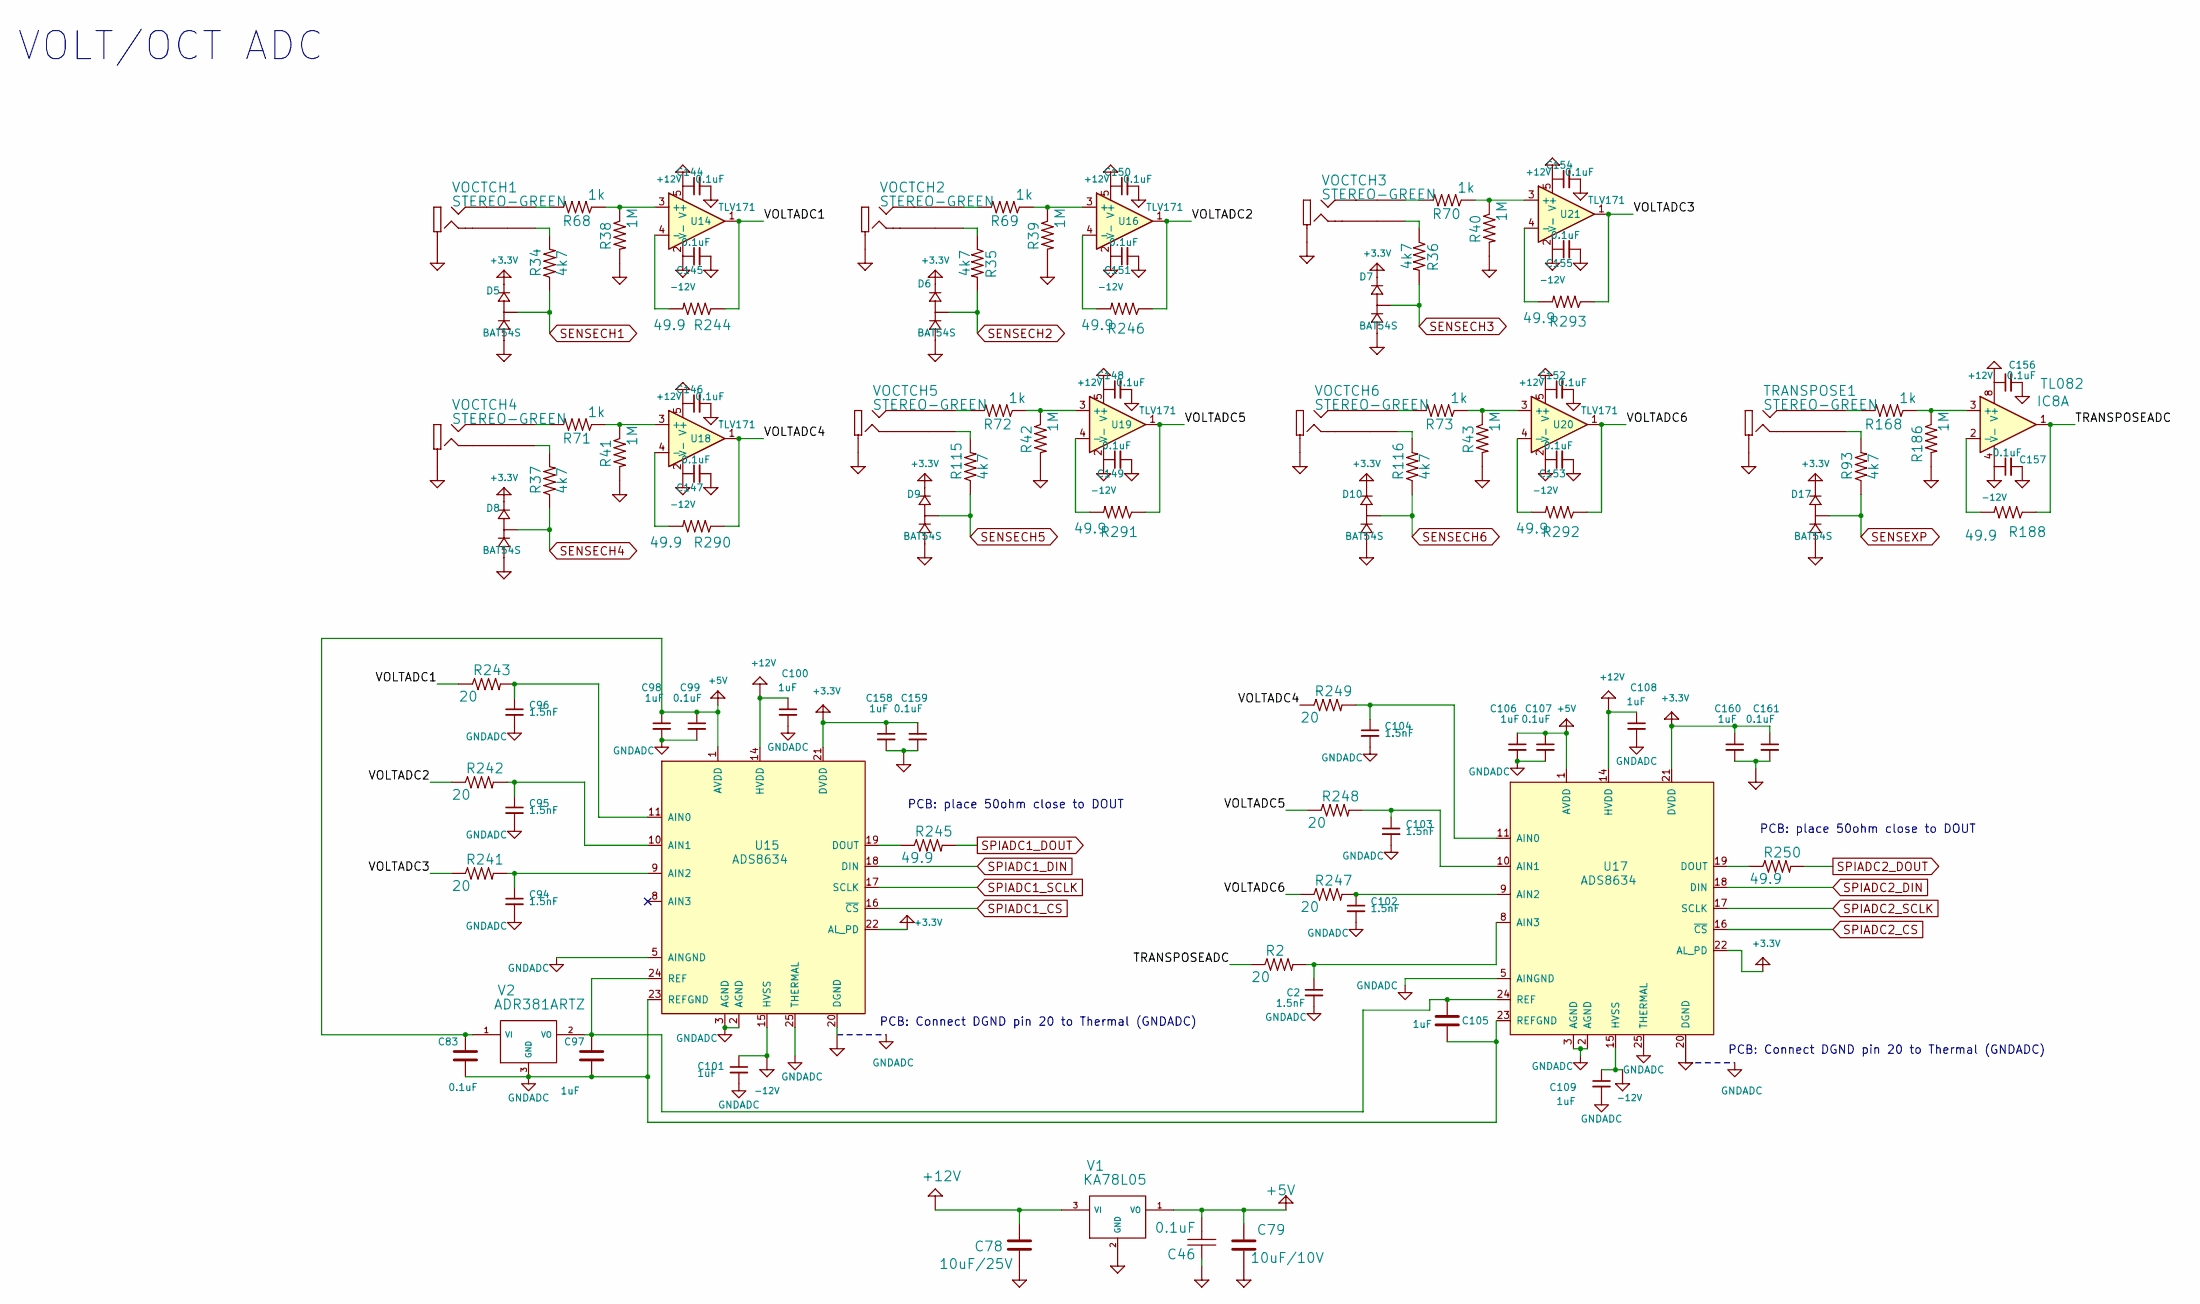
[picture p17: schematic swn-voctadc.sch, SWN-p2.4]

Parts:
C2, C94, C95, C96, C102, C103, C104: 1.5nF; C0603
C46, C83, C99, C107, C144, C145, C146, C147, C148, C149, C150, C151, C152, C153, C154, C155, C156, C157, C159, C161: 0.1uF; C0603
C78: 10uF/25V; C1206
C79: 10uF/10V; C0603
C97, C98, C100, C101, C105, C106, C108, C109, C158, C160: 1uF; C0603
D5, D6, D7, D8, D9, D10, D17: BAT54S; SOT23
IC8: TL082; TSSOP-8_4.4x3mm_Pitch0.65mm
R2, R241, R242, R243, R247, R248, R249: 20; R0603
R34, R35, R36, R37, R93, R115, R116: 4k7; R0603
R38, R39, R40, R41, R42, R43, R186: 1M; R0603
R68, R69, R70, R71, R72, R73, R168: 1k; R0603
R188, R244, R245, R246, R250, R290, R291, R292, R293: 49.9; R0603
TRANSPOSE1: STEREO-GREEN; PJ301M-12
U14, U16, U18, U19, U20, U21: TLV171; SOT-23-5
U15, U17: ADS8634; QFN-24-1EP_4x4mm_Pitch0.5mm
V1: KA78L05; SOT-89-3
V2: ADR381ARTZ; SOT23-3_PO132
VOCTCH1, VOCTCH2, VOCTCH3, VOCTCH4, VOCTCH5, VOCTCH6: STEREO-GREEN; PJ301M-12

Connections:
+3.3V: C158.1, C159.1, C160.1, C161.1, D5.2 (CATHODE), D6.2 (CATHODE), D7.2 (CATHODE), D8.2 (CATHODE), D9.2 (CATHODE), D10.2 (CATHODE), D17.2 (CATHODE), U15.21 (DVDD), U15.22 (AL_PD), U17.21 (DVDD), U17.22 (AL_PD); also elsewhere on the board
+5V: C46.2, C79.2, C83.1, C98.1, C99.1, C106.1, C107.1, U15.1 (AVDD), U17.1 (AVDD), V1.1 (VO), V2.1 (VI)
+12V: C78.1, C100.1, C108.1, C144.1, C146.1, C148.1, C150.1, C152.1, C154.1, C156.1, IC8.8 (V+), U14.5 (V+), U15.14 (HVDD), U16.5 (V+), U17.14 (HVDD), U18.5 (V+), U19.5 (V+), U20.5 (V+), U21.5 (V+), V1.3 (VI); also elsewhere on the board
-12V: C101.1, C109.1, C145.1, C147.1, C149.1, C151.1, C153.1, C155.1, C157.1, IC8.4 (V-), U14.2 (V-), U15.15 (HVSS), U16.2 (V-), U17.15 (HVSS), U18.2 (V-), U19.2 (V-), U20.2 (V-), U21.2 (V-); also elsewhere on the board
/V/OCT ADC/TRANSPOSEADC: IC8.1, R2.1, R188.1
/V/OCT ADC/VOLTADC1: R243.1, R244.1, U14.1
/V/OCT ADC/VOLTADC2: R242.1, R246.1, U16.1
/V/OCT ADC/VOLTADC3: R241.1, R293.1, U21.1
/V/OCT ADC/VOLTADC4: R249.1, R290.1, U18.1
/V/OCT ADC/VOLTADC5: R248.1, R291.1, U19.1
/V/OCT ADC/VOLTADC6: R247.1, R292.1, U20.1
GNDADC: C2.2, C83.2, C94.2, C95.2, C96.2, C97.2, C98.2, C99.2, C100.2, C101.2, C102.2, C103.2, C104.2, C105.2, C106.2, C107.2, C108.2, C109.2, U15.2 (AGND), U15.3 (AGND), U15.5 (AINGND), U15.23 (REFGND), U15.25 (THERMAL), U17.2 (AGND), U17.3 (AGND), U17.5 (AINGND), U17.23 (REFGND), U17.25 (THERMAL), V2.3 (GND); also elsewhere on the board
unnamed: C2.1, R2.2, U17.8 (AIN3)
unnamed: C94.1, R241.2, U15.9 (AIN2)
unnamed: C95.1, R242.2, U15.10 (AIN1)
unnamed: C96.1, R243.2, U15.11 (AIN0)
unnamed: C102.1, R247.2, U17.9 (AIN2)
unnamed: C103.1, R248.2, U17.10 (AIN1)
unnamed: C104.1, R249.2, U17.11 (AIN0)
unnamed: C97.1, C105.1, U15.24 (REF), U17.24 (REF), V2.2 (VO)
unnamed: IC8.2 (-), R188.2
unnamed: IC8.3 (+), R168.1, R186.1
unnamed: R34.2, VOCTCH1.3 (TIP-SW)
unnamed: R35.1, VOCTCH2.3 (TIP-SW)
unnamed: R36.1, VOCTCH3.3 (TIP-SW)
unnamed: R37.2, VOCTCH4.3 (TIP-SW)
unnamed: R38.1, R68.1, U14.3 (+)
unnamed: R39.1, R69.1, U16.3 (+)
unnamed: R40.1, R70.1, U21.3 (+)
unnamed: R41.1, R71.1, U18.3 (+)
unnamed: R42.1, R72.1, U19.3 (+)
unnamed: R43.1, R73.1, U20.3 (+)
unnamed: R68.2, VOCTCH1.1 (TIP)
unnamed: R69.2, VOCTCH2.1 (TIP)
unnamed: R70.2, VOCTCH3.1 (TIP)
unnamed: R71.2, VOCTCH4.1 (TIP)
unnamed: R72.2, VOCTCH5.1 (TIP)
unnamed: R73.2, VOCTCH6.1 (TIP)
unnamed: R93.2, TRANSPOSE1.3 (TIP-SW)
unnamed: R115.2, VOCTCH5.3 (TIP-SW)
unnamed: R116.2, VOCTCH6.3 (TIP-SW)
unnamed: R168.2, TRANSPOSE1.1 (TIP)
unnamed: R244.2, U14.4 (-)
unnamed: R245.1, U15.19 (DOUT)
unnamed: R246.2, U16.4 (-)
unnamed: R250.1, U17.19 (DOUT)
unnamed: R290.2, U18.4 (-)
unnamed: R291.2, U19.4 (-)
unnamed: R292.2, U20.4 (-)
unnamed: R293.2, U21.4 (-)
SENSECH1: D5.3 (COMMON), R34.1; also elsewhere on the board
SENSECH2: D6.3 (COMMON), R35.2; also elsewhere on the board
SENSECH3: D7.3 (COMMON), R36.2; also elsewhere on the board
SENSECH4: D8.3 (COMMON), R37.1; also elsewhere on the board
SENSECH5: D9.3 (COMMON), R115.1; also elsewhere on the board
SENSECH6: D10.3 (COMMON), R116.1; also elsewhere on the board
SENSEXP: D17.3 (COMMON), R93.1; also elsewhere on the board
SPIADC1_CS: U15.16 (~CS); also elsewhere on the board
SPIADC1_DIN: U15.18 (DIN); also elsewhere on the board
SPIADC1_DOUT: R245.2; also elsewhere on the board
SPIADC1_SCLK: U15.17 (SCLK); also elsewhere on the board
SPIADC2_CS: U17.16 (~CS); also elsewhere on the board
SPIADC2_DIN: U17.18 (DIN); also elsewhere on the board
SPIADC2_DOUT: R250.2; also elsewhere on the board
SPIADC2_SCLK: U17.17 (SCLK); also elsewhere on the board

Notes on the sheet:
VOLT/OCT ADC
PCB: place 50ohm close to DOUT
PCB: Connect DGND pin 20 to Thermal (GNDADC)

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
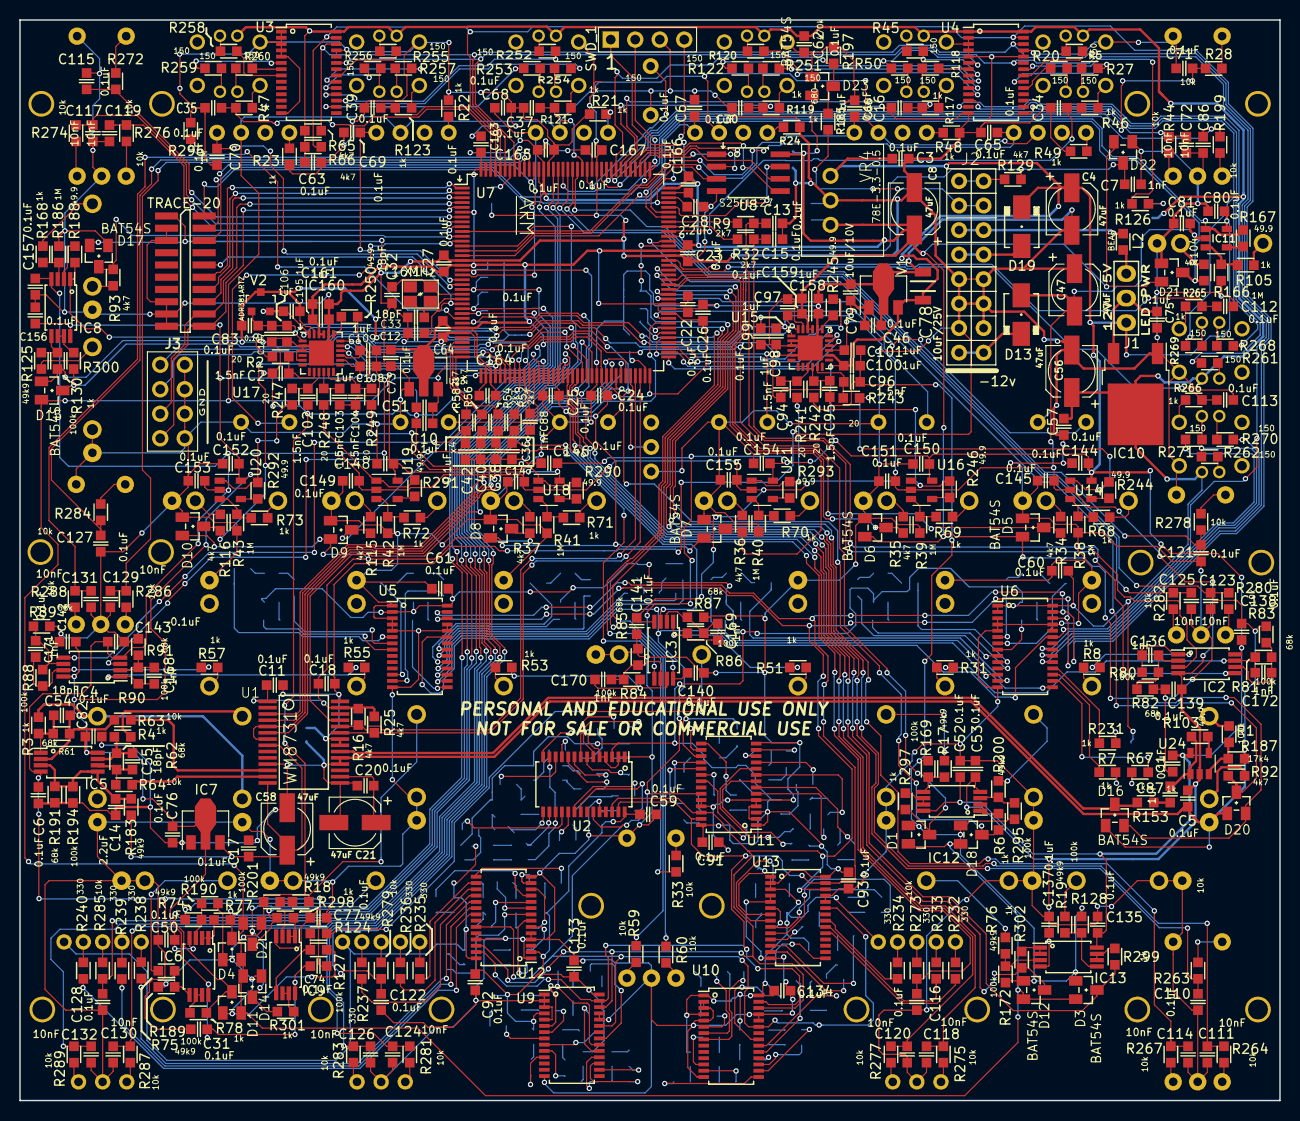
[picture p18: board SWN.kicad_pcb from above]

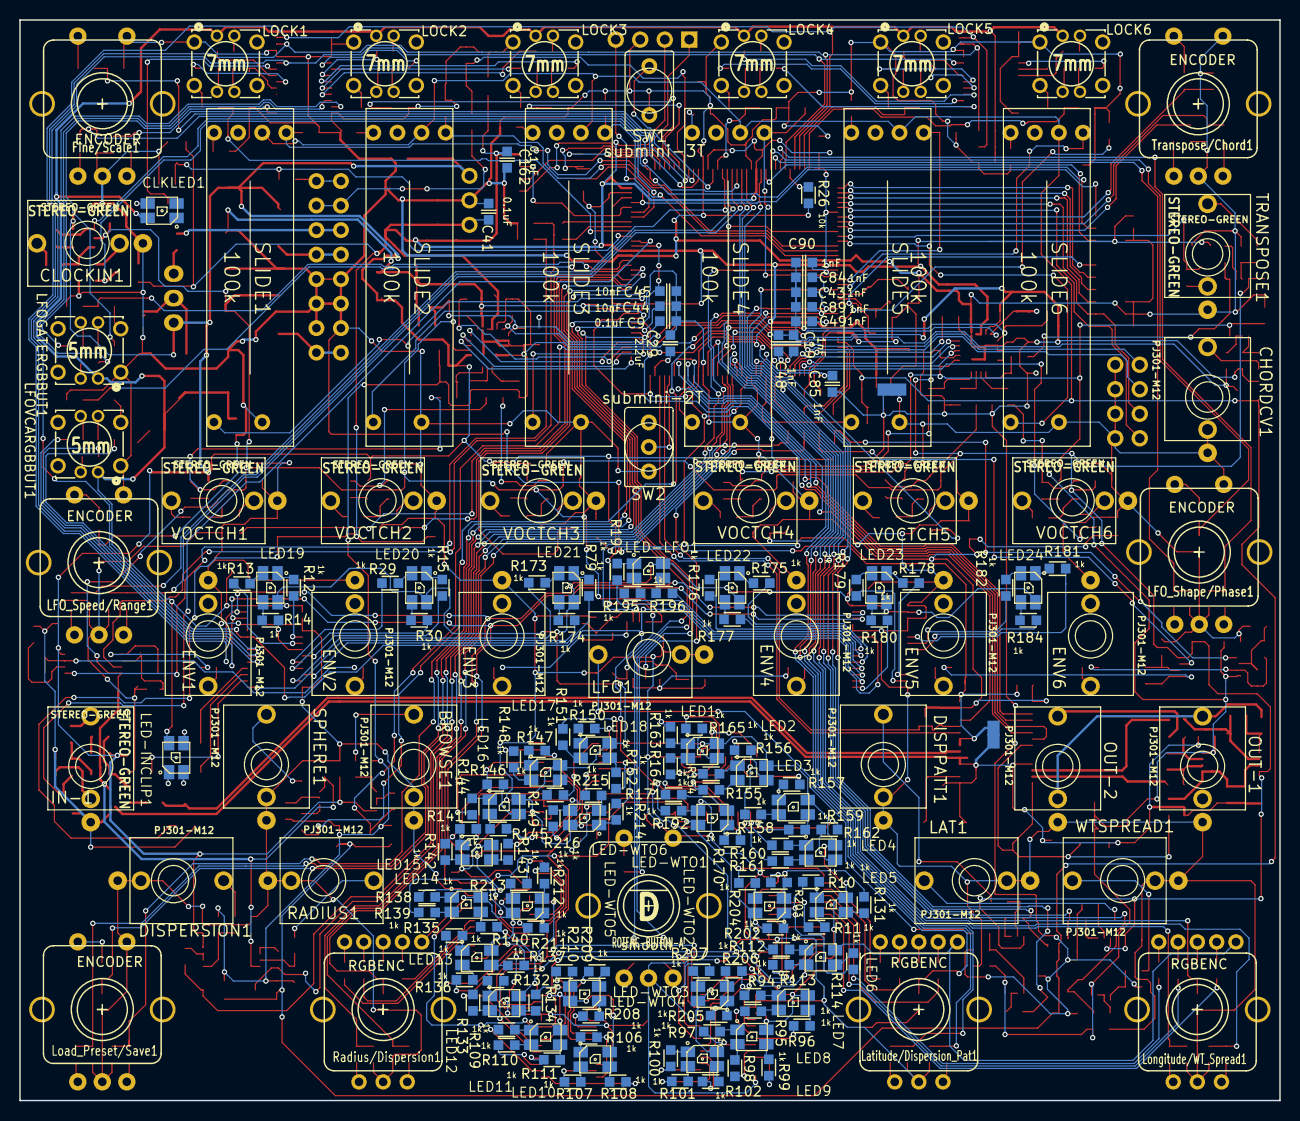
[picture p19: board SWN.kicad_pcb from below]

Board: 2 copper layers, 130.6 x 112.0 mm, 614 parts (196 on the bottom side), 552 nets.

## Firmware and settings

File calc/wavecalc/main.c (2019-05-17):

#include <stdio.h>
#include <stdarg.h>
#include <stdlib.h>
#include <string.h>
#include <sys/malloc.h>
#include <errno.h>
#include <ctype.h>
#include <sys/types.h>
#include <sys/stat.h>
#include <fcntl.h>
#include <time.h>
#include <math.h>
#include <unistd.h>
#include <sys/time.h>
#include <float.h>
#include <dirent.h> 


#ifndef M_PI
#define M_PI           3.14159265358979323846 
#endif

// GLOBAL
#define FILE_TABLELEN 		512 	// FixMe: This must be set to match the wav files read, but ideally should be detected in the wav file
#define	WT_DIM_SIZE	3
#define OSC_OUTPUT_TABLELEN 512
#define LFO_OUTPUT_TABLELEN 256


const char default_table_author[] 	= "Dan Green";
const char default_input_dir[] 		= "../libraries/wavefiles/";

const char default_spherename[] 	= "hp_lfo_ramp";
const char default_output_dir[] 	= "../libraries/spheres/";
const char default_osc_lfo[] 		= "OSC";


char do_smoothing 			= 0;
char do_remove_DC_offset 	= 0;
char do_cosine_window 		= 0;
char do_normalize 			= 0;
	
char DEBUG_PRINT_ALL_SAMPLES = 0;


uint16_t 	OUTPUT_TABLELEN;
float 		bitdepth_adj;
float 		bitdepth_gain;


// WAVE-FILES
#define HEADERLEN 312
#define NUM_WAV_WAVEFORMS 200 		// keep this number larger than the actual number of waveforms


// PLOTTING
#define NUM_COMMANDS 2
char plot_waveform[300];




// WAVE-FILE HEADER FORMAT
struct HEADER {
    unsigned char riff[4];                      // RIFF string
    unsigned int overall_size   ;               // overall size of file in bytes
    unsigned char wave[4];                      // WAVE string
    unsigned char fmt_chunk_marker[4];          // fmt string with trailing null char
    unsigned int length_of_fmt;                 // length of the format data
    unsigned int format_type;                   // format type. 1-PCM, 3- IEEE float, 6 - 8bit A law, 7 - 8bit mu law
    unsigned int channels;                      // no.of channels
    unsigned int sample_rate;                   // sampling rate (blocks per second)
    unsigned int byterate;                      // SampleRate * NumChannels * BitsPerSample/8
    unsigned int block_align;                   // NumChannels * BitsPerSample/8
    unsigned int bits_per_sample;               // bits per sample, 8- 8bits, 16- 16 bits etc
    unsigned char data_chunk_header [4];        // DATA string or FLLR string
    unsigned int data_size;                     // NumSamples * NumChannels * BitsPerSample/8 - size of the next chunk that will be read
};
struct HEADER header[200];
unsigned char buffer4[4];
unsigned char buffer2[2];


// WAVETABLE STRUCTURE
struct wavetable{
	 int16_t data[FILE_TABLELEN];
	 int coordinates[4];
	 char name[200];			// extend if names get truncated
	 int num_waveforms; 		// X, Y and Z.
	 int max_dimension;
	 int num_banks;
};

struct wavetable wavetable[NUM_WAV_WAVEFORMS];

// FUNCTIONS
void phasematch(float output[FILE_TABLELEN+1], float *buff[FILE_TABLELEN+1], int desired_first_sample);
// char* concat(const char *s1, const char *s2);
uint8_t add_slash(char *string);
uint8_t trim_slash(char *string);

void plot_wavetable(char plot_title[1024],int dof, float waveform[NUM_WAV_WAVEFORMS]);

void print_wavetable_to_file(char *filename, char *input_wav_dir, char *spherename, char *table_author, char *osc_lfo, struct wavetable wavetable[NUM_WAV_WAVEFORMS]);

void print_usage(void);

void print_usage(void)
{
	printf ("\
#########################	\n\
\twavecalc			\n\
#########################	\n\
Usage: \n\
wavecalc [input_wav_dir [output_dir [author[osc_lfo]]]]\n\
./wavecalc \"../libraries/2018_08_05_HP_BetaTest_LFO_BANKS/\" \"../libraries/spheres/\" \"Hugo Paris hugoplho@gmail.com\" \"OSC\" \n\
./wavecalc \"../libraries/2018_08_05_HP_BetaTest_LFO_BANKS/\" \"../libraries/spheres/\" \"Hugo Paris hugoplho@gmail.com\" \"LFO\" \n\
\n\
The spherename will be extracted from input_wav_dir.\n\
The output will be put into output_dir/spherename.h\n\
\n\
\n\
Default values:\n\
--------------\n\
input_wav_dir: %s%s\n\
output_dir: %s\n\
author: %s\n\
oscillator / lfo: %s\n\
\n\
\n\
After running wavecalc:\n\
----------------------\n\
1) Copy the .h file into the SWN folder inc/spheres/\n\
2) Add the following line to the top of SWN_PROJECT_DIR/inc/spheres_internal.h:\n\
\t#include \"spheres/spherename.h\"\n\
3) Add (void *)spherename inside the declaration for const void *wavetable_list[]={...} in spheres_internal.h\n\
\n\
\n\
"\
	, default_input_dir, default_spherename, default_output_dir, default_table_author, default_osc_lfo);
}

int main(int argc, char *argv[])
{
	int i;
	uint32_t j;
	int 		k 		= 0;
	int 		l 		= 0;
	int 		dof 	= 0; 			// degree of freedom: x,y,z
	int 		read 	= 0;
	float 		inc;	
	float 		sum_buf;
	float 		temp[FILE_TABLELEN];	
	float 		output[FILE_TABLELEN];
	float* 		buff[FILE_TABLELEN];
	uint32_t 	header_buf[HEADERLEN];
	uint32_t 	maxval_buf;
	char 		filename[256];
	FILE 		* ptr; 					//wav file pointer
	DIR 		*d;
	struct 		dirent 	*dir;
	char 		*input_wav_dir;
	char 		*output_filename;
	char 		*spherename;
	char 		*table_author;
	char		*test_str;
	char 		*osc_lfo;


	input_wav_dir = malloc(255);
	output_filename = malloc(255);
	spherename = malloc(255);
	table_author = malloc(255);
	osc_lfo = malloc(255);

	if (argc==1) {print_usage();}

	//Extract input dir from args, or use default
	if (argc>1 && argv[1][0]) {

		if (strcmp(argv[1], "help") == 0) {print_usage(); return 1;}

		strcpy(input_wav_dir, argv[1]);
		trim_slash(input_wav_dir);

		test_str = strrchr(input_wav_dir, '/');
		if (!test_str) {
			strcpy(spherename, argv[1]);
			strcpy(input_wav_dir, "./");
		} else {
			strcpy(spherename, test_str);
			spherename++;
			trim_slash(spherename);
			add_slash(input_wav_dir);
		}
	}
	else {
		strcpy(spherename, default_spherename);
		strcpy(input_wav_dir, default_input_dir);
		add_slash(input_wav_dir);
		strcat(input_wav_dir, spherename);
		add_slash(input_wav_dir);
	}	

	// Extract output dir from args, or use default
	if (argc>2 && argv[2][0]) { 
		strcpy(output_filename, argv[2]);
	}
	else {
		strcpy(output_filename, default_output_dir);
	}

	if (argc>3 && argv[3][0]) {
		strcpy(table_author, argv[3]);
	} else {
		strcpy(table_author, default_table_author);
	}

	if (argc>4 && argv[4][0]) {
		strcpy(osc_lfo, argv[4]);
	} else {
		strcpy(osc_lfo, default_osc_lfo);
	}


	add_slash(output_filename);
	if (strcmp (osc_lfo, "LFO") == 0){strcat(output_filename, "LFO_");}
	strcat(output_filename, spherename);
	strcat(output_filename, ".h");


	// OSCILLATOR // LFO
	if 		(strcmp (osc_lfo, "OSC") == 0){OUTPUT_TABLELEN = OSC_OUTPUT_TABLELEN; bitdepth_adj = 0.0; 	  bitdepth_gain = 1.0;}	
	else if (strcmp (osc_lfo, "LFO") == 0){OUTPUT_TABLELEN = LFO_OUTPUT_TABLELEN; bitdepth_adj = 126.0;   bitdepth_gain = 255.0 / 65535.0;}


	printf("\n\n\
Input wave dir: %s\n\
Sphere name: %s\n\
Output file: %s\n\
Author: %s\n\
oscillator / lfo: %s\n", input_wav_dir, spherename, output_filename, table_author, osc_lfo);


	// X-loop: filling up one row
	// Y-loop: then filling up another row on Y+=1 until columns are complete
	// Z-loop: move on to next layer (z+=1) until all layers are complete
	int cx=0;
	int cy=0;
	int cz=0;
	int cbank=0;


	// FIXME: ADD BACKUP BEFORE MOVING
		
	// REMOVE PREVIOUS WAVEFORM FILES FROM FOLDER
	//system("exec rm -r ../waveforms/*.h");

	// MAKE COSINE WINDOW
	float cosine_window[FILE_TABLELEN];
	for (i=0; i<FILE_TABLELEN; i++){
		cosine_window[i] = sin(i*M_PI/(FILE_TABLELEN-1)); 
		cosine_window[i] *= cosine_window[i]; 
	}
	
	//WIDEN COSINE WINDOW
	int cosine_gain = 100;
	for (i=0; i<FILE_TABLELEN; i++){
		cosine_window[i] *= cosine_gain;
		if (cosine_window[i] > 1){cosine_window[i]=1;}
	}

/*
	// PLOT WINDOW
						
		//Write data to temporary file
		FILE * gnuplotPipe = popen ("gnuplot -persistent", "w");
		for (i=0; i < FILE_TABLELEN; i++){
			fprintf(tempb, "%d %lf \n", i, cosine_window[i]); 
		}
	
		//Send commands to gnuplot one by one.
		for (i=0; i < NUM_COMMANDS; i++){
			fprintf(gnuplotPipe, "%s \n", commandsForGnuplot[i]); 
		}
*/


	// LARGEST WAVETABLE DIMENSION AVAILABLE
	// OPEN FOLDER
	d = opendir(input_wav_dir);
	if (d){
	
		// SCAN WAV-FILES IN FOLDER
		while ((dir = readdir(d)) != NULL){
		
			// SKIP OSX FILES 
			// osx-related files and non-wav
			char * end = strrchr(dir->d_name, '.');
			if ( (strcmp(dir->d_name,".") !=0 ) && (strcmp(dir->d_name,"..") !=0) && (strcmp(dir->d_name,".DS_Store") !=0)  && (strcmp(end, ".wav") == 0) ){
				l+=1;
			}
		}
	} else 
	{
		printf("\n\nError: input_wav_dir cannot be opened\n\n");
		exit(0);
	}

	wavetable[0].num_waveforms 		= l;
	// wavetable[0].max_dimension	= (int)(cbrt(wavetable[0].num_waveforms));

	wavetable[0].max_dimension	= WT_DIM_SIZE;
	wavetable[0].num_banks	= (int)(l / (wavetable[0].max_dimension * wavetable[0].max_dimension * wavetable[0].max_dimension));

	l=0;
	printf("\n\n#####################################################################");
	printf("\n input: %s ", input_wav_dir);
	printf("\n output: %s \n", output_filename);
	printf("\n %u WAV files available", wavetable[0].num_waveforms);
	printf("\n Maximum wavetable dimensions: %u x %u x %u", wavetable[0].max_dimension, wavetable[0].max_dimension, wavetable[0].max_dimension);
	printf("\n Number of banks: %u \n", wavetable[0].num_banks);
	printf("#####################################################################\n\n");
	closedir(d);
	
			
	// OPEN FOLDER
	d = opendir(input_wav_dir);
	if (d){
	
		// SCAN WAV-FILES IN FOLDER
		while ((dir = readdir(d)) != NULL){
		
			// SKIP OSX FILES 
			// osx-related files and non-wav
			char * end = strrchr(dir->d_name, '.');
			if ( (strcmp(dir->d_name,".") !=0 ) && (strcmp(dir->d_name,"..") !=0) && (strcmp(dir->d_name,".DS_Store") !=0)  && (strcmp(end, ".wav") == 0) ){
			
				// ASSIGN COORDINATES
				wavetable[l].coordinates[0]=cx;
				wavetable[l].coordinates[1]=cy;
				wavetable[l].coordinates[2]=cz;
				wavetable[l].coordinates[3]=cbank;
				printf("--------------------------------");
				printf("(%d: %d%d%d)",wavetable[l].coordinates[3],wavetable[l].coordinates[0],wavetable[l].coordinates[1],wavetable[l].coordinates[2]);
				printf("--------------------------------\n");		

				// SAVE FILE NAME AS WAVEFORM NAME
				strcpy(wavetable[l].name, dir->d_name);
				printf("FILE: \n%s\n\n", dir->d_name);

				//LOAD CONTENT FROM WAV
				//open wav files
				sprintf(filename, "%s/%s", input_wav_dir, dir->d_name);
				ptr = fopen(filename, "r");
				if (ptr == NULL) {
					printf("Error opening file\n");
				}

				// READ HEADER
				// 44 bytes <=> 352 bits)	
				// code from: http://truelogic.org/wordpress/2015/09/04/parsing-a-wav-file-in-c/
				 printf("HEADER: \n");
				 read = fread(header[k].riff, sizeof(header[k].riff), 1, ptr);
				 printf("(1-4): %s \n", header[k].riff); 

				 read = fread(buffer4, sizeof(buffer4), 1, ptr);
				 printf("%#x %#x %#x %#x\n", buffer4[0], buffer4[1], buffer4[2], buffer4[3]);

				 // convert little endian to big endian 4 byte int
				 header[k].overall_size  = buffer4[0] | 
										  (buffer4[1]<<8) | 
										  (buffer4[2]<<16) | 
									  	  (buffer4[3]<<24);

				 printf("(5-8) Overall size: bytes:%u, Kb:%u \n", header[k].overall_size, header[k].overall_size/1024);

				 read = fread(header[k].wave, sizeof(header[k].wave), 1, ptr);
				 printf("(9-12) Wave marker: %s\n", header[k].wave);

				 read = fread(header[k].fmt_chunk_marker, sizeof(header[k].fmt_chunk_marker), 1, ptr);
				 printf("(13-16) Fmt marker: %s\n", header[k].fmt_chunk_marker);

				 read = fread(buffer4, sizeof(buffer4), 1, ptr);
				 printf("%#x %#x %#x %#x\n", buffer4[0], buffer4[1], buffer4[2], buffer4[3]);

				 // convert little endian to big endian 4 byte integer
				 header[k].length_of_fmt =   buffer4[0] |
											(buffer4[1] << 8) |
											(buffer4[2] << 16) |
											(buffer4[3] << 24);
				 printf("(17-20) Length of Fmt header: %u \n", header[k].length_of_fmt);

				 read = fread(buffer2, sizeof(buffer2), 1, ptr); printf("%#x %#x \n", buffer2[0], buffer2[1]);

				 header[k].format_type = buffer2[0] | (buffer2[1] << 8);
				 char format_name[10] = "";
				 if (header[k].format_type == 1)
				   strcpy(format_name,"PCM"); 
				 else if (header[k].format_type == 6)
				  strcpy(format_name, "A-law");
				 else if (header[k].format_type == 7)
				  strcpy(format_name, "Mu-law");

				 printf("(21-22) Format type: %u %s \n", header[k].format_type, format_name);

				 read = fread(buffer2, sizeof(buffer2), 1, ptr);
				 printf("%#x %#x \n", buffer2[0], buffer2[1]);

				 header[k].channels = buffer2[0] | (buffer2[1] << 8);
				 printf("(23-24) Channels: %u \n", header[k].channels);

				 read = fread(buffer4, sizeof(buffer4), 1, ptr);
				 printf("%#x %#x %#x %#x\n", buffer4[0], buffer4[1], buffer4[2], buffer4[3]);

				 header[k].sample_rate = buffer4[0] |
										(buffer4[1] << 8) |
										(buffer4[2] << 16) |
										(buffer4[3] << 24);

				 printf("(25-28) Sample rate: %u\n", header[k].sample_rate);

				 read = fread(buffer4, sizeof(buffer4), 1, ptr);
				 printf("%#x %#x %#x %#x\n", buffer4[0], buffer4[1], buffer4[2], buffer4[3]);

				 header[k].byterate  = buffer4[0] |
									  (buffer4[1] << 8) |
									  (buffer4[2] << 16) |
									  (buffer4[3] << 24);
				 printf("(29-32) Byte Rate: %u , Bit Rate:%u\n", header[k].byterate, header[k].byterate*8);

				 read = fread(buffer2, sizeof(buffer2), 1, ptr);
				 printf("%u %u \n", buffer2[0], buffer2[1]);

				 header[k].block_align = buffer2[0] |
									(buffer2[1] << 8);
				 printf("(33-34) Block Alignment: %u \n", header[k].block_align);

				 read = fread(buffer2, sizeof(buffer2), 1, ptr);
				 printf("%u %u \n", buffer2[0], buffer2[1]);

				 header[k].bits_per_sample = buffer2[0] |
									(buffer2[1] << 8);
				 printf("(35-36) Bits per sample: %u \n", header[k].bits_per_sample);

				 read = fread(header[k].data_chunk_header, sizeof(header[k].data_chunk_header), 1, ptr);
				 printf("(37-40) Data Marker: %s \n", header[k].data_chunk_header);

				 read = fread(buffer4, sizeof(buffer4), 1, ptr);
				 printf("%#x %#x %#x %#x\n", buffer4[0], buffer4[1], buffer4[2], buffer4[3]);

				 header[k].data_size = buffer4[0] |
									  (buffer4[1] << 8) |
									  (buffer4[2] << 16) | 
									  (buffer4[3] << 24 );
				 printf("(41-44) Size of data chunk: %u \n", header[k].data_size);
			
				 // calculate no.of samples
				 long num_samples = (8 * header[k].data_size) / (header[k].channels * header[k].bits_per_sample);
				 printf("Number of samples:%lu \n", num_samples);

				 long size_of_each_sample = (header[k].channels * header[k].bits_per_sample) / 8;
				printf("Size of each sample:%ld bytes\n\n", size_of_each_sample);
			
				// READ ONE WAVETABLE LENGHT WORTH OF WAVEFILE
				// read each sample from data chunk if PCM
				printf("DATA:");
				if (header[k].format_type == 1) { // PCM
					long i =0;
					int a=0;
					int b=0;
					int size_is_correct = 1;

					// make sure that the bytes-per-sample is completely divisible by num.of channels
					long bytes_in_each_channel = (size_of_each_sample / header[k].channels);
					if ((bytes_in_each_channel  * header[k].channels) != size_of_each_sample) {
						printf("Error: %ld x %ud <> %ld\n", bytes_in_each_channel, header[k].channels, size_of_each_sample);
						size_is_correct = 0;
					}
					else printf("bytes_in_each_channel = %ld\n", bytes_in_each_channel);

					// unsigned char data_buffer[bytes_in_each_channel];
					unsigned char data_buffer[24];

					if (size_is_correct) { 
						// the valid amplitude range for values based on the bits per sample
						long low_limit = 0l;
						long high_limit = 0l;

						switch (header[k].bits_per_sample) {
							case 8:
								low_limit = -128;
								high_limit = 127;
								break;
							case 16:
								low_limit = -32768;
								high_limit = 32767;	//0x7FFF
								break;
							case 24:
								low_limit = -8388608;
								high_limit = 8388607; //0x7FFFFF
							break;
							case 32:
								low_limit = -2147483648;
								high_limit = 2147483647; //0x7FFFFFFF
								break;
							}
						printf("\nValid range for data values : %ld to %ld \n", low_limit, high_limit);
					
						// Skip 10x table lenght worth of samples 
						// skips attack and potential blanks
						// for (i =0; i < 10*FILE_TABLELEN; i++) {
						// 	read = fread(data_buffer, sizeof(data_buffer), 1, ptr);
						// }
					
						// read one table length worh of samples
						// FIXME: repeat this section a couple times

						unsigned int  xchannels = 0;
						int data_in_channel = 0;
						uint8_t data_in_channel_8=0;

						for (i =0; i < FILE_TABLELEN; i++) {

							for (xchannels = 0; xchannels < header[k].channels; xchannels ++ ) {
								read = fread(data_buffer, bytes_in_each_channel, 1, ptr);
 								// printf("channel %d of %d\n",xchannels, header[k].channels);

								if (read == 1){
	
									// dump the data read for 1 channel
									if (xchannels == 0){

										// convert data from little endian to big endian based on bytes in each channel sample
										// converts to signed integer with sample file's native bit-depth

										if (bytes_in_each_channel == 4) {
											data_in_channel =	(int32_t)
																(data_buffer[0] 		| 
																(data_buffer[1] << 8) 	| 
																(data_buffer[2] << 16) 	| 
																(data_buffer[3] << 24) );

											if (DEBUG_PRINT_ALL_SAMPLES) printf("%02x%02x%02x%02x = %d\n", data_buffer[3], data_buffer[2], data_buffer[1], data_buffer[0], data_in_channel);
										}
										else if (bytes_in_each_channel == 3) {
											data_in_channel = (int32_t)
																((data_buffer[0] <<8)	|
																(data_buffer[1] << 16) 	| 
																(data_buffer[2] << 24) );

											data_in_channel = data_in_channel/(1<<8); //32 to 24 bit conversion

											if (DEBUG_PRINT_ALL_SAMPLES) printf("%02x%02x%02x = %d\n", data_buffer[2], data_buffer[1], data_buffer[0], data_in_channel);
										}
										else if (bytes_in_each_channel == 2) {
											data_in_channel = (int16_t)
																(data_buffer[0] 		| 
																(data_buffer[1] << 8) );

											if (DEBUG_PRINT_ALL_SAMPLES) printf("%02x%02x = %d\n", data_buffer[1], data_buffer[0], data_in_channel);
										}
										else if (bytes_in_each_channel == 1) {
											data_in_channel_8 = (uint8_t) data_buffer[0];
											data_in_channel = data_in_channel_8 - 128;
											if (DEBUG_PRINT_ALL_SAMPLES) printf("%02x = %d = %d\n", data_buffer[0], data_in_channel_8, data_in_channel);
										}
								
										if (data_in_channel < low_limit || data_in_channel > high_limit){
											if (DEBUG_PRINT_ALL_SAMPLES) printf("**value out of range\n");
										}

										// convert signed integer in sample file's native bit depth to our wavetable bit-depth
										// We're using 16-bit signed ints for now:
										//
										if (bytes_in_each_channel == 4) {
											wavetable[l].data[b]=(int16_t)(data_in_channel/32768);
										} else if (bytes_in_each_channel == 3) {
											wavetable[l].data[b]=(int16_t)(data_in_channel/256);
										} else if (bytes_in_each_channel == 2) {
											wavetable[l].data[b]=(int16_t)(data_in_channel);
										} else if (bytes_in_each_channel == 1) {
											wavetable[l].data[b]=(int16_t)(data_in_channel*256);
										}

										//float:
										// wavetable[l].data[b]=data_in_channel;

										// apply OSC/LFO mode gain
										wavetable[l].data[b] = (uint16_t)((float)(wavetable[l].data[b]) * bitdepth_gain + bitdepth_adj) ;
										if 		((wavetable[l].data[b]<0)  	 && (strcmp (osc_lfo, "LFO") == 0)){wavetable[l].data[b] = 0;}
										else if ((wavetable[l].data[b]>255)  && (strcmp (osc_lfo, "LFO") == 0)){wavetable[l].data[b] = 255;}

										b+=1;

									}

								}else {
									printf("Error reading file. %d bytes %ld sizeof(data_buffer)\n", read, sizeof(data_buffer));
									break;
								}
							}
						} 
						printf("- Stereo -> Mono\n");

					} 

				}
				else{
					printf("ERROR: Not PCM \n");
				}	
			


//					plot_wavetable("RAW",wavetable[l].data);

				if (do_smoothing){
					// SMOOTHING:
					// LINEAR INTERPOLATION FOR NEAR-ZERO SAMPLES
					for (j=0; j<10; j++){
						for (i=0; i<FILE_TABLELEN; i++){
							if (((abs(wavetable[l].data[i]))<1000)&&
								(i!=0) && (i<FILE_TABLELEN-1)){
								wavetable[l].data[i] = (wavetable[l].data[i-1] + wavetable[l].data[i+1])/2;
							}
						}	
					}
// 						plot_wavetable("SMOOTH",wavetable[l].data);
				}
							
				if (do_remove_DC_offset){			
					// DETECT DC OFFSET
					sum_buf=0;
					for (i=0; i<FILE_TABLELEN; i++){
						sum_buf += wavetable[l].data[i];
					}
				}

				if (do_cosine_window){
					// APPLY WINDOW
					for (i=0; i<FILE_TABLELEN; i++){
						wavetable[l].data[i] *= cosine_window[i];
					}
// 						plot_wavetable("WINDOW",wavetable[l].data);
				}

				if (do_remove_DC_offset){			
					// REMOVE DC OFFSET
					for (i=0; i<FILE_TABLELEN; i++){
						wavetable[l].data[i] -= (sum_buf/FILE_TABLELEN);
					}
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

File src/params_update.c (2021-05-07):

/*
 * params_update.c - Parameters
 *
 * Authors: Dan Green (danngreen1@gmail.com), Hugo Paris (hugoplho@gmail.com)
 *
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
 * See http://creativecommons.org/licenses/MIT/ for more information.
 *
 * -----------------------------------------------------------------------------
 */


#include "params_update.h"
#include "params_changes.h"
#include "led_cont.h"
#include "gpio_pins.h"
#include "exp_1voct_10_41V.h"
#include "flash_params.h"
#include "math.h"
#include "sphere_flash_io.h"
#include "lfo_wavetable_bank.h"
#include "quantz_scales.h"
#include "led_cont.h"
#include "adc_interface.h"
#include "analog_conditioning.h"
#include "UI_conditioning.h"
#include "timekeeper.h"
#include "system_settings.h"
#include "math_util.h"
#include "params_wt_browse.h"
#include "quantz_scales.h"
#include "wavetable_recording.h"
#include "wavetable_editing.h"
#include "ui_modes.h"
#include "key_combos.h"
#include "wavetable_saveload.h"
#include "wavetable_effects.h"
#include "preset_manager.h"
#include "preset_manager_UI.h"
#include "params_pitch.h"
#include "params_lfo_clk.h"
#include "params_lfo_period.h"
#include "params_lfo.h"
#include "flash_params.h"
#include "ui_modes.h"
#include "oscillator.h"
#include "wavetable_saveload_UI.h"
#include "drivers/flashram_spidma.h"
#include "wavetable_play_export.h"
#include "preset_manager_selbus.h"

extern o_wt_osc wt_osc;
extern enum UI_Modes ui_mode;
extern o_lfos lfos;
extern SystemCalibrations *system_calibrations;


extern enum UI_Modes ui_mode;
extern	o_systemSettings	system_settings;
extern	o_analog	analog[NUM_ANALOG_ELEMENTS];
extern	o_macro_states macro_states;
extern	o_rotary	rotary[NUM_ROTARIES];
extern	o_button	button[NUM_BUTTONS];
extern	o_switch	hwSwitch[NUM_SWITCHES];
extern	o_monoLed 	monoLed[NUM_MONO_LED];
extern	o_led_cont	led_cont;

extern uint8_t audio_in_gate;

extern const uint8_t ALL_CHANNEL_MASK;

extern	SRAM1DATA o_spherebuf spherebuf;
extern const int16_t TTONE[WT_TABLELEN];

const int8_t		CHORD_LIST[NUM_CHORDS][NUM_CHANNELS] =
{
	// DEFAULT
	{ 0 	, 0 	, 0 	, 0 	, 0 	, 0		}  , 	// NONE

	// FIFTH
	{ 0 	, 0 	, 7 	, 7 	, 0 	, 0		}  , 	// FIFTH
	{ 0 	, 0 	, 7 	, 7 	, -5 	, -5	}  , 	// FIFTH w/ inversion
	{ 0 	, 12	, 7	, 19	, -12	, -5	}  , 	// FIFTH w/ oct

	// MAJOR
	{ 0 	, 0 	, 4 	, 4 	, 7 	, 7		}  , 	// M3rd
	{ -8	, -5	, 0 	, 4 	, 7 	, 7	}  ,	// M3rd w inv
	{ -12	, -5	, 0 	, 4 	, 7 	, 12	}  ,	// M3rd w/ oct

	// MINOR
	{ 0 	, 0 	, 3 	, 3 	, 7 	, 7		}  , 	// m3rd
	{ -9	, -5	, 0 	, 3 	, 7 	, 7	}  ,	// m3rd w inv
	{ -12	, -5	, 0 	, 3 	, 7 	, 12	}  ,	// m3rd w/ oct

	// MAJOR EXT chords (6th, 7th 9th, 11th)
	{ 0 	, 0 	, 4 	, 4 	, 7 	, 9		}  , 	// M6th
	{ -12 	, 0 	, 4 	, 7 	, 9 	, 9		}  , 	// M6th w/oct
	{ -12 	, -3	, 0 	, 4 	, 4 	, 9		}  , 	// M6th w/ inv
	{ 0 	, 0 	, 4 	, 4 	, 7 	, 11	}  , 	// M7th
	{ -12 	, 0 	, 4 	, 7 	, 11 	, 11	}  , 	// M7th w/oct
	{ -12 	, -1	, 0 	, 4 	, 7 	, 11	}  , 	// M7th w/ inv
	{ 0 	, 0		, 4 	, 7 	, 11	, 14	}  , 	// M9th
	{ 0 	, 4		, 7 	, 11 	, 14	, 18	}  , 	// M11th

	// MINOR EXT chords (6th, 7th 9th, 11th)
	{ 0 	, 0 	, 3 	, 3 	, 7 	, 9		}  , 	// m6th
	{ -12 	, 0 	, 3 	, 7 	, 9 	, 9		}  , 	// m6th w/oct
	{ -12 	, -3	, 0 	, 3 	, 3 	, 9		}  , 	// m6th w/ inv
	{ 0 	, 0 	, 3 	, 3 	, 7 	, 10	}  , 	// m7th
	{ -12 	, 0 	, 3 	, 7 	, 10 	, 10	}  , 	// m7th w/oct
	{ -12 	, -2	, 0 	, 3 	, 7 	, 10	}  , 	// m7th w/ inv
	{ 0 	, 0		, 3 	, 7 	, 10	, 14	}  , 	// m9th
	{ 0 	, 3		, 7 	, 10 	, 14	, 17	}   	// m11th
};

const float DISP_PATTERN[NUM_DISPPAT][6][3] =	{
	{
		{1,	1,      1},
		{1,  	1,		1},
		{1,  	1,   	1},
		{1,		1,  	1},
		{1,  	1,		1},
		{1,  	1,   	1},
	},
	{
		{1,	0,      0},
		{0,  	1,		0},
		{0,  	0,  	1},
		{-1,	0,  	0},
		{0,  	-1,	0},
		{0,  	0,   	-1},
	},
	{
		{0.50,	1.30,	0.80},
		{1.20,	-.30,	0.60},
		{0.80,	1.30,	-1.2},
		{0.50,	0.20,	1.50},
		{-2.0,	0,		0.30},
		{1.0,	0.20,	0.30},
	},
	{
		{-1.2,	0.30,	0.60},
		{2.00,	1.30,	1.20},
		{0.50,	0.30,	0.80},
		{2.00,	2.00,	0.30},
		{0.10,	0.20,	1.20},
		{0.50,	0.20,	-1.5},
	},
	{
		{-2,	0.30,	0.60},
		{-0.20, -1,	1.2},
		{2,	2,		.80},
		{-2,	-1.50,	0.30},
		{1,	2,		1.2},
		{0.30,	-2,	-1.50},
	},
	{
		{1,	-3,	2},
		{-2,  	2,		.40},
		{-1.50,	.40,   1.2},
		{0.1,	2,  	-2},
		{1.90,	-2,	-.80},
		{0.20,	.90,   -1}
	}
};

extern const float exp_1voct_10_41V[4096];

o_params			params;
o_calc_params		calc_params;

uint32_t num_spheres_filled;
o_waveform	waveform[NUM_CHANNELS][2][2][2];
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

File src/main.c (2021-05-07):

/*
 * main.c - Spherical Wavetable Navigator main
 *
 * Author: Dan Green (danngreen1@gmail.com)
 *
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
 * See http://creativecommons.org/licenses/MIT/ for more information.
 *
 * -----------------------------------------------------------------------------
 */


//Set to 0 if no bootloader (must also change the .ld file to load into 0x08000000 instead of 0x08010000)
//Set to 1 if there is a bootloader
#define HAS_BOOTLOADER 1
#define HAS_INTERNAL_FLASH 1

#include <stm32f7xx.h>

#include "drivers/codec_i2c.h"
#include "drivers/codec_sai.h"
#include "audio_util.h"
#include "gpio_pins.h"
#include "globals.h"
#include "oscillator.h"
#include "envout_pwm.h"
#include "params_update.h"
#include "flash_params.h"
#include "led_cont.h"
#include "led_colors.h"
#include "adc_interface.h"
#include "drivers/leds_pwm.h"
#include "timekeeper.h"
#include "drivers/mono_led_driver.h"
#include "hardware_tests.h"
#include "hal_handlers.h"
#include "sphere_flash_io.h"
#include "system_settings.h"
#include "preset_manager.h"
#include "preset_manager_UI.h"
#include "preset_manager_selbus.h"
#include "compressor.h"
#include "ui_modes.h"
#include "quantz_scales.h"
#include "calibrate_voct.h"
#include "params_lfo.h"
#include "led_color_adjust.h"
#include "sphere.h"
#include "wavetable_recording.h"
#include "wavetable_editing.h"
#include "wavetable_saveload.h"
#include "analog_conditioning.h"
#include "UI_conditioning.h"
#include "drivers/flashram_spidma.h"
#include "sel_bus.h"



//Private functions:
void SystemClock_Config(void);
void SetVectorTable(uint32_t reset_address);

extern enum 	UI_Modes ui_mode;

extern SystemCalibrations *system_calibrations;

int main(void)
{
	uint32_t valid_fw_version;

	//SCB->SHCSR |= SCB_SHCSR_USGFAULTENA_Msk | SCB_SHCSR_BUSFAULTENA_Msk | SCB_SHCSR_MEMFAULTENA_Msk; // enable Usage-/Bus-/MPU Fault

	//
	// System Init: Interrupt vector table location, HAL (systick) and System Clocks
	//
	SetVectorTable(HAS_BOOTLOADER ? 0x00210000 : 0x00200000);

	HAL_Init();
	SystemClock_Config();
	//FLASH_OB_BootAddressConfig(OPTIONBYTE_BOOTADDR_0, OB_BOOTADDR_ITCM_FLASH);

	SCB_DisableICache(); //not needed because we're running from FLASH on the ITCM bus, using ART and Prefetch

	SCB_InvalidateDCache();
	SCB_EnableDCache();

	__HAL_RCC_DMA2_CLK_DISABLE();

	// Setup PLL clock for codec
   	init_SAI_clock(SAMPLERATE);

   	//De-init the codec to force it to reset
    codec_deinit();
	HAL_Delay(80);

	// INITIALIZATIONS

	set_gpio_map();
	init_gpio_pins();

	if (key_combo_enter_hardwaretest() || !is_hardwaretest_already_done() || FORCE_HW_TEST)
	{
		do_hardware_test();
		while(1){;} //force reboot after hw test
	}

	init_timekeeper();

	init_pwm_leds();

	HAL_Delay(80);

	selBus_Init();

	// Initialize starting values
	init_color_palette();
	init_led_cont();
	init_led_cont_ongoing_display();
	clear_lfo_locks();
	use_internal_lfo_base();
	init_lfos();
	init_encoders();
	init_lfo_to_vc_mode();

	//External FLASH
	sFLASH_init();


	//Initialize param values (do not start updating them yet)
	init_wt_osc();
	init_params();
	init_pitch_params();
	init_quantz_scales();

	cache_uncache_keys_params_and_lfos(0, CACHE);
	cache_uncache_keys_params_and_lfos(1, CACHE);
	cache_uncache_keys_params_and_lfos(2, CACHE);
	cache_uncache_keys_params_and_lfos(3, CACHE);
	cache_uncache_keys_params_and_lfos(4, CACHE);
	cache_uncache_keys_params_and_lfos(5, CACHE);

	//Start outputing on the PWM OUT jacks
	init_envout_pwm();

	//start displaying mono leds
	start_monoled_updates();

	init_sphere_flash();

#ifdef ERASE_ALL_WAVETABLES
	for (uint8_t ww=0; ww<12; ww++)
		sFLASH_erase_sector( sFLASH_get_sector_addr(WT_SECTOR_START+ww) );
#endif

#ifdef CLEAR_USER_SPHERES_FROM_FLASH
	empty_all_user_spheres();
#endif

	if (key_combo_reload_factory_spheres())
		write_factory_spheres_to_extflash();

#ifdef FORCE_WRITE_FACTORY_SPHERES
	write_factory_spheres_to_extflash();
#endif

	// Load system_calibrations from internal flash if it's present
	if (HAS_INTERNAL_FLASH)
	{
		valid_fw_version = load_flash_params();

		if (!valid_fw_version)
		{
			factory_reset_all_calibrations();
			factory_reset();
			write_factory_spheres_to_extflash();
		}
	}
	else
		factory_reset_all_calibrations();

	restore_factory_spheres_to_extflash();

	read_all_spheretypes();
	update_number_of_user_spheres_filled();

	// Init ADC
	adc_init_all(); //starts hi-res ADC reading timers

	//Start LPF and bracketing for adcs: (must occur after loading flash, since it uses the system_calibration values)
	setup_analog_conditioning();
	start_analog_conditioning();

	//Keep this here for now until we develop a way to calibrate the plugged/unplugged jack default values
	set_default_cv_jack_calibration_offsets();

	//Start updating params (encoders, buttons, flip switches)
	start_UI_conditioning_updates();

	HAL_Delay(800);

	if (check_enter_led_adjust_mode())
	{
		enter_led_adjust_mode();

		while (!check_exit_led_adjust_mode())
		{
			process_led_color_adjust_mode();
			read_cv_jack_calibration_unplugged_offsets();
		}

		exit_led_adjust_mode();
	}

	init_preset_manager();

	//Show Firmware version
	display_firmware_version();
	HAL_Delay(4000);

	//Start updating oscillator parameters and wavetable
	start_osc_updates();
	start_osc_interp_updates();
	force_all_wt_interp_update(); 	// do first wavetabe interpolation (initializes routine's static variables)

	//Start LFO outputs
	start_envout_pwm();

	init_compressor(COMPRESS_SIGNED_24BIT, 0.90);

	ui_mode = PLAY;

	//Start Codec
	codec_GPIO_init();
	init_audio_DMA(SAMPLERATE);
	codec_I2C_init();
	codec_register_setup(SAMPLERATE);

	//init_wt_edit_settings();

	//Start audio processing
	set_audio_callback(&process_audio_block_codec);
	start_audio();

	start_led_display();

	selBus_Start();

	while(1){
		read_freq();

		read_switches();
		update_osc_param_lock();
		read_selbus_buttons();
		check_ui_mode_requests();

		read_load_save_encoder(); // Call from main loop because it can initiate a preset load/save call to sFLASH. If this is moved to an interrupt, then make sure it's lower priority than WT_INTERP
		check_sel_bus_event();	// FixMe: call from more adequate location (should be updated at about the data rate)

		if (ui_mode == VOCT_CALIBRATE) process_voct_calibrate_mode();

	} //end main loop

	return(0);

} //end main()
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

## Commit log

2019-05-17 First public commit
    [SWN.kicad_pcb, SWN.sch, formant_table.xlsx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]
2019-05-18 Updated LICENSE, README, and removed 4ms logos from PCB
    [SWN.kicad_pcb]
2019-05-20 Fixed LED brightness not properly showing wt_pos in WT_EDIT mode
    [params_update.c]
2019-05-20 Fixed issue where loading a preset containing a scale would not refresh the channel pitches
    [params_update.c, params_update.h]
2019-05-20 Transpose display shows mutes on buttons. Shorter timeout for display
    [params_update.h]
2019-05-20 Analog conditioning and hires ADC read is faster to prevent zippering
2019-07-12 External ADC runs purely on interrupt instead of dedicated timer
2019-07-12 Removed remnants of old timer for external ADCs
2019-07-12 Octave parameter is clamped to active range (0-MAXOCT) and spacing is preserved
    Enforcing a hard clamp of -MAX_OCT to MAX_OCT*2 so
2019-07-12 LED display for octave tweaked
2019-07-12 Using the same timer for all lock flashing
2019-07-12 New display: Sphere Selection
    Displays wt_sel on buttons and outer ring as a sphere is selected or WT Spread is applied. Tapping center rotary enables the display
2019-07-12 Using common function for rotating led ring origin
2019-07-12 Cleaned up encoder led color logic: now they are always orange in WT REC mode
2019-07-12 Fixed FX display in WT EDIT mode (push and turn on rotary went to spheresel)
    [params_update.c]
2019-07-12 Locks display in proper spot on led ring
    Massive whitespace cleanup on led_cont
2019-07-12 WIP setting up DMA for I2C of PCA chips
2019-07-12 WIP: DMA of I2C
2019-07-12 Updated HAL I2C to latest, trying to get DMA to show that it's ready after xmit
2019-07-12 Implemented double buffer, not sure if it's needed. I2C DMA works but seems to be colliding with extflash reads
    [leds_pwm.c, pca9685_driver.c, pca9685_driver.h]
2019-07-12 Higher priority to I2C EV IRQ fixed timeout from ext flash spi interrupting it.
    Also found double buffer to be unneccessary and removed. And fixed bug in single LED set function
    [leds_pwm.c, pca9685_driver.c]
2019-07-12 WIP with SPI DMA
2019-07-12 removed unused CODEC RESET pin defs (conflict with SPI FLASH pin)
2019-07-12 SPI Flash can read on DMA
2019-07-12 WT Interp utilizes DMA for reading wavetables. Much faster now.
    Browse's LPF is too heavy now.
    [params_update.c]
2019-07-12 Separated SPIDMA functions from non-DMA SPI, and from chip specific defs
2019-07-12 Fixed issue where only first channel would update wt_bank
    [params_update.c]
2019-07-12 Fixed issue with only first channel loading wt from flash
    [params_update.c]
2019-07-12 Preset writes/reads to flash using DMA-friendly memory
2019-07-12 Using DMA-friendly memory for writing spheres. WIP: Broken!
2019-07-12 Fixed bug where WTEDIT would not refresh waveform at 0,0,0
    [params_update.c]
2019-07-12 Disable/Enable Spheres. Clear/Unclear Spheres. Load Sphere in WTREC
    Disabled/Enabled spheres is saved in Preset. Cleared spheres can be uncleared until power down.
2019-07-12 Fixed SPI DMA collision when loading a preset while browsing
2019-07-12 Fixed LFOs/KeyMode/wt_sel/nav changing when going in and out of WTREC
    [params_lfo.c, params_lfo.h, params_update.c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]
2019-07-12 Sphere Selection displays better on buttons in note/key mode
    Also reverted a change so that now sphere sel and wtpos can be changed for locked channels using channel button
    [params_update.c]
2019-07-12 Key combo change: Pset+Dep+Lat = reset Nav; Pset+Long = reset wt sel
    ...
    [params_update.c]
2019-07-12 LFO CV bug fixed (high then low CV would break LFO speed)
    [params_lfo.c, params_lfo.h]
2019-07-12 Allow Note Mode envelopes to be very short
    Running your finger up a scale on a CV keyboard now triggers every note
2019-07-12 External Trig mode: New Key Switch mode uses CV jacks for triggers to fire envelopes
    In the process of adding, finished removing extra monitor code from oscillator main codec processing
    [params_update.c, params_update.h]
2019-07-12 Removed support for PCB_VERSION <= 23
2019-07-12 Finished removing support for PCB_VERSION <= 23
2019-07-12 Using raw ADC for CV jack gate detection allows for detecting thinner pulses
2019-07-12 Track pitch in EXT TRIG mode so we're more accurate to the CV source
    Otherwise if there's slew or noise we might latch a bad value for pitch
    [params_update.c]
2019-07-12 Fixed CV effecting locked channels.
    [params_update.c]
2019-07-12 Calibrate Voct mode turns off LFO to VCA, unmutes all and enters mute mode
2019-07-12 Switching to Mute mode goes to Semitones, not Major scale.
2019-07-12 Switching to CV/Gate goes to unquantized scale
2019-07-12 Fixed bug with Locks toggling when adjusting a channel's fine params
    Mute mode: lock would toggle if unmuting/muting after adjusting a channel button+fine+knob
    Other modes: lock would toggle immediately
    [params_update.c]
2019-07-12 WTSEL has even spacing, not a LUT (Re-commited accidentally reverted commit)
    [params_update.c]
2019-07-12 Turned off Debug pin output
2019-07-15 Spread knob wrapped improperly when going from 0 to -1
    Was skipping last chord
    [params_update.c]
2019-07-15 Chord list fixed: minor 3rd, minor and major 9th and 11th had some wrong notes
    [params_update.c]
2019-07-16 Fixed Chord 6, from sus4 to M3. Bumped to v2.1
    [params_update.c]
2019-09-05 Updated bootloader with correct name of non-DMA LED init function
    [bootloader.cc]
2019-09-05 Schematic symbol library alias created for F765 chip
    Symbol changed to F765 in schematic
    [SWN.sch]
2019-09-05 Schematic updated to use KiCad 5.1.4 and new 4ms-vreg library.
    [SWN.sch, swn-audio.sch, swn-channels.sch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]
2020-05-28 Spheres are loaded after hardware test, before boot.
    Reduces risk of power-cycling corrupting a flash load.
    On boot, if a factory sphere is detected as missing, it's reloaded
    [bootloader.cc, main.c, params_update.c]
2020-09-16 Fix Sphere CV being modulated when in Gate mode
    [params_update.c]
2020-09-16 Fixed deprecated use of sp clobbering
    set_MSP was clobbering stack pointer, which is no longer allowed in gcc >9.1.
    [bl_utils.c, main.c]
2020-09-16 Buttons in CV/Gate/Sus mode can sustain, just like jacks
    Fixed bug where Sphere CV jack didn't work in CV/Gate mode
    [params_update.c]
2020-09-16 Fixed issue where Preset knob didn't ever display
    And preset mode exits if selbus key combos detected
    [params_update.c]
2021-05-07 Reverting back to ITCM, and disabling ICache
    [main.c]
2021-05-07 Fixed fine-tuning not applying immediately when preset is loaded.
    [params_update.c]
2022-01-25 Fixes #3: hangs when run after compiling with arm-none-eabi-gcc v7.3.1
    Debugging showed that const data (in the .rodata section) was corrupted. Data that should be found at a particular address was actually four bytes prior. The DMA init in `DMA_CalcBaseAndBitshift()` would freeze because it uses a static array `flagBitshiftOffset`, which had corrupted data.
    The problem was that the linker script allowed the LMA and VMA counters to get out of sync. Adding the ALIGN_WITH_INPUT flag fixed this. See: https://sourceware.org/binutils/docs-2.35/ld/Forced-Output-Alignment.html
